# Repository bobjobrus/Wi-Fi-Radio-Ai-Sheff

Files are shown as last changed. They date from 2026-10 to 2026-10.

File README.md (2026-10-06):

**Русский** · [English](README.en.md)

# Wi-Fi Radio Ai-Sheff

**English summary.** Wi-Fi Radio Ai-Sheff is an open-source, battery-powered push-to-talk walkie-talkie built on
an ESP32-S3 DevKitC-1 with an INMP441 I2S microphone, a MAX98357A I2S amplifier, a 12-LED WS2812 ring, a KY-040
volume knob and an 18650 cell in a 3D-printed case. Radios join any 2.4 GHz Wi-Fi network and talk to each other
through a small *bridge* — a Python 3 server (two files, standard library only) that runs on a cheap VPS
or an always-on PC (Linux, Windows, macOS) — so the range is limited only by where there is Wi-Fi with internet.
Speech is 16 kHz IMA ADPCM; every packet is signed and the audio is AES-128-CTR encrypted with a shared network key,
and the bridge forwards speech without decrypting it. Radios update their firmware over the air from the bridge,
cancel acoustic howling between radios in the same room, and are configured from a phone through their own
`RADIO-XXXX` access point. Two bridges can be linked so that each site keeps working on its own LAN.
Full English documentation: [README.en.md](README.en.md). Code comments are in Russian. License: MIT.

---

## Что это

Переносная рация «нажал — говоришь» на плате ESP32-S3. Кнопка одна: нажали, услышали короткое «пи-пи»,
говорите, отпустили — все остальные рации вашей сети вас услышали.

Рации не связываются друг с другом напрямую. Каждая подключается к обычному Wi-Fi — дома, в офисе, на раздаче
с телефона, — а речь передаёт через **мост**: маленькую программу на компьютере, который всегда включён и доступен
из интернета. Поэтому рации в разных городах слышат друг друга так же, как в соседних комнатах: **дальность
ограничена только тем, где есть Wi-Fi с интернетом**.

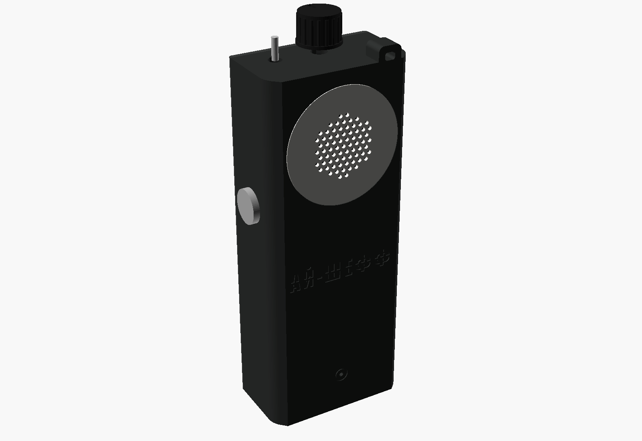
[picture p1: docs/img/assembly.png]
Рация в корпусе: динамик за белым диском, вокруг светится кольцо; кнопка «говорить» на боку, регулятор громкости и выключатель сверху


Корпус 68 × 38 × 170 мм печатается на 3D-принтере без поддержек. Спереди — динамик за белым диском, сквозь
который светится кольцо из 12 светодиодов; на боку — кнопка «говорить»; сверху — регулятор громкости и выключатель;
снизу — гнездо зарядки USB-C.

## Возможности

- **Одна кнопка «говорить».** Говорит один человек за раз: мост отдаёт эфир тому, кто нажал первым, остальные
  при нажатии слышат «бу-бу-бу» («занято»). Залипшую кнопку мост отключает через 90 секунд.
- **Рации в разных Wi-Fi-сетях** — дом, офис, склад, дача, раздача с телефона. Рация запоминает до трёх сетей
  и подключается к той, что ловит лучше. Нужен Wi-Fi 2,4 ГГц: сети 5 ГГц ESP32-S3 не видит.
- **Шифрование ключом сети.** Ключ сети — общий пароль всех ваших раций и мостов, строка вида
  `XXXX-XXXX-XXXX-XXXX`. Каждый пакет подписан этим ключом, речь зашифрована (AES-128). Чужая рация или случайный
  сканер из интернета в эфир не попадут. Мост речь не расшифровывает — только пересылает.
- **Обновление прошивки по воздуху через мост.** Положили новый файл прошивки в папку моста — каждая рация,
  простояв 20 секунд без разговоров, скачает его, сверит контрольную сумму (sha256 — «отпечаток» файла) и только
  тогда перезапустится на новую версию. Трогать рации руками не нужно.
- **Защита от свиста.** Если две рации лежат рядом, звук может пойти по кругу и засвистеть — как микрофон, поднесённый
  к колонке. Прошивка сама находит частоту свиста и вырезает её узким фильтром.
- **Индикация кольцом.** Кольцо вокруг динамика показывает связь, кто говорит, громкость, заряд и ход обновления.
  Что значит каждый цвет — в таблице [«Цвета кольца»](docs/TROUBLESHOOTING.md#цвета-кольца).
- **Оценка заряда** аккумулятора 18650: шкала на кольце, сигнал «пора на зарядку», процент на странице рации и на
  странице моста. Просадки напряжения во время разговора не дают ложных тревог.
- **Настройка с телефона.** Новая рация открывает свою точку доступа Wi-Fi `RADIO-XXXX`. Подключились к ней
  телефоном — страница настройки открывается сама, как в гостинице: Wi-Fi, адрес моста, ключ сети, имя рации,
  громкость, яркость.
- **Страница моста:** какие рации в сети, у кого сколько заряда, кто сейчас говорит, журнал событий. Мост сам
  подсказывает неисправности: «в передаче одна тишина — проверьте микрофон», «не тот ключ сети?».
- **Мост — программа на Python** без сторонних библиотек (два файла: `walkie_hub.py` и `wt_proto.py`): работает
  на Linux, Windows и macOS. Есть готовые
  установщики службы для Linux (systemd, с самопроверкой раз в 2 минуты) и для Windows (Планировщик заданий).
- **Звук:** 16 кГц, сжатие IMA ADPCM 4 бита — около 86 кбит/с на одного говорящего, хватает и мобильного интернета.
  Приёмник копит 60–160 мс речи, чтобы сгладить рывки сети.

## Как это работает

Рация шлёт речь кусочками по 20 мс в мост. Мост решает, кто сейчас в эфире, и пересылает речь всем остальным
рациям. Связь всегда начинает рация, поэтому настраивать роутеры у раций не нужно — входящие порты должны быть
открыты только у моста: **UDP 47000** (связь с рациями) и **TCP 47080** (страница состояния и раздача прошивки).

```
   Дом                                                               Офис
 ┌─────────┐  Wi-Fi  ┌────────┐                     ┌────────┐  Wi-Fi  ┌─────────┐
 │ рация 1 │ ~~~~~~~ │ роутер │───┐             ┌───│ роутер │ ~~~~~~~ │ рация 2 │
 └─────────┘         └────────┘   │  интернет   │   └────────┘         └─────────┘
                                  ▼             ▼
                            ┌───────────────────────┐
                            │         МОСТ          │  облачный сервер
                            │  UDP 47000 — рации    │  или компьютер
                            │  TCP 47080 — страница │  с постоянным адресом
                            └───────────────────────┘
                                          ▲
 ┌─────────┐  раздача Wi-Fi  ┌─────────┐  │
 │ рация 3 │ ~~~~~~~~~~~~~~~ │ телефон │──┘
 └─────────┘                 └─────────┘
```

Что происходит при нажатии кнопки:

1. Рация спрашивает мост: «можно говорить?». Эфир свободен — звучит «пи-пи», кольцо горит красным.
   Кто-то уже говорит — «бу-бу-бу», ждите.
2. Пока кнопка нажата, речь уходит в мост сжатой и зашифрованной.
3. Остальные рации играют её с небольшим запасом против рывков сети; их кольцо «пляшет» зелёным в такт голосу.
4. Отпустили кнопку — у остальных короткое «ти-ду»: передача закончена.

### Без облака

Мост можно поставить на компьютер в своей сети. Если поле «Адрес моста» в рации оставить пустым, рация сама найдёт
мост в своей сети широковещательным запросом (пакетом «всем в этой сети»).

```
 ┌───────┐  Wi-Fi  ┌────────┐     ┌──────────────┐
 │ рации │ ~~~~~~~ │ роутер │─────│ ПК с мостом  │    поле «Адрес моста» в рациях — пустое
 └───────┘         └────────┘     └──────────────┘
```

Если мест несколько, у каждого может быть свой мост, а мосты связываются между собой (поле `peers` в настройках
моста). Мостам нужно видеть друг друга по UDP 47000 — через интернет или через VPN (например, Tailscale или
WireGuard). Плюс такой схемы: внутри одного места рации говорят друг с другом даже при упавшем интернете.

```
 рации ~~~ [ мост «Дом» ] ◄═════ peers: интернет или VPN ═════► [ мост «Офис» ] ~~~ рации
```

Как выбрать и поднять мост — [docs/BRIDGE.md](docs/BRIDGE.md). Формат пакетов — [docs/protocol.md](docs/protocol.md).

## Что понадобится

| Деталь | Зачем |
|---|---|
| Плата ESP32-S3-DevKitC-1 N16R8 (или клон YD-ESP32-S3) | «мозг» рации и Wi-Fi |
| Микрофон INMP441 (цифровой, I2S) | голос |
| Усилитель MAX98357A (цифровой, I2S, 3 Вт) | усиливает звук для динамика |
| Динамик 8 Ом, 3 Вт, 32 × 32 мм | звук |
| Кольцо WS2812B на 12 светодиодов, Ø 50 мм | индикация |
| Регулятор KY-040 (вращающийся энкодер с кнопкой) | громкость; нажатие — выключить звук |
| Кнопка 16 мм (антивандальная) | «говорить» |
| Микротумблер | включение |
| Аккумулятор 18650 и держатель к нему | питание |
| Модуль заряда USB-C 5 В 2 А (типа «Power Bank Mini») | заряжает аккумулятор и даёт 5 В |
| Два резистора 100 кОм, диод 1N4007, две клеммы на 5 проводов, провода «мама-мама», термоусадка, саморезы 3 мм | делитель для измерения заряда, питание кольца, сборка |
| Корпус: ≈ 140 г PLA и белый диск динамика | печать на 3D-принтере, ≈ 6 ч |

**Цена одной рации — около 4 200 ₽** за детали и пластик, если собирать сразу три (одна рация отдельно — около
4 500 ₽: часть деталей продаётся наборами). Цены российских магазинов на сентябрь 2026. Точный список с количеством,
примерами «где можно купить» и размерами саморезов — в [docs/BUILD.md](docs/BUILD.md).

Ещё понадобятся паяльник, мультиметр (сильно упрощает поиск неисправностей), кабель USB-C **с передачей данных**
и компьютер, который будет мостом: недорогой облачный сервер или домашний ПК, который всегда включён.

Время работы от одного 18650 — по расчёту около 15 часов.

## Как собрать — по шагам

| Шаг | Где описано |
|---|---|
| 1. Купить детали, напечатать корпус, спаять и собрать | [docs/BUILD.md](docs/BUILD.md) — детали, печать, схема подключения ([wiring.svg](docs/img/wiring.svg)), раскладка в корпусе ([layout.svg](docs/img/layout.svg)) |
| 2. Поднять свой мост и придумать ключ сети | [docs/BRIDGE.md](docs/BRIDGE.md) |
| 3. Прошить рацию, ввести Wi-Fi, адрес моста и ключ, научиться пользоваться | [docs/SETUP.md](docs/SETUP.md) — готовая прошивка лежит в [firmware/dist/](firmware/dist/) |
| 4. Если что-то не работает | [docs/TROUBLESHOOTING.md](docs/TROUBLESHOOTING.md) — признак → причина → что делать |
| Для разработчиков: как устроены пакеты | [docs/protocol.md](docs/protocol.md) |

Совет: прошейте плату и проверьте её на столе **до** сборки в корпус — потом искать ошибку дольше.

## Что где лежит

| Папка / файл | Что внутри |
|---|---|
| [firmware/walkie/](firmware/walkie/) | прошивка рации (Arduino, ядро esp32 3.3.12). Выводы платы и основные числа — в [config.h](firmware/walkie/config.h) |
| [firmware/dist/](firmware/dist/) | готовая прошивка: `walkie-full-v9.bin` — первая прошивка целиком с адреса 0x0; `walkie.bin` + `walkie.json` — для раздачи через мост |
| [hub/walkie_hub.py](hub/walkie_hub.py) | мост; [wt_proto.py](hub/wt_proto.py) — протокол, [hub.example.json](hub/hub.example.json) — пример настроек |
| [hub/install_linux.sh](hub/install_linux.sh), [hub/install_windows.ps1](hub/install_windows.ps1) | установка моста службой на Linux и Windows |
| [hub/healthcheck.py](hub/healthcheck.py) | самопроверка моста (служебная «рация» стучится в мост) |
| [hub/sim_radio.py](hub/sim_radio.py) | программная рация на компьютере: проверить мост, передать тон или WAV, записать эфир, режим «попугай» |
| [tools/build_firmware.sh](tools/build_firmware.sh) | сборка прошивки через arduino-cli → `firmware/dist/` |
| [tools/flash.sh](tools/flash.sh) | первая прошивка по USB (macOS) |
| [tools/provision.py](tools/provision.py) | настройка рации по USB-кабелю: имя, мост, ключ, Wi-Fi (macOS; на Linux — с `--port`) |
| [tools/make_print.sh](tools/make_print.sh), [tools/bambu_profile.py](tools/bambu_profile.py) | нарезка корпуса в Bambu Studio под Bambu Lab P2S (macOS) |
| [tools/howl_eval.cpp](tools/howl_eval.cpp), [tools/howl_chain.cpp](tools/howl_chain.cpp) | стенды защиты от свиста: прогон по записям WAV и модель «петли» между рациями |
| [cad/radio_handheld.scad](cad/radio_handheld.scad) | модель корпуса в OpenSCAD (параметры — в шапке файла); [measurements.md](cad/measurements.md) — замеры деталей |
| [stl/](stl/) | готовые к печати детали корпуса |
| [tests/](tests/) | автоматические проверки моста, протокола и переносимой части прошивки |
| [docs/](docs/) | инструкции и картинки |

## Разработка

Проверки — без железа, около 30 секунд:

```bash
python3 -m unittest discover -s tests
```

Что проверяется (21 проверка): мост с «программными рациями» на настоящих UDP-сокетах — эфир, «занято», тишина,
отключение залипшей кнопки, чужой ключ, раздача прошивки, речь через два связанных моста, одновременное нажатие
в двух местах; шифр AES по эталонным векторам, подпись пакетов; совпадение констант протокола в прошивке и мосте.
Переносимые части прошивки (сжатие речи, буфер приёма, оценка заряда, защита от свиста) собираются компилятором
компьютера и проверяются своими тестами, а сжатие речи ещё и сверяется с эталоном на Python. Для этого нужен
`clang++` или `g++`, без них эти проверки пропускаются.

Сборка прошивки (нужен [arduino-cli](https://arduino.github.io/arduino-cli/); ядро esp32 3.3.12 скрипт поставит
сам):

```bash
tools/build_firmware.sh
```

Плата в сборке — «ESP32S3 Dev Module», флеш 4 МБ, разметка Minimal SPIFFS (два места под прошивку — нужно для
обновления по воздуху), PSRAM выключена, USB в режиме Hardware CDC. Подходит и платам с флешем 16 МБ.
Итог — в `firmware/dist/`.

Выпустить новую версию для всех раций:

1. Увеличьте `FW_VERSION` в [firmware/walkie/config.h](firmware/walkie/config.h) — мост раздаёт прошивку только
   с бо́льшим номером.
2. Соберите: `tools/build_firmware.sh`.
3. Скопируйте `firmware/dist/walkie.bin` и `firmware/dist/walkie.json` в папку `firmware/` рядом с `hub.json`
   на мосту. Мост подхватит их сам за 10 секунд — подробнее в [docs/BRIDGE.md](docs/BRIDGE.md).

Правила для тех, кто правит код:

- Протокол описан в двух местах — [firmware/walkie/protocol.h](firmware/walkie/protocol.h) и
  [hub/wt_proto.py](hub/wt_proto.py); менять их вместе (и описание в [docs/protocol.md](docs/protocol.md)),
  `tests/test_parity.py` сверяет константы.
- Сборка идёт без ctags, поэтому в `walkie.ino` функции объявляются **до** использования.
- Комментарии в коде — на русском.

## Лицензия

[MIT](LICENSE): можно использовать, менять и продавать, сохранив уведомление об авторских правах. Без гарантий.

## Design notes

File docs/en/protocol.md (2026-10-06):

[Русский](../protocol.md) · **English**

# The "WT1" radio protocol

A single UDP port on the bridge (default **47000**). The radio sends from its own port 47001.
Everything is little-endian. Code: `hub/wt_proto.py` (the reference) and `firmware/walkie/protocol.h` — **change them together**.

## Packet

```
'W' 'T' | version=1 (1) | type (1) | src (4) | data … | signature (8)
```

* `src` — the radio id (FNV-1a of the MAC) or the bridge id (sha256 of the bridge name).
* Signature — the first 8 bytes of HMAC-SHA256(k_auth, everything before the signature).
* Network key — a string like `K7Q2-MX9P-4RTA-W8HD`; case, spaces and hyphens don't matter.
  `k_auth = HMAC-SHA256(key, "wt1-auth")`, `k_enc = HMAC-SHA256(key, "wt1-enc")[:16]`.
* Exception: `BAD_KEY` (0x7F) — header only, no signature: this is how the bridge tells a radio
  that its signature didn't match ("wrong network key").

## Types

| Type | From → to | Data |
|---|---|---|
| `HELLO` 0x01 | radio → bridge, every 2 s (with no bridge — every 1 s, broadcast) | fw u16, flags u8 (1 = sound muted), rssi i8, t_ms u32, rtt u16, name (length u8 + UTF-8 ≤ 31), charge u8 (0–100 %, 255 — not on battery; optional) |
| `HELLO_ACK` 0x02 | bridge → radio | t_echo u32, radios on the network u8, bridges in the list u8, bridges online u8, channel busy u8, firmware version u16, size u32, sha256 32 bytes, http port u16, bridge name |
| `TALK_REQ` 0x10 | radio → bridge (repeated every 150 ms, for up to 700 ms) | burst u32 (random) |
| `TALK_GRANT` 0x11 | bridge → radio | burst u32 |
| `TALK_DENY` 0x12 | bridge → radio | burst u32, reason u8: 1 busy, 2 yield (simultaneous press), 3 held longer than 90 s, 4 the bridge doesn't know this radio |
| `TALK_END` 0x13 | radio → bridge (3 times); bridge → radios and bridges | burst u32; `src` = who was talking |
| `TALK_START` 0x14 | bridge → bridges | burst u32; `src` = who is talking |
| `AUDIO` 0x20 | radio → bridge → everyone | burst u32, seq u16, codec u8 (1), level u8, 163 bytes AES-128-CTR(k_enc) |
| `PEER_HELLO` 0x30 | bridge ↔ bridge, every 2 s | t_ms u32, t_echo u32, n u8, n × (id u32, flags u8, name), bridge name |

**Speech:** 16 kHz, 20 ms frame = 320 samples → 4-bit IMA ADPCM: `pred i16 | index u8 | 160 bytes`.
The encoder state is carried in every frame, so a lost packet doesn't corrupt the ones that follow.
AES-CTR counter: `src u32 | burst u32 | seq u16 | 6 zero bytes` (+1 for every 16 bytes, as in mbedtls).
The bridge doesn't decrypt speech: it forwards the packet as is.

## The channel (who is talking)

* The bridge gives the channel to whoever asked first; everyone else gets `DENY 1` and the busy tone.
* The channel is released on `TALK_END`, after 0.8 s without speech, or after 90 s (protection against a stuck button).
* Bridges pass `TALK_START`/`AUDIO` on to each other. If people in two places press at the same time,
  the **lower id** wins — identically on every bridge; the loser gets `DENY 2`.
* A bridge doesn't forward packets from one bridge to another (link the bridges as a "star" or as a full mesh, "each with each").

## Radio firmware updates

Put `firmware/walkie.bin` and `firmware/walkie.json` (`{"version": N}`) into the bridge's folder.
The bridge announces the version, size and sha256 in `HELLO_ACK`; the radio, after 20 s without any talking,
downloads `http://bridge:47080/fw/<first 16 characters of sha>.bin`, checks the sha256 and only then
switches to the new firmware. If it doesn't match — it retries in an hour.

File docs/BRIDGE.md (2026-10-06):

**Русский** · [English](en/BRIDGE.md)

# Свой мост

В публичной прошивке **адрес моста не задан**. Рации не услышат друг друга, пока вы не запустите
свой мост и не подключите их к нему. Здесь описано, как поднять мост на облачном сервере или на
домашнем компьютере, подключить к нему рации и обновлять их прошивку по воздуху.

Мост — это небольшая программа на Python (`hub/walkie_hub.py` и модуль `hub/wt_proto.py` рядом)
без дополнительных библиотек. Она одинаково работает на Linux, Windows и macOS.

**Содержание**

1. [Что такое мост и какой вариант выбрать](#1-что-такое-мост-и-какой-вариант-выбрать)
2. [Что понадобится](#2-что-понадобится)
3. [Ключ сети и токен страницы](#3-ключ-сети-и-токен-страницы)
4. [Установка на Linux-сервер](#4-установка-на-linux-сервер)
5. [Установка на Windows](#5-установка-на-windows)
6. [Подключение раций к мосту](#6-подключение-раций-к-мосту)
7. [Несколько мостов (поле peers)](#7-несколько-мостов-поле-peers)
8. [Страница состояния](#8-страница-состояния)
9. [Обновление прошивки по воздуху](#9-обновление-прошивки-по-воздуху)
10. [Проверка без раций](#10-проверка-без-раций)
11. [Безопасность](#11-безопасность)
12. [Если адрес сервера сменится](#12-если-адрес-сервера-сменится)
13. [Неполадки](#13-неполадки)

---

## 1. Что такое мост и какой вариант выбрать

Рации обычно стоят в разных Wi-Fi-сетях: дома, в офисе, на складе, в другом городе. Напрямую друг
друга они не видят. Каждая рация шлёт свои пакеты в мост, а мост:

- **решает, кто сейчас в эфире.** Первый нажавший получает эфир, остальные слышат сигнал «занято».
  Если кнопку держат дольше 90 секунд (по умолчанию), мост сам обрывает передачу (защита от залипшей
  кнопки);
- **пересылает речь** всем остальным рациям. Речь зашифрована ключом сети. Мост её не расшифровывает,
  а пересылает пакеты как есть;
- **раздаёт обновления прошивки.** Положили новый файл в папку моста, и рации обновятся сами;
- **показывает страницу состояния**: какие рации в сети, у кого сколько заряда, кто говорит, журнал
  событий.

Общаются рации с мостом по UDP. UDP — простой способ слать по интернету короткие пакеты без
установки соединения, для живого звука он подходит лучше всего.

### Три варианта

**А. Облачный сервер (VPS) — рекомендуемый.** VPS — это арендованный компьютер в дата-центре:
он всегда включён и доступен из интернета по постоянному адресу. В каждой рации вписан адрес
сервера, и рации работают из любой сети: дома, в офисе, через раздачу с телефона.

```
  Рация «Дом»      Рация «Офис»     Рация «Склад»
       \                |                /
        \___________ интернет __________/
                        |
          Мост на VPS: radio.example.com
```

**Б. Компьютер в той же сети, что рации.** Мост работает на обычном ПК дома или в офисе. Поле
«Адрес моста» в рациях остаётся **пустым**. Рация, у которой адрес не задан, сама ищет мост
в своей сети: рассылает приветствие всем устройствам сети (широковещательно) на порт 47000 и
запоминает тот мост, который ответил первым. Интернет не нужен. Но рации работают только в этой
сети, а компьютер должен быть всегда включён и не уходить в сон.

**В. Несколько мостов, связанных между собой.** У каждого места свой мост (вариант Б), и мосты
знают друг о друге через поле `peers` в настройках. Рация из одного места слышит рации из другого.
Мосты должны видеть друг друга по сети: через VPN (например, Tailscale), через проброс порта
в роутере или потому, что один из них стоит на VPS. Подробно — в разделе [7](#7-несколько-мостов-поле-peers).

| | А. VPS | Б. ПК в сети раций | В. Несколько мостов |
|---|---|---|---|
| Адрес моста в рации | адрес сервера | пусто | пусто (или адрес своего моста) |
| Рации в разных сетях | да | нет | да, между местами с мостами |
| Работает без интернета | нет | да | внутри одного места — да |
| Что должно быть включено | только сервер | ПК | все ПК с мостами |
| Расходы | аренда VPS | нет | нет (или VPS) |

Можно совмещать: мост на VPS для всех раций плюс мост в офисе, связанный с ним через `peers`
(см. [раздел 7](#7-несколько-мостов-поле-peers)).

---

## 2. Что понадобится

**Python 3.8 или новее.** Других пакетов не нужно, `pip install` делать не придётся. В Ubuntu и
Debian Python уже установлен (`/usr/bin/python3`). Для Windows скачайте его с python.org.

**Порты.** Порт — это номер «двери» на компьютере, через которую программа принимает пакеты.

| Порт | Протокол | Зачем | Где задан |
|---|---|---|---|
| **47000** | UDP | речь и служебные пакеты раций, связь мостов между собой | `port` в `hub.json` |
| **47080** | TCP | страница состояния и раздача прошивки рациям | `http_port` в `hub.json` |

Оба порта должны быть открыты на вход: и в брандмауэре самого компьютера, и (для VPS) в панели
провайдера. Рации сами шлют пакеты с порта 47001, открывать его на мосту не нужно.

**Постоянный адрес.** Рации знают мост по адресу. Если адрес сервера сменится, рации его потеряют
(см. [раздел 12](#12-если-адрес-сервера-сменится)). Поэтому нужен либо **статический IP-адрес**,
либо **доменное имя** (например, `radio.example.com`): рация понимает и цифровой адрес, и имя.

**IPv4.** Мост и рации работают только по IPv4. У некоторых дешёвых VPS есть только IPv6: такой не
подойдёт.

**Мощность.** Подойдёт самый маленький тариф VPS. Трафик тоже небольшой:

- в простое рация и мост обмениваются короткими пакетами раз в 2 секунды, это около 7 МБ в сутки
  на одну рацию;
- во время речи на каждую слушающую рацию уходит около 0,65 МБ в минуту (50 пакетов в секунду
  по 187 байт плюс заголовки сети).

---

## 3. Ключ сети и токен страницы

Придумайте их заранее: оба понадобятся при настройке моста.

### Ключ сети

Ключ сети — общий секрет всех раций и мостов одной сети. Им подписывается каждый пакет и шифруется
речь. Пакет с чужим ключом мост и рации просто выбрасывают.

Мост сам сгенерирует хороший ключ:

```bash
python3 hub/walkie_hub.py --genkey
```

Он напечатает строку вида `XXXX-XXXX-XXXX-XXXX`: 16 случайных знаков без похожих символов
(нет `0`/`O` и `1`/`I`).

Если придумываете ключ сами, соблюдайте правила:

- **не меньше 12 латинских букв и цифр.** Дефисы, пробелы и регистр не важны:
  `k7q2-mx9p…` и `K7Q2MX9P…` — один и тот же ключ;
- **только латиница и цифры.** Русские буквы прошивка рации пропускает, а мост учитывает, поэтому
  ключи разойдутся;
- **не длиннее 39 знаков** вместе с дефисами. Рация хранит не больше 39 знаков, и более длинный
  ключ она молча обрежет.

### Токен страницы состояния

Токен закрывает страницу состояния от посторонних: без него страница не откроется. Сгенерировать
его можно так:

```bash
python3 -c "import secrets; print(secrets.token_urlsafe(16))"
```

Используйте только латиницу, цифры, `-` и `_`, потому что токен будет частью адреса страницы.

---

## 4. Установка на Linux-сервер

Инструкция для Ubuntu и Debian. Ниже `203.0.113.10` — пример адреса сервера, а `ubuntu` — пример
имени пользователя. Подставьте свои.

### 4.1. Арендуйте сервер

Подойдёт любой провайдер VPS и самый маленький тариф с Ubuntu 22.04/24.04 или Debian 12.
При создании:

- **закажите статический (зарезервированный) публичный IPv4-адрес.** У многих провайдеров обычный
  адрес «плавающий» и меняется после остановки сервера;
- добавьте свой SSH-ключ, чтобы входить без пароля.

### 4.2. Откройте порты у провайдера

У большинства провайдеров есть свой сетевой фильтр («группа безопасности», «firewall», «правила
доступа»). Он работает отдельно от брандмауэра внутри сервера. Добавьте два входящих правила:

- UDP, порт **47000**, источник — любой (`0.0.0.0/0`);
- TCP, порт **47080**, источник — любой (`0.0.0.0/0`).

Правило для SSH (TCP 22) не удаляйте.

### 4.3. Скопируйте папку `hub` на сервер

Вариант 1: со своего компьютера, из корня этого проекта. Папки `walkie-hub` на сервере ещё не
должно быть:

```bash
scp -r hub ubuntu@203.0.113.10:~/walkie-hub
```

Вариант 2: на самом сервере, через `git clone` этого репозитория. Тогда папка моста — `hub`
внутри клона.

```bash
git clone <ссылка на этот репозиторий> ~/wifi-radio
# дальше вместо ~/walkie-hub используйте ~/wifi-radio/hub
```

В пути к папке не должно быть пробелов: установщик вписывает его в службу без кавычек.

### 4.4. Заполните `hub.json`

```bash
ssh ubuntu@203.0.113.10
cd ~/walkie-hub
cp hub.example.json hub.json
python3 walkie_hub.py --genkey                                  # ключ сети, если ещё нет
python3 -c "import secrets; print(secrets.token_urlsafe(16))"   # токен страницы
nano hub.json
```

Пример заполненного файла:

```json
{
  "name": "Облако",
  "port": 47000,
  "http_port": 47080,
  "key": "XXXX-XXXX-XXXX-XXXX",
  "peers": [],
  "status_token": "TOKEN",
  "tot_seconds": 90,
  "firmware_dir": "firmware",
  "log_file": "hub.log"
}
```

| Поле | Если не указано | Что значит |
|---|---|---|
| `name` | `Мост` | Имя моста. Его видно на странице рации и на странице состояния. Не длиннее 31 байта: это около 15 русских или 31 латинской буквы. **У каждого моста имя должно быть своё**: из имени вычисляется номер моста, и мосты с одинаковыми именами друг друга не видят. |
| `port` | `47000` | UDP-порт для раций. Для варианта Б оставьте 47000: рации ищут мост в сети только на этом порту. Если сменили, в рации пишите адрес с портом: `radio.example.com:47100`. |
| `http_port` | `47080` | TCP-порт страницы состояния и раздачи прошивки. Рации узнают его от моста сами. |
| `key` | — | **Обязательно.** Ключ сети из [раздела 3](#ключ-сети). Заглушку `ВСТАВЬТЕ-КЛЮЧ-СЕТИ` из примера замените: с ней мост запустится, но рации к нему не подключатся. Если ключ короче 12 знаков, мост не запустится. |
| `status_token` | пусто | Токен страницы состояния. Если пусто, страница открыта всем, кто знает адрес. |
| `tot_seconds` | `90` | Сколько секунд одна рация может держать эфир. Потом мост обрывает передачу. Рация и сама обрывает передачу через 100 секунд, поэтому ставить больше 100 нет смысла. |
| `peers` | `[]` | Другие мосты, с которыми связаться: `["адрес", "адрес:порт"]`. См. [раздел 7](#7-несколько-мостов-поле-peers). |
| `firmware_dir` | `firmware` | Папка для обновлений прошивки (`walkie.bin` + `walkie.json`). Путь считается от папки, где лежит `hub.json`. |
| `log_file` | `hub.log` | Журнал рядом с `hub.json`. Когда файл дорастает до 1 МБ, начинается новый, и хранятся 3 старых (`hub.log.1`…`hub.log.3`). Пустая строка `""` — не писать журнал в файл. |
| `listen` | `0.0.0.0` | На каком адресе компьютера слушать. В примере этого поля нет, и трогать его не нужно. `0.0.0.0` означает «на всех адресах». Самопроверка стучится на `127.0.0.1` и с другим значением не сработает. |

Файл должен быть правильным JSON: строки в двойных кавычках, между полями запятые, без запятой
после последнего поля, без комментариев.

### 4.5. Запустите установщик

```bash
cd ~/walkie-hub
sudo bash install_linux.sh
```

Что делает `install_linux.sh`:

1. Проверяет, что рядом есть `hub.json`. Если нет, останавливается с подсказкой.
2. Создаёт службу systemd **`walkie-hub`**. systemd — менеджер программ в Linux, который запускает
   их при включении сервера. Служба работает от вашего пользователя (не от root), запускает
   `python3 walkie_hub.py --config hub.json`, поднимается после перезагрузки сервера и
   перезапускается через 3 секунды, если программа упала.
3. Создаёт **самопроверку** `walkie-hub-check.timer`: через 3 минуты после включения, а потом раз
   в 2 минуты `healthcheck.py` шлёт мосту служебный пакет. Если мост не ответил (например, завис),
   служба перезапускается, а в системный журнал пишется «мост не ответил на самопроверку —
   перезапуск».
4. Если на сервере **включён** брандмауэр `ufw`, открывает в нём `47000/udp` и `47080/tcp`. Если
   `ufw` выключен, ничего не меняет и сам его не включает.
5. Запускает (или перезапускает) мост и показывает первые строки его состояния.

Скрипт можно запускать повторно, например после обновления файлов моста: он перезапишет службы и
перезапустит мост.

> Если `ufw` вы будете включать сами, сначала разрешите SSH (`sudo ufw allow OpenSSH`), иначе
> потеряете доступ к серверу. Если сменили порты в `hub.json`, откройте новые порты и в `ufw`, и
> у провайдера: установщик открывает только 47000 и 47080.

### 4.6. Проверьте

На сервере:

```bash
systemctl status walkie-hub             # должно быть active (running)
python3 healthcheck.py --config hub.json  # «мост отвечает»
tail -n 20 hub.log                      # «мост «Облако» запущен: UDP 47000, страница :47080, …»
```

Со своего компьютера откройте в браузере `http://203.0.113.10:47080/?t=TOKEN`. Должна открыться
страница «Мост раций «Облако»» с надписью «Ни одна рация сюда ещё не подключалась». Без `?t=…`
мост ответит «нужен ?t=<токен>».

Проверить, что UDP-порт открыт снаружи, можно программной рацией прямо со своего компьютера
(см. [раздел 10](#10-проверка-без-раций)):

```bash
python3 hub/sim_radio.py --hub 203.0.113.10 --key XXXX-XXXX-XXXX-XXXX status
```

### 4.7. Управление

```bash
sudo systemctl restart walkie-hub        # перезапуск, например после правки hub.json
sudo systemctl stop walkie-hub           # остановить
systemctl status walkie-hub              # состояние
journalctl -u walkie-hub -f              # журнал службы в реальном времени (выход — Ctrl+C)
tail -f ~/walkie-hub/hub.log             # тот же журнал из файла
journalctl -t walkie-hub                 # перезапуски по самопроверке
systemctl list-timers walkie-hub-check.timer
sudo systemctl disable --now walkie-hub walkie-hub-check.timer   # убрать из автозапуска
```

Мост читает `hub.json` только при запуске, поэтому после каждой правки нужен `restart`.

---

## 5. Установка на Windows

Подходит для варианта Б (ПК в сети раций) и В (мосты в разных местах).

1. Установите Python 3 с python.org. В установщике отметьте «Add python.exe to PATH» и оставьте
   включённым «py launcher».
2. Скопируйте папку `hub` в место без пробелов в пути, например `C:\walkie-hub`.
3. Скопируйте `hub.example.json` в `hub.json` и заполните его, как в [разделе 4.4](#44-заполните-hubjson).
   Подойдёт Блокнот, кодировка UTF-8. Ключ сгенерируйте так:
   ```powershell
   py -3 C:\walkie-hub\walkie_hub.py --genkey
   ```
4. Откройте **PowerShell от имени администратора** и запустите установщик:
   ```powershell
   powershell -ExecutionPolicy Bypass -File C:\walkie-hub\install_windows.ps1
   ```

Что делает `install_windows.ps1`:

- находит `pythonw.exe` (Python без чёрного окна) через PATH или через `py -3`;
- создаёт правила брандмауэра Windows «Мост раций UDP 47000» и «Мост раций TCP 47080» для всех
  типов сетей (доменной, частной, общественной). Старые правила с теми же именами сначала удаляет;
- регистрирует задачу Планировщика **`WalkieHub`**: запуск при включении компьютера (ещё до входа
  в систему, от имени SYSTEM), без окна, без ограничения по времени работы, в том числе от батареи
  ноутбука. Если программа завершится с ошибкой, Планировщик перезапускает её раз в минуту
  (до 999 раз);
- запускает задачу и через 3 секунды проверяет, что процесс работает. Если всё в порядке, пишет
  «Мост запущен (процесс …). Страница: http://localhost:47080/». Если нет — подсказывает заглянуть
  в `hub.log`.

На Windows нет самопроверки раз в 2 минуты, как на Linux. Чтобы проверить мост вручную:
`py -3 C:\walkie-hub\healthcheck.py --config C:\walkie-hub\hub.json`.

Управление (PowerShell от администратора):

```powershell
Stop-ScheduledTask  -TaskName WalkieHub        # остановить
Start-ScheduledTask -TaskName WalkieHub        # запустить (после правки hub.json: сначала Stop)
Get-ScheduledTask   -TaskName WalkieHub | Get-ScheduledTaskInfo
Get-Content C:\walkie-hub\hub.log -Tail 20 -Wait   # журнал в реальном времени
```

Страница состояния на этом же компьютере: `http://localhost:47080/?t=TOKEN`. С других устройств
сети — по адресу компьютера.

Чтобы мост был доступен всегда, отключите сон компьютера: «Параметры → Система → Питание».

Удалить мост:

```powershell
Unregister-ScheduledTask -TaskName WalkieHub -Confirm:$false
Remove-NetFirewallRule -DisplayName "Мост раций UDP 47000", "Мост раций TCP 47080"
```

### Запуск вручную (macOS, Linux, Windows)

Чтобы попробовать мост без установки, запустите его в окне терминала. Журнал будет прямо на
экране, остановка — Ctrl+C:

```bash
cd hub
cp hub.example.json hub.json     # и впишите ключ
python3 walkie_hub.py --config hub.json -v     # -v — подробный журнал
```

На Windows вместо `python3` пишите `py -3`, а вместо `cp` — `copy`.

На macOS при первом запуске система может спросить, разрешить ли Python входящие подключения:
разрешите.

---

## 6. Подключение раций к мосту

В каждой рации нужно задать два значения:

- **адрес моста** — IP или имя: `203.0.113.10` или `radio.example.com`. Порт можно не писать, если
  он стандартный (47000). Если нестандартный, пишите `radio.example.com:47100`. Для варианта Б
  оставьте поле пустым;
- **ключ сети** — тот же, что в `hub.json`.

### Через страницу рации (с телефона)

1. Откройте страницу настроек рации. Рация без ключа сети при включении сама открывает точку доступа
   `RADIO-XXXX`, даже если Wi-Fi у неё уже настроен. Подключитесь к ней телефоном, и страница
   откроется сама. Если рация уже в вашей сети Wi-Fi, страница доступна по адресу
   `http://radio-xxxx.local` (`xxxx` — те же 4 знака, что в имени точки доступа, только маленькими
   буквами). Точку доступа можно открыть и вручную: держите кнопку «говорить» и включите рацию.
   Подробнее — в [прошивке и настройке](SETUP.md#2-первая-настройка).
2. В разделе «Настройки» заполните поля **«Адрес моста»** и **«Ключ сети»** и нажмите
   **«Сохранить»**. Перезапускать рацию не нужно: она сразу начнёт искать новый мост.
3. Если ключ короче 12 букв и цифр, рация ответит «Сохранено, но ключ не принят: нужно не меньше 12
   букв и цифр».

Ключ на странице не показывается. Рядом с полем написано только «задан» или «не задан».
Оставьте поле пустым, если ключ менять не нужно.

### По USB-кабелю (macOS / Linux)

```bash
python3 tools/provision.py --name Склад --server radio.example.com --key XXXX-XXXX-XXXX-XXXX
python3 tools/provision.py --show          # проверить, что записалось
python3 tools/provision.py --server auto   # вернуть поиск моста в своей сети (вариант Б)
```

На macOS порт платы скрипт находит сам; если плат несколько, укажите `--port /dev/cu.usbmodem…`.
На Linux порт указывайте всегда: `--port /dev/ttyACM0` (или `/dev/ttyUSB0`).
На Windows скрипт не работает. Подключитесь к плате любым монитором порта на скорости 115200
(например, «Монитор порта» в Arduino IDE, конец строки — «Новая строка») и введите команды
(все команды — в [прошивке и настройке](SETUP.md#5-команды-по-usb)):

```
server radio.example.com
key XXXX-XXXX-XXXX-XXXX
show
```

### Как понять, что рация подключилась

- Рация издаёт сигнал «на связи», а кольцо коротко вспыхивает **зелёным** раз в 3 секунды
  (при питании от USB кольцо вместо вспышек тускло светится зелёным постоянно).
- На странице состояния моста рация появляется в таблице «Рации на этом мосту» как «в сети».
  Рядом видны её имя, заряд, сила Wi-Fi, задержка до моста и версия прошивки.

Что значит кольцо, если связи нет:

| Кольцо | Что происходит |
|---|---|
| два оранжевых огонька мигают | Wi-Fi есть, моста нет: неверный адрес, закрыт порт UDP, мост не запущен |
| красный и фиолетовый вперемешку | ключ не задан или не совпадает с ключом моста |
| янтарная вспышка вместо зелёной | связь с мостом есть, но один из мостов в `peers` недоступен |
| бегущий синий огонёк | рация ищет Wi-Fi |

### Свой адрес моста прямо в прошивке

Если раций много, адрес можно вписать в свою сборку прошивки, в `firmware/walkie/config.h`:

```c
#define DEFAULT_SERVER "radio.example.com"
```

Свежепрошитые рации сразу будут знать мост, останется ввести только ключ. Адрес, сохранённый
в памяти рации, важнее этого значения. Ключ в прошивку не вписывается: он хранится только
в памяти рации.

---

## 7. Несколько мостов (поле peers)

Мосты, связанные через `peers`, обмениваются служебными пакетами раз в 2 секунды. Мост пересылает
речь своих раций всем связанным мостам, а речь от связанного моста — только своим рациям.

Правила:

- **ключ сети у всех мостов один и тот же**, а **имена (`name`) разные**;
- в `peers` пишется адрес другого моста: IP или имя, с портом через двоеточие, если порт не 47000.
  Имена мост заново переводит в IP-адрес раз в 5 минут;
- **достаточно связи с одной стороны.** Если мост A знает адрес моста B, а B об A не знает, B всё
  равно примет A, ведь ключ у них общий. A тогда появится у B как незнакомый мост и будет забыт
  через минуту тишины. Поэтому мост за роутером (дома, в офисе) можно связать с мостом на VPS, не
  открывая портов в роутере: впишите адрес VPS в `peers` домашнего моста, а VPS-мосту ничего
  указывать не нужно;
- **мост не передаёт чужую речь дальше.** Если мостов три и больше, каждый должен быть связан
  с каждым. Например, два моста за роутерами, которые связаны только с VPS, друг друга не услышат:
  им нужна и прямая связь между собой (VPN или проброс порта);
- если нажали кнопку одновременно в двух местах, эфир получит одна и та же рация на всех мостах
  (у кого меньше номер). Вторая услышит «занято»;
- пока хотя бы один мост из списка недоступен, у раций вместо зелёной вспышки янтарная, а на
  странице состояния у этого моста написано «нет связи».

Пример: дома и в офисе по Windows-ПК с мостом, рации с пустым адресом моста, ПК связаны через
Tailscale. Tailscale — VPN с бесплатным тарифом для личного использования: он даёт каждому
компьютеру постоянный адрес в вашей личной сети. Адрес второго компьютера видно в приложении
Tailscale.

`hub.json` дома:

```json
{
  "name": "Дом",
  "key": "XXXX-XXXX-XXXX-XXXX",
  "peers": ["203.0.113.22"],
  "status_token": "TOKEN"
}
```

`hub.json` в офисе:

```json
{
  "name": "Офис",
  "key": "XXXX-XXXX-XXXX-XXXX",
  "peers": ["203.0.113.21"],
  "status_token": "TOKEN"
}
```

Здесь `203.0.113.21` (дом) и `203.0.113.22` (офис) — примеры адресов ПК в Tailscale. Хватило бы
и одной стороны, но с обеих надёжнее. Остальные поля можно не писать: подставятся значения по
умолчанию из таблицы в [разделе 4.4](#44-заполните-hubjson).
Если VPN гонит трафик через промежуточный сервер в другой стране, задержка вырастет, и речь будет
приходить с запаздыванием.

Для варианта Б и В важно:

- рация ищет мост только в **своей** подсети и только на порту 47000. Компьютер с мостом должен
  быть подключён к тому же роутеру. Гостевые сети с «изоляцией клиентов» такие поиски часто
  блокируют;
- в одной сети держите **один** мост: рация подключится к тому, кто ответил первым.

---

## 8. Страница состояния

Адрес: `http://АДРЕС:47080/?t=TOKEN`, например `http://radio.example.com:47080/?t=TOKEN`.
Страница обновляется сама каждые 5 секунд. На ней видно:

- имя моста, сколько он работает и какая прошивка лежит для раздачи;
- эфир: «эфир свободен» или «сейчас говорит …» (где и сколько секунд);
- **рации на этом мосту**: имя, номер, адрес, «в сети» / «говорит» / «нет связи», заряд (или
  «от сети» при питании от USB), сила Wi-Fi в дБм, задержка до моста, версия прошивки, «звук
  выключен»;
- **другие мосты** (если есть): на связи или нет, задержка, какие рации на них;
- **журнал**: последние 60 событий. Например: «в сети: Склад (…)», «эфир: говорит Офис», «🔋 Склад:
  аккумулятор 12% — пора на зарядку» (при 15 % и меньше), «⚠ Склад: в передаче одна тишина —
  проверьте микрофон», «⚠ пакет раций с неверной подписью от … — не тот ключ сети?».

Те же данные в машинном виде, например для своего мониторинга: `http://АДРЕС:47080/status.json?t=TOKEN`.

Рация считается пропавшей, если от неё 7 секунд не было пакетов. Сама рация шлёт приветствие раз
в 2 секунды и решает, что мост пропал, если 6,5 секунды не получала ответа.

---

## 9. Обновление прошивки по воздуху

Рации, которые уже работают с мостом, обновляются сами: не нужно ни разбирать их, ни подключать
кабель. Самую первую прошивку новой рации заливают по USB (см. [прошивку и настройку](SETUP.md#1-прошивка)).

### Как это устроено

- Мост при запуске и затем раз в 10 секунд заглядывает в папку `firmware_dir`. Там должны лежать
  `walkie.bin` (сама прошивка) и `walkie.json` с номером версии: `{"version": 10}`.
- В каждом ответе рации мост сообщает номер версии, размер файла и его контрольную сумму SHA-256.
  Это «отпечаток» файла: если изменится хоть один байт, отпечаток станет другим.
- Рация скачивает обновление, только если все условия выполнены:
  - номер версии на мосту **больше**, чем у неё (`FW_VERSION` в `firmware/walkie/config.h`);
  - эту же сборку она ещё не ставила;
  - **20 секунд** никто не нажимал её кнопку и в эфире никто не говорил.
- Рация скачивает `http://<IP моста>:47080/fw/<первые 16 знаков SHA-256>.bin`, сверяет размер
  и отпечаток, записывает прошивку и перезапускается. Пока идёт загрузка, кольцо показывает
  растущую синюю полосу. В журнале моста появляется запись «рация … скачивает прошивку 10».
- Если что-то не сошлось, рация остаётся на старой прошивке и пробует снова через час. Можно не
  ждать час: выключите и включите рацию.
- **Откатиться на более старую версию по воздуху нельзя**: рация не ставит номер меньше или равный
  своему. Чтобы вернуть старый код, соберите его с бо́льшим номером.

### Порядок действий

1. Увеличьте номер в `firmware/walkie/config.h`, например `#define FW_VERSION 10`.
2. Соберите прошивку (нужен `arduino-cli`):
   ```bash
   tools/build_firmware.sh
   ```
   В `firmware/dist/` появятся `walkie.bin` и `walkie.json` для моста, а также
   `walkie-full-v10.bin` для первой прошивки по USB. **Мосту нужен именно `walkie.bin`**, полный
   образ `walkie-full-…` по воздуху не встанет.
3. Скопируйте файлы на мост **в таком порядке: сначала `walkie.json`, потом `walkie.bin` под
   временным именем, и в конце переименуйте его**:
   ```bash
   ssh ubuntu@203.0.113.10 'mkdir -p ~/walkie-hub/firmware'
   scp firmware/dist/walkie.json ubuntu@203.0.113.10:~/walkie-hub/firmware/walkie.json
   scp firmware/dist/walkie.bin  ubuntu@203.0.113.10:~/walkie-hub/firmware/walkie.bin.new
   ssh ubuntu@203.0.113.10 'mv ~/walkie-hub/firmware/walkie.bin.new ~/walkie-hub/firmware/walkie.bin'
   ```
   На Windows-мосту то же самое в PowerShell:
   ```powershell
   New-Item -ItemType Directory -Force C:\walkie-hub\firmware | Out-Null
   Copy-Item firmware\dist\walkie.json C:\walkie-hub\firmware\walkie.json
   Copy-Item firmware\dist\walkie.bin  C:\walkie-hub\firmware\walkie.bin.new
   Move-Item -Force C:\walkie-hub\firmware\walkie.bin.new C:\walkie-hub\firmware\walkie.bin
   ```
4. В течение 10 секунд в журнале моста появится «прошивка для раций: версия 10, … КБ», а на
   странице состояния — «прошивка для раций: версия 10». Каждая рация начнёт обновляться, как только
   20 секунд не будет ни нажатий, ни разговоров в эфире. После перезапуска в колонке «Прошивка»
   появится новый номер.

**Почему важен порядок.** Мост перечитывает обе части, только когда меняется файл `walkie.bin`.
Если положить новый `walkie.bin` раньше `walkie.json`, мост может успеть прочитать новый файл со
старым номером версии, и рации обновляться не станут. Если такое случилось, перезапустите мост.
Временное имя нужно, чтобы мост не прочитал недокопированный файл: переименование происходит
мгновенно. Перед каждой отдачей мост сверяет файл с объявленным отпечатком. Если файл подменили
после того, как мост его прочитал, рация получит ошибку и попробует снова через час (или сразу после
выключения и включения), а мост перечитает файл.

Если в связанных мостах есть рации, обновление кладут в папку **каждого** моста: рация
скачивает прошивку только у своего.

Готовая прошивка из этого репозитория (`firmware/dist/walkie.bin` + `walkie.json`) тоже подходит
для раздачи: рации с таким же или бо́льшим номером её проигнорируют.

---

## 10. Проверка без раций

### Программная рация `sim_radio.py`

Притворяется рацией: подключается к мосту с компьютера, передаёт и слушает эфир. Нужен только
Python, запускается с любого компьютера:

```bash
cd hub
python3 sim_radio.py --hub radio.example.com --key XXXX-XXXX-XXXX-XXXX status
```

Ответ выглядит так (цифры для примера):

```
мост «Облако» ответил за 31 мс: раций в сети 3, мостов 0/0, прошивка для раций v10
```

| Команда | Что делает |
|---|---|
| `status` | подключиться и показать ответ моста: задержку, сколько раций в сети, сколько мостов на связи из указанных, версию прошивки для раздачи |
| `tone --seconds 3 [--hz 800]` | «нажать кнопку» и 3 секунды передавать тон 800 Гц: все рации его услышат |
| `say файл.wav` | передать запись: WAV 16 кГц, моно, 16 бит (`ffmpeg -i in.mp3 -ar 16000 -ac 1 out.wav`) |
| `listen --seconds 60 --out efir.wav` | слушать эфир 60 секунд, записать всё в WAV и показать для каждой передачи потери и разброс задержки |
| `echo --minutes 30 [--save папка]` | «попугай»: скажите что-нибудь в рацию и отпустите кнопку, и сказанное вернётся в эфир. Так проверяются микрофон, динамик и весь путь через мост. С `--save` каждая передача сохраняется в WAV |

Общие параметры: `--hub адрес[:порт]`, `--key`, `--name` (имя на странице моста, по умолчанию
«Компьютер»), `--id` (номер в шестнадцатеричном виде). Если запускаете две программные рации
одновременно, например `listen` в одном окне и `tone` в другом, дайте им разные номера:
`--id A1` и `--id A2`. Иначе мост примет их за одну рацию.

Программная рация появляется на странице состояния как обычная рация. Через 7 секунд после выхода
она получает отметку «нет связи», но строка остаётся в таблице до перезапуска моста (так же, как
у настоящих раций).

Что значат ошибки:

- «мост … не ответил за 5 с (адрес, порт UDP, брандмауэр, ключ?)» — пакеты не доходят. Проверьте
  адрес, службу на сервере, правило UDP 47000 у провайдера и в брандмауэре;
- «⚠ мост ответил: подпись не сошлась — не тот ключ сети» — мост доступен, но ключ другой. Следом
  программа напишет и «не ответил за 5 с»: причина та же, ищите её в ключе.

### Самопроверка `healthcheck.py`

Отправляет мосту служебный пакет и ждёт ответ до 3 секунд. Печатает «мост отвечает» (код
выхода 0) или «мост НЕ отвечает» (код 1). В список раций не попадает. Ключ и порт берёт
из `hub.json`:

```bash
python3 hub/healthcheck.py --config hub/hub.json                        # мост на этом компьютере
python3 hub/healthcheck.py --config hub/hub.json --host 203.0.113.10    # удалённый мост
```

---

## 11. Безопасность

**Что защищено.**

- Каждый пакет подписан ключом сети (HMAC-SHA256). Пакет без верной подписи мост и рации
  выбрасывают. Без ключа чужая рация или сканер из интернета в эфир не попадут.
- Речь зашифрована (AES-128) отдельным ключом, который вычисляется из ключа сети. Мост речь не
  расшифровывает. Перехватив пакеты по дороге, без ключа её не услышать.

**Что не защищено.**

- **Кто знает ключ, тот в сети**: может подключить свою рацию, говорить и слушать всё. Ключ хранится
  в `hub.json` каждого моста и в памяти каждой рации, незашифрованным. Если потеряли рацию или ключ
  попал к чужим, смените ключ.
- Имена раций, заряд, версия прошивки и служебные пакеты подписаны, но **не зашифрованы**.
- Страница состояния работает по обычному HTTP, без шифрования, и токен передаётся в адресе
  открытым текстом. Это защита от случайных посетителей, а не от того, кто перехватывает ваш
  трафик. Не используйте как токен пароль от чего-то другого.
- Страница настроек рации без пароля: любой в той же Wi-Fi-сети может её открыть, поменять
  настройки и загрузить в рацию другую прошивку. Ключ сети она при этом не показывает.
- Файл прошивки для раций (`/fw/…` на порту 47080) мост отдаёт без токена. Не вписывайте в свою
  сборку прошивки ничего секретного. Ключ сети в прошивку не попадает.

**Правила.**

- Не публикуйте `hub.json`, ссылку со своим токеном и скриншоты с ключом. Файлы `hub/hub.json`,
  `hub/hub.log*` и `hub/firmware/` уже внесены в `.gitignore`, поэтому git их не отправит
  на GitHub.
- Задайте `status_token`: без него любой, кто знает адрес, видит имена раций и их IP-адреса.
- Входите на сервер по SSH-ключу и обновляйте систему (`sudo apt update && sudo apt upgrade`).
- **Смена ключа:** сгенерируйте новый, впишите его в `hub.json` каждого моста и перезапустите их.
  Затем введите новый ключ в каждую рацию: через страницу или `provision.py --key`. Пока ключ не
  обновлён, рация показывает красный с фиолетовым, а в журнале моста появляется «пакет раций с
  неверной подписью». Сброс настроек кнопкой регулятора (держать 10 секунд) ключ, имя и адрес
  моста не стирает. Их стирает только полный сброс командой `factory` по USB.

---

## 12. Если адрес сервера сменится

Рация знает мост по адресу. Если IP сервера сменился, а в рациях вписан старый IP:

- рации теряют мост: два оранжевых огонька, говорить нельзя;
- **сообщить им новый адрес через мост невозможно**: и обновления, и связь идут через него же.
  Придётся вписать новый адрес в каждую рацию вручную (страница рации или `provision.py --server`).

Как этого избежать:

1. **Закрепите адрес** у провайдера: «статический» или «зарезервированный» IP. Сделайте это до
   того, как раздадите рации. Иногда за это берут небольшую доплату.
2. **Ещё надёжнее — доменное имя.** Заведите у регистратора домена запись типа A (например,
   `radio.example.com` → `203.0.113.10`) и впишите в рации имя, а не цифры. Рация заново
   узнаёт IP по имени при сохранении настроек, раз в 15 секунд, пока моста нет, и раз в 10 минут,
   пока связь есть. Если адрес сменится, достаточно поправить запись у регистратора: рации сами
   найдут мост, как только обновится DNS. Так же раз в 5 минут обновляют адреса мосты, у которых
   в `peers` указаны имена. Если переезд планируется, заранее уменьшите время жизни записи (TTL)
   до 5 минут.

**Переезд на другой сервер.** Перенесите `hub.json` без изменений (тот же ключ и то же имя) и
папку `firmware`. Установите мост на новом сервере и поменяйте адрес в A-записи домена. Рации
настраивать заново не придётся.

---

## 13. Неполадки

Ошибки при запуске моста видно в `journalctl -u walkie-hub`. На Windows мост работает без окна,
поэтому для поиска ошибки остановите задачу (`Stop-ScheduledTask -TaskName WalkieHub`) и запустите
мост вручную: `py -3 C:\walkie-hub\walkie_hub.py --config C:\walkie-hub\hub.json`.

| Что видно | Что проверить |
|---|---|
| `sim_radio.py … status`: «не ответил за 5 с» | Работает ли служба (`systemctl status walkie-hub`); открыт ли UDP 47000 у провайдера и в `ufw` (Windows: правила брандмауэра); тот ли адрес; есть ли у сервера IPv4 |
| «подпись не сошлась — не тот ключ сети» | Ключ в рации или в `--key` не совпадает с `hub.json`. Проверьте на лишние и русские буквы, длину не больше 39 знаков |
| Мост не запускается: `ключ сети слишком короткий` | В `key` меньше 12 букв и цифр |
| Мост не запускается: `JSONDecodeError` | Ошибка в `hub.json`: лишняя или недостающая запятая, кавычки |
| Мост не запускается: `Address already in use` | Порт занят: мост уже запущен (служба и ручной запуск одновременно) или порт занят другой программой |
| Страница не открывается | Открыт ли TCP 47080 у провайдера и в брандмауэре; не забыт ли `?t=TOKEN` (без него — «нужен ?t=<токен>») |
| Рация: два оранжевых огонька | Адрес моста в рации, порт, брандмауэр. В варианте Б — компьютер с мостом в той же подсети, `port` 47000, одна сеть без изоляции клиентов |
| Рация: красный с фиолетовым | Ключ не задан или не совпадает |
| Рация: янтарная вспышка | Недоступен один из мостов в `peers`. Смотрите раздел «Другие мосты» на странице состояния |
| Мосты не видят друг друга | Одинаковый `name` у двух мостов; разные ключи; адрес в `peers`; UDP 47000 между ними |
| Рации не обновляются | Номер в `walkie.json` должен быть больше, чем у раций; открыт ли TCP 47080 (рация качает по нему); лежит ли `walkie.bin` (не `walkie-full-…`); файлы копировали в правильном порядке (иначе перезапустите мост); рацию 20 секунд не трогали; после неудачи рация ждёт час (или выключите и включите её) |
| В журнале «в передаче одна тишина» | У рации, скорее всего, отключился или неправильно подключён микрофон |

Как устроены пакеты, подписи и шифрование, описано в [описании протокола](protocol.md).

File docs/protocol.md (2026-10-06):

**Русский** · [English](en/protocol.md)

# Протокол раций «WT1»

Один UDP-порт моста (по умолчанию **47000**). Рация шлёт со своего порта 47001.
Всё little-endian. Код: `hub/wt_proto.py` (эталон) и `firmware/walkie/protocol.h` — **менять вместе**.

## Пакет

```
'W' 'T' | версия=1 (1) | тип (1) | src (4) | данные … | подпись (8)
```

* `src` — id рации (FNV-1a от MAC) или id моста (sha256 от имени моста).
* Подпись — первые 8 байт HMAC-SHA256(k_auth, всё до подписи).
* Ключ сети — строка вроде `K7Q2-MX9P-4RTA-W8HD`; регистр, пробелы и дефисы не важны.
  `k_auth = HMAC-SHA256(ключ, "wt1-auth")`, `k_enc = HMAC-SHA256(ключ, "wt1-enc")[:16]`.
* Исключение: `BAD_KEY` (0x7F) — только заголовок, без подписи: мост так подсказывает рации,
  что её подпись не сошлась («не тот ключ сети»).

## Типы

| Тип | Кто → кому | Данные |
|---|---|---|
| `HELLO` 0x01 | рация → мост, раз в 2 с (без моста — раз в 1 с, широковещательно) | fw u16, flags u8 (1 = звук выключен), rssi i8, t_ms u32, rtt u16, имя (длина u8 + UTF-8 ≤ 31), заряд u8 (0–100 %, 255 — не от аккумулятора; необязательный) |
| `HELLO_ACK` 0x02 | мост → рация | t_echo u32, раций в сети u8, мостов в списке u8, мостов на связи u8, эфир занят u8, версия прошивки u16, размер u32, sha256 32 байта, http-порт u16, имя моста |
| `TALK_REQ` 0x10 | рация → мост (повтор каждые 150 мс, до 700 мс) | burst u32 (случайный) |
| `TALK_GRANT` 0x11 | мост → рация | burst u32 |
| `TALK_DENY` 0x12 | мост → рация | burst u32, причина u8: 1 занято, 2 уступи (одновременное нажатие), 3 держит дольше 90 с, 4 мост не знает рацию |
| `TALK_END` 0x13 | рация → мост (3 раза); мост → рации и мосты | burst u32; `src` = кто говорил |
| `TALK_START` 0x14 | мост → мосты | burst u32; `src` = кто говорит |
| `AUDIO` 0x20 | рация → мост → все | burst u32, seq u16, кодек u8 (1), уровень u8, 163 байта AES-128-CTR(k_enc) |
| `PEER_HELLO` 0x30 | мост ↔ мост, раз в 2 с | t_ms u32, t_echo u32, n u8, n × (id u32, flags u8, имя), имя моста |

**Речь:** 16 кГц, кадр 20 мс = 320 отсчётов → IMA ADPCM 4 бит: `pred i16 | index u8 | 160 байт`.
Состояние кодера в каждом кадре — потеря пакета не портит следующие.
Счётчик AES-CTR: `src u32 | burst u32 | seq u16 | 6 нулей` (+1 на каждые 16 байт, как в mbedtls).
Мост речь не расшифровывает: пересылает пакет как есть.

## Эфир (кто говорит)

* Мост даёт эфир первому, кто попросил; остальным — `DENY 1` и сигнал «занято».
* Эфир освобождается по `TALK_END`, через 0,8 с без речи или через 90 с (защита от залипшей кнопки).
* Мосты сообщают друг другу `TALK_START`/`AUDIO`. Если нажали одновременно в двух местах,
  побеждает **меньший id** — одинаково на всех мостах; проигравшему — `DENY 2`.
* Мост не пересылает пакеты от одного моста другому (сеть «звездой» или «каждый с каждым»).

## Обновление прошивки раций

Положить в папку моста `firmware/walkie.bin` и `firmware/walkie.json` (`{"version": N}`).
Мост объявляет версию, размер и sha256 в `HELLO_ACK`; рация, простояв 20 с без разговоров,
скачивает `http://мост:47080/fw/<первые 16 знаков sha>.bin`, сверяет sha256 и только тогда
переключается на новую прошивку. Не сошлось — повтор через час.

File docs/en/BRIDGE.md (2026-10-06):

[Русский](../BRIDGE.md) · **English**

# Your own bridge

The public firmware has **no bridge address set**. The radios won't hear each other until you run
your own bridge and connect them to it. This page explains how to set up a bridge on a cloud server
or on a home computer, connect radios to it and update their firmware over the air.

The bridge is a small Python program (`hub/walkie_hub.py` plus the `hub/wt_proto.py` module next to
it) with no extra libraries. It works the same way on Linux, Windows and macOS.

**Contents**

1. [What the bridge is and which option to choose](#1-what-the-bridge-is-and-which-option-to-choose)
2. [What you need](#2-what-you-need)
3. [Network key and page token](#3-network-key-and-page-token)
4. [Installing on a Linux server](#4-installing-on-a-linux-server)
5. [Installing on Windows](#5-installing-on-windows)
6. [Connecting radios to the bridge](#6-connecting-radios-to-the-bridge)
7. [Multiple bridges (the peers field)](#7-multiple-bridges-the-peers-field)
8. [Status page](#8-status-page)
9. [Over-the-air firmware updates](#9-over-the-air-firmware-updates)
10. [Testing without radios](#10-testing-without-radios)
11. [Security](#11-security)
12. [If the server address changes](#12-if-the-server-address-changes)
13. [Troubleshooting](#13-troubleshooting)

---

## 1. What the bridge is and which option to choose

The radios usually sit on different Wi-Fi networks: at home, in the office, in a warehouse, in
another city. They can't see each other directly. Each radio sends its packets to the bridge, and
the bridge:

- **decides who is on the channel right now.** The first one to press gets the channel; the others
  hear the busy tone. If the button is held longer than 90 seconds (by default), the bridge cuts the
  transmission itself (protection against a stuck button);
- **forwards speech** to all the other radios. Speech is encrypted with the network key. The bridge
  doesn't decrypt it; it forwards the packets as they are;
- **distributes firmware updates.** Put a new file into the bridge's folder, and the radios update
  themselves;
- **shows a status page**: which radios are online, how much battery each has, who is talking, an
  event log.

The radios talk to the bridge over UDP. UDP is a simple way to send short packets over the internet
without setting up a connection; it's the best fit for live audio.

### Three options

**A. Cloud server (VPS) — recommended.** A VPS is a rented computer in a data centre: it's always on
and reachable from the internet at a fixed address. Each radio has the server address entered, and
the radios work from any network: at home, in the office, over a phone hotspot.

```
  Radio "Home"     Radio "Office"   Radio "Warehouse"
       \                |                /
        \___________ internet __________/
                        |
          Bridge on a VPS: radio.example.com
```

**B. A computer on the same network as the radios.** The bridge runs on an ordinary PC at home or in
the office. The «Адрес моста» (Bridge address) field on the radios stays **empty**. A radio with no
address set looks for a bridge on its own network: it broadcasts a hello to every device on the
network on port 47000 and remembers the bridge that answers first. No internet is needed. But the
radios only work on that network, and the computer must always be on and never go to sleep.

**C. Several bridges linked together.** Each location has its own bridge (option B), and the bridges
know about each other through the `peers` field in their settings. A radio in one location hears the
radios in another. The bridges must be able to reach each other over the network: through a VPN (for
example, Tailscale), through port forwarding on the router, or because one of them is on a VPS.
Details are in [section 7](#7-multiple-bridges-the-peers-field).

| | A. VPS | B. PC on the radios' network | C. Multiple bridges |
|---|---|---|---|
| Bridge address in the radio | server address | empty | empty (or the address of its own bridge) |
| Radios on different networks | yes | no | yes, between locations with bridges |
| Works without internet | no | yes | within one location — yes |
| What must be switched on | only the server | the PC | every PC with a bridge |
| Cost | VPS rental | none | none (or a VPS) |

You can combine them: a bridge on a VPS for all radios plus a bridge in the office linked to it via
`peers` (see [section 7](#7-multiple-bridges-the-peers-field)).

---

## 2. What you need

**Python 3.8 or newer.** No other packages are needed; you won't have to run `pip install`. Ubuntu and
Debian already have Python installed (`/usr/bin/python3`). For Windows, download it from python.org.

**Ports.** A port is the number of a "door" on the computer through which a program receives packets.

| Port | Protocol | Purpose | Where it's set |
|---|---|---|---|
| **47000** | UDP | speech and service packets from radios, bridge-to-bridge links | `port` in `hub.json` |
| **47080** | TCP | status page and firmware downloads for radios | `http_port` in `hub.json` |

Both ports must be open for incoming traffic: in the computer's own firewall and (for a VPS) in the
provider's control panel. The radios send their packets from port 47001; you don't need to open it
on the bridge.

**A fixed address.** The radios know the bridge by its address. If the server address changes, the
radios lose it (see [section 12](#12-if-the-server-address-changes)). So you need either a **static
IP address** or a **domain name** (for example, `radio.example.com`): the radio understands both a
numeric address and a name.

**IPv4.** The bridge and the radios work over IPv4 only. Some cheap VPS plans come with IPv6 only:
those won't do.

**Resources.** The smallest VPS plan is enough. Traffic is small too:

- when idle, a radio and the bridge exchange short packets every 2 seconds, which is about 7 MB per
  day per radio;
- while someone is talking, each listening radio receives about 0.65 MB per minute (50 packets per
  second of 187 bytes each, plus network headers).

---

## 3. Network key and page token

Come up with both in advance: you'll need them when setting up the bridge.

### Network key

The network key is a secret shared by all radios and bridges of one network. Every packet is signed
with it and speech is encrypted with it. The bridge and the radios simply drop packets with a
different key.

The bridge can generate a good key for you:

```bash
python3 hub/walkie_hub.py --genkey
```

It prints a string like `XXXX-XXXX-XXXX-XXXX`: 16 random characters without look-alike symbols
(no `0`/`O` and no `1`/`I`).

If you make up a key yourself, follow these rules:

- **at least 12 Latin letters and digits.** Hyphens, spaces and letter case don't matter:
  `k7q2-mx9p…` and `K7Q2MX9P…` are the same key;
- **Latin letters and digits only.** The radio firmware skips Cyrillic letters but the bridge counts
  them, so the keys would no longer match;
- **no longer than 39 characters** including hyphens. The radio stores at most 39 characters and
  silently truncates a longer key.

### Status page token

The token keeps strangers out of the status page: without it the page won't open. You can generate
one like this:

```bash
python3 -c "import secrets; print(secrets.token_urlsafe(16))"
```

Use only Latin letters, digits, `-` and `_`, because the token becomes part of the page address.

---

## 4. Installing on a Linux server

These instructions are for Ubuntu and Debian. Below, `203.0.113.10` is an example server address and
`ubuntu` is an example user name. Substitute your own.

### 4.1. Rent a server

Any VPS provider will do, with the smallest plan running Ubuntu 22.04/24.04 or Debian 12. When
creating it:

- **order a static (reserved) public IPv4 address.** With many providers the regular address is
  "floating" and changes after the server is stopped;
- add your SSH key so you can log in without a password.

### 4.2. Open the ports at the provider

Most providers have their own network filter ("security group", "firewall", "access rules"). It
works separately from the firewall inside the server. Add two inbound rules:

- UDP, port **47000**, source — any (`0.0.0.0/0`);
- TCP, port **47080**, source — any (`0.0.0.0/0`).

Don't delete the SSH rule (TCP 22).

### 4.3. Copy the `hub` folder to the server

Option 1: from your own computer, from the root of this project. The `walkie-hub` folder must not
exist on the server yet:

```bash
scp -r hub ubuntu@203.0.113.10:~/walkie-hub
```

Option 2: on the server itself, with `git clone` of this repository. Then the bridge folder is `hub`
inside the clone.

```bash
git clone <link to this repository> ~/wifi-radio
# from here on, use ~/wifi-radio/hub instead of ~/walkie-hub
```

The folder path must not contain spaces: the installer writes it into the service without quotes.

### 4.4. Fill in `hub.json`

```bash
ssh ubuntu@203.0.113.10
cd ~/walkie-hub
cp hub.example.json hub.json
python3 walkie_hub.py --genkey                                  # network key, if you don't have one yet
python3 -c "import secrets; print(secrets.token_urlsafe(16))"   # page token
nano hub.json
```

Example of a filled-in file:

```json
{
  "name": "Cloud",
  "port": 47000,
  "http_port": 47080,
  "key": "XXXX-XXXX-XXXX-XXXX",
  "peers": [],
  "status_token": "TOKEN",
  "tot_seconds": 90,
  "firmware_dir": "firmware",
  "log_file": "hub.log"
}
```

(The bundled `hub.example.json` uses the Russian name `"Облако"`, which means "Cloud". Any name
within the limits in the table below will do.)

| Field | Default | Meaning |
|---|---|---|
| `name` | `Мост` ("Bridge") | Bridge name. It's shown on the radio's page and on the status page. At most 31 bytes: that's about 15 Cyrillic or 31 Latin letters. **Every bridge must have its own name**: the bridge number is derived from the name, and bridges with the same name can't see each other. |
| `port` | `47000` | UDP port for the radios. For option B leave it at 47000: radios search for a bridge on the network only on this port. If you change it, enter the address with the port in the radio: `radio.example.com:47100`. |
| `http_port` | `47080` | TCP port of the status page and firmware downloads. The radios learn it from the bridge automatically. |
| `key` | — | **Required.** The network key from [section 3](#network-key). Replace the placeholder `ВСТАВЬТЕ-КЛЮЧ-СЕТИ` ("INSERT-NETWORK-KEY") from the example: with it the bridge starts, but the radios won't connect to it. If the key is shorter than 12 characters, the bridge won't start. |
| `status_token` | empty | Status page token. If empty, the page is open to anyone who knows the address. |
| `tot_seconds` | `90` | How many seconds one radio may hold the channel. After that the bridge cuts the transmission. The radio itself cuts the transmission after 100 seconds, so there's no point setting more than 100. |
| `peers` | `[]` | Other bridges to link with: `["address", "address:port"]`. See [section 7](#7-multiple-bridges-the-peers-field). |
| `firmware_dir` | `firmware` | Folder for firmware updates (`walkie.bin` + `walkie.json`). The path is relative to the folder containing `hub.json`. |
| `log_file` | `hub.log` | Log file next to `hub.json`. When the file reaches 1 MB a new one is started, and 3 old ones are kept (`hub.log.1`…`hub.log.3`). An empty string `""` means don't write the log to a file. |
| `listen` | `0.0.0.0` | Which of the computer's addresses to listen on. The example doesn't include this field, and you don't need to touch it. `0.0.0.0` means "on all addresses". The self-check connects to `127.0.0.1` and won't work with any other value. |

The file must be valid JSON: strings in double quotes, commas between fields, no comma after the last
field, no comments.

### 4.5. Run the installer

```bash
cd ~/walkie-hub
sudo bash install_linux.sh
```

What `install_linux.sh` does:

1. Checks that `hub.json` is present next to it. If not, it stops with a hint.
2. Creates the systemd service **`walkie-hub`**. systemd is the Linux program manager that starts
   programs when the server boots. The service runs as your user (not as root), starts
   `python3 walkie_hub.py --config hub.json`, comes back up after a server reboot and restarts after
   3 seconds if the program crashes.
3. Creates the **self-check** `walkie-hub-check.timer`: 3 minutes after boot, and then every
   2 minutes, `healthcheck.py` sends the bridge a service packet. If the bridge doesn't answer (for
   example, it has hung), the service is restarted and the system log gets the message «мост не
   ответил на самопроверку — перезапуск» ("bridge did not answer the self-check — restarting").
4. If the `ufw` firewall is **enabled** on the server, opens `47000/udp` and `47080/tcp` in it. If
   `ufw` is disabled, it changes nothing and does not enable it.
5. Starts (or restarts) the bridge and shows the first lines of its status.

You can run the script again, for example after updating the bridge files: it rewrites the services
and restarts the bridge.

> If you enable `ufw` yourself, allow SSH first (`sudo ufw allow OpenSSH`), or you'll lose access to
> the server. If you changed the ports in `hub.json`, open the new ports both in `ufw` and at the
> provider: the installer only opens 47000 and 47080.

### 4.6. Check

On the server:

```bash
systemctl status walkie-hub             # should be active (running)
python3 healthcheck.py --config hub.json  # «мост отвечает» ("bridge is responding")
tail -n 20 hub.log                      # «мост «Cloud» запущен: UDP 47000, страница :47080, …» ("bridge 'Cloud' started: UDP 47000, page :47080, …")
```

From your own computer, open `http://203.0.113.10:47080/?t=TOKEN` in a browser. You should see the
page «Мост раций «Cloud»» ("Radio bridge 'Cloud'") with the text «Ни одна рация сюда ещё не
подключалась» ("No radio has connected here yet"). Without `?t=…` the bridge replies «нужен
?t=<токен>» ("?t=<token> required").

You can check that the UDP port is open from the outside with the software radio, right from your own
computer (see [section 10](#10-testing-without-radios)):

```bash
python3 hub/sim_radio.py --hub 203.0.113.10 --key XXXX-XXXX-XXXX-XXXX status
```

### 4.7. Managing the bridge

```bash
sudo systemctl restart walkie-hub        # restart, e.g. after editing hub.json
sudo systemctl stop walkie-hub           # stop
systemctl status walkie-hub              # status
journalctl -u walkie-hub -f              # live service log (exit with Ctrl+C)
tail -f ~/walkie-hub/hub.log             # the same log from the file
journalctl -t walkie-hub                 # restarts triggered by the self-check
systemctl list-timers walkie-hub-check.timer
sudo systemctl disable --now walkie-hub walkie-hub-check.timer   # remove from autostart
```

The bridge reads `hub.json` only at startup, so every edit needs a `restart`.

---

## 5. Installing on Windows

Suitable for option B (a PC on the radios' network) and option C (bridges in different locations).

1. Install Python 3 from python.org. In the installer, tick "Add python.exe to PATH" and leave
   "py launcher" enabled.
2. Copy the `hub` folder to a location with no spaces in the path, for example `C:\walkie-hub`.
3. Copy `hub.example.json` to `hub.json` and fill it in as in [section 4.4](#44-fill-in-hubjson).
   Notepad is fine; save it as UTF-8. Generate the key like this:
   ```powershell
   py -3 C:\walkie-hub\walkie_hub.py --genkey
   ```
4. Open **PowerShell as administrator** and run the installer:
   ```powershell
   powershell -ExecutionPolicy Bypass -File C:\walkie-hub\install_windows.ps1
   ```

What `install_windows.ps1` does:

- finds `pythonw.exe` (Python without the black console window) via PATH or via `py -3`;
- creates the Windows Firewall rules «Мост раций UDP 47000» and «Мост раций TCP 47080» ("Radio
  bridge UDP 47000" / "Radio bridge TCP 47080") for all network types (domain, private, public).
  Old rules with the same names are removed first;
- registers the Task Scheduler task **`WalkieHub`**: it starts when the computer boots (even before
  anyone logs in, as SYSTEM), without a window, with no run-time limit, including on laptop battery
  power. If the program exits with an error, Task Scheduler restarts it once a minute (up to 999
  times);
- starts the task and, 3 seconds later, checks that the process is running. If all is well, it prints
  «Мост запущен (процесс …). Страница: http://localhost:47080/» ("Bridge started (process …). Page:
  http://localhost:47080/"). If not, it suggests looking in `hub.log`.

Windows has no self-check every 2 minutes like Linux does. To check the bridge manually:
`py -3 C:\walkie-hub\healthcheck.py --config C:\walkie-hub\hub.json`.

Management (PowerShell as administrator):

```powershell
Stop-ScheduledTask  -TaskName WalkieHub        # stop
Start-ScheduledTask -TaskName WalkieHub        # start (after editing hub.json: Stop first)
Get-ScheduledTask   -TaskName WalkieHub | Get-ScheduledTaskInfo
Get-Content C:\walkie-hub\hub.log -Tail 20 -Wait   # live log
```

Status page on the same computer: `http://localhost:47080/?t=TOKEN`. From other devices on the
network, use the computer's address.

To keep the bridge always available, turn off sleep on the computer: "Settings → System → Power".

To remove the bridge (the firewall rule names are in Russian because that's what the installer
creates):

```powershell
Unregister-ScheduledTask -TaskName WalkieHub -Confirm:$false
Remove-NetFirewallRule -DisplayName "Мост раций UDP 47000", "Мост раций TCP 47080"
```

### Running manually (macOS, Linux, Windows)

To try the bridge without installing it, run it in a terminal window. The log appears right on the
screen; stop it with Ctrl+C:

```bash
cd hub
cp hub.example.json hub.json     # and enter the key
python3 walkie_hub.py --config hub.json -v     # -v — verbose log
```

On Windows, type `py -3` instead of `python3`, and `copy` instead of `cp`.

On macOS, the first time you run it the system may ask whether to allow Python to accept incoming
connections: allow it.

---

## 6. Connecting radios to the bridge

Each radio needs two values:

- **bridge address** — an IP or a name: `203.0.113.10` or `radio.example.com`. You can omit the port
  if it's the standard one (47000). If it's non-standard, write `radio.example.com:47100`. For
  option B leave the field empty;
- **network key** — the same one as in `hub.json`.

### Via the radio's page (from a phone)

1. Open the radio settings page. A radio with no network key opens the `RADIO-XXXX` access point by
   itself when switched on, even if its Wi-Fi is already set up. Connect to it with your phone, and
   the page opens by itself. If the radio is already on your Wi-Fi network, the page is at
   `http://radio-xxxx.local` (`xxxx` is the same 4 characters as in the access point name, only in
   lower case). You can also open the access point manually: hold the PTT (push-to-talk) button
   and switch the radio on. More in [Flashing and setup](SETUP.md#2-first-time-setup).
2. In the «Настройки» (Settings) section, fill in the **«Адрес моста»** (Bridge address) and
   **«Ключ сети»** (Network key) fields and press **«Сохранить»** (Save). You don't need to restart
   the radio: it immediately starts looking for the new bridge.
3. If the key is shorter than 12 letters and digits, the radio replies «Сохранено, но ключ не принят:
   нужно не меньше 12 букв и цифр» ("Saved, but the key was not accepted: at least 12 letters and
   digits are required").

The key is not shown on the page. Next to the field it only says «задан» (set) or «не задан» (not
set). Leave the field empty if you don't need to change the key.

### Over a USB cable (macOS / Linux)

```bash
python3 tools/provision.py --name Warehouse --server radio.example.com --key XXXX-XXXX-XXXX-XXXX
python3 tools/provision.py --show          # check what was written
python3 tools/provision.py --server auto   # go back to searching for a bridge on the local network (option B)
```

On macOS the script finds the board's port by itself; if several boards are connected, specify
`--port /dev/cu.usbmodem…`. On Linux always specify the port: `--port /dev/ttyACM0` (or
`/dev/ttyUSB0`). The script doesn't work on Windows. Connect to the board with any serial monitor at
115200 baud (for example, the Serial Monitor in the Arduino IDE with the line ending set to "New
Line") and type the commands (the full list is in [Flashing and setup](SETUP.md#5-usb-commands)):

```
server radio.example.com
key XXXX-XXXX-XXXX-XXXX
show
```

### How to tell the radio is connected

- The radio plays its "connected" sound, and the ring briefly flashes **green** every 3 seconds (on
  USB power, instead of flashing, the ring glows dim green steadily).
- On the bridge status page, the radio appears in the «Рации на этом мосту» (Radios on this bridge)
  table as «в сети» (online). Next to it you can see its name, battery, Wi-Fi strength, latency to the
  bridge and firmware version.

What the ring means when there's no connection:

| Ring | What's happening |
|---|---|
| two orange LEDs blinking | Wi-Fi is up, no bridge: wrong address, UDP port closed, bridge not running |
| red and purple alternating | key not set or doesn't match the bridge's key |
| amber flash instead of green | connected to the bridge, but one of the bridges in `peers` is unreachable |
| a running blue LED | the radio is searching for Wi-Fi |

### Your bridge address built into the firmware

If you have many radios, you can put the address into your own firmware build, in
`firmware/walkie/config.h`:

```c
#define DEFAULT_SERVER "radio.example.com"
```

Freshly flashed radios will know the bridge straight away; you'll only need to enter the key. An
address saved in the radio's memory takes priority over this value. The key is never built into the
firmware: it is stored only in the radio's memory.

---

## 7. Multiple bridges (the peers field)

Bridges linked through `peers` exchange service packets every 2 seconds. A bridge forwards speech
from its own radios to all linked bridges, and speech from a linked bridge only to its own radios.

Rules:

- **all bridges use the same network key**, but **different names (`name`)**;
- in `peers` you write the address of the other bridge: an IP or a name, with the port after a colon
  if it isn't 47000. The bridge re-resolves names to IP addresses every 5 minutes;
- **a link from one side is enough.** If bridge A knows bridge B's address but B doesn't know about
  A, B will still accept A, since they share the key. A then shows up at B as an unknown bridge and is
  forgotten after a minute of silence. So a bridge behind a router (at home, in the office) can be
  linked to a bridge on a VPS without opening any ports on the router: put the VPS address into the
  home bridge's `peers`, and the VPS bridge needs nothing;
- **a bridge doesn't relay other bridges' speech any further.** With three or more bridges, each one
  must be linked to every other. For example, two bridges behind routers that are linked only to the
  VPS won't hear each other: they also need a direct link between themselves (a VPN or port
  forwarding);
- if the button is pressed at the same moment in two locations, the same radio gets the channel on
  all bridges (the one with the lower number). The other hears the busy tone;
- while at least one bridge from the list is unreachable, the radios show an amber flash instead of a
  green one, and on the status page that bridge is marked «нет связи» (no connection).

Example: a Windows PC with a bridge at home and another in the office, radios with an empty bridge
address, the PCs linked through Tailscale. Tailscale is a VPN with a free plan for personal use: it
gives every computer a permanent address in your private network. The other computer's address is
shown in the Tailscale app.

`hub.json` at home:

```json
{
  "name": "Home",
  "key": "XXXX-XXXX-XXXX-XXXX",
  "peers": ["203.0.113.22"],
  "status_token": "TOKEN"
}
```

`hub.json` in the office:

```json
{
  "name": "Office",
  "key": "XXXX-XXXX-XXXX-XXXX",
  "peers": ["203.0.113.21"],
  "status_token": "TOKEN"
}
```

Here `203.0.113.21` (home) and `203.0.113.22` (office) are example Tailscale addresses of the PCs.
One side would be enough, but both sides is more reliable. The remaining fields can be left out: the
defaults from the table in [section 4.4](#44-fill-in-hubjson) are used.
If the VPN routes traffic through a relay server in another country, latency goes up and speech will
arrive with a delay.

Important for options B and C:

- a radio looks for a bridge only on **its own** subnet and only on port 47000. The computer with the
  bridge must be connected to the same router. Guest networks with "client isolation" often block
  this search;
- keep **one** bridge per network: a radio connects to whichever answers first.

---

## 8. Status page

Address: `http://ADDRESS:47080/?t=TOKEN`, for example `http://radio.example.com:47080/?t=TOKEN`.
The page refreshes itself every 5 seconds. It shows:

- the bridge name, its uptime and which firmware it has available for distribution;
- the channel: «эфир свободен» ("channel is free") or «сейчас говорит …» ("now talking: …"), with
  where and for how many seconds;
- **radios on this bridge**: name, number, address, «в сети» (online) / «говорит» (talking) / «нет
  связи» (no connection), battery (or «от сети» (on external power) when powered from USB), Wi-Fi
  strength in dBm, latency to the bridge, firmware version, «звук выключен» (sound off);
- **other bridges** (if any): connected or not, latency, which radios are on them;
- **log**: the last 60 events. For example: «в сети: Warehouse (…)» ("online: Warehouse (…)"),
  «эфир: говорит Office» ("channel: Office is talking"), «🔋 Warehouse: аккумулятор 12% — пора на
  зарядку» ("🔋 Warehouse: battery 12% — time to charge", at 15 % and below), «⚠ Warehouse: в
  передаче одна тишина — проверьте микрофон» ("⚠ Warehouse: only silence in the transmission — check
  the microphone"), «⚠ пакет раций с неверной подписью от … — не тот ключ сети?» ("⚠ radio packet
  with an invalid signature from … — wrong network key?").

The same data in machine-readable form, for example for your own monitoring:
`http://ADDRESS:47080/status.json?t=TOKEN`.

A radio is considered gone if no packets have arrived from it for 7 seconds. The radio itself sends a
hello every 2 seconds and decides the bridge is gone if it gets no reply for 6.5 seconds.

---

## 9. Over-the-air firmware updates

Radios that already work with the bridge update themselves: no need to open them up or plug in a
cable. The very first firmware on a new radio is flashed over USB (see
[Flashing and setup](SETUP.md#1-flashing)).

### How it works

- At startup, and then every 10 seconds, the bridge looks into the `firmware_dir` folder. It should
  contain `walkie.bin` (the firmware itself) and `walkie.json` with the version number:
  `{"version": 10}`.
- In every reply to a radio, the bridge reports the version number, the file size and its SHA-256
  checksum. This is the file's "fingerprint": if even one byte changes, the fingerprint is different.
- A radio downloads the update only if all of these conditions are met:
  - the version number on the bridge is **higher** than its own (`FW_VERSION` in
    `firmware/walkie/config.h`);
  - it hasn't already installed this same build;
  - for **20 seconds** nobody has pressed its button and nobody has been talking on the channel.
- The radio downloads `http://<bridge IP>:47080/fw/<first 16 characters of SHA-256>.bin`, checks the
  size and the fingerprint, writes the firmware and restarts. While downloading, the ring shows a
  growing blue bar. The bridge log gets the entry «рация … скачивает прошивку 10» ("radio … is
  downloading firmware 10").
- If anything doesn't match, the radio stays on the old firmware and tries again in an hour. You don't
  have to wait the hour: switch the radio off and on.
- **You can't roll back to an older version over the air**: the radio won't install a number lower
  than or equal to its own. To bring back old code, build it with a higher number.

### Step by step

1. Increase the number in `firmware/walkie/config.h`, for example `#define FW_VERSION 10`.
2. Build the firmware (requires `arduino-cli`):
   ```bash
   tools/build_firmware.sh
   ```
   `firmware/dist/` will then contain `walkie.bin` and `walkie.json` for the bridge, plus
   `walkie-full-v10.bin` for the first flashing over USB. **The bridge needs `walkie.bin`
   specifically**; the full `walkie-full-…` image won't install over the air.
3. Copy the files to the bridge **in this order: first `walkie.json`, then `walkie.bin` under a
   temporary name, and finally rename it**:
   ```bash
   ssh ubuntu@203.0.113.10 'mkdir -p ~/walkie-hub/firmware'
   scp firmware/dist/walkie.json ubuntu@203.0.113.10:~/walkie-hub/firmware/walkie.json
   scp firmware/dist/walkie.bin  ubuntu@203.0.113.10:~/walkie-hub/firmware/walkie.bin.new
   ssh ubuntu@203.0.113.10 'mv ~/walkie-hub/firmware/walkie.bin.new ~/walkie-hub/firmware/walkie.bin'
   ```
   On a Windows bridge, the same in PowerShell:
   ```powershell
   New-Item -ItemType Directory -Force C:\walkie-hub\firmware | Out-Null
   Copy-Item firmware\dist\walkie.json C:\walkie-hub\firmware\walkie.json
   Copy-Item firmware\dist\walkie.bin  C:\walkie-hub\firmware\walkie.bin.new
   Move-Item -Force C:\walkie-hub\firmware\walkie.bin.new C:\walkie-hub\firmware\walkie.bin
   ```
4. Within 10 seconds the bridge log shows «прошивка для раций: версия 10, … КБ» ("firmware for
   radios: version 10, … KB"), and the status page shows «прошивка для раций: версия 10» ("firmware
   for radios: version 10"). Each radio starts updating as soon as there have been 20 seconds with no
   button presses and no talking on the channel. After the restart, the new number appears in the
   «Прошивка» (Firmware) column.

**Why the order matters.** The bridge re-reads both parts only when the `walkie.bin` file changes.
If you put the new `walkie.bin` in place before `walkie.json`, the bridge may manage to read the new
file with the old version number, and the radios won't update. If that happens, restart the bridge.
The temporary name is there so the bridge doesn't read a half-copied file: renaming is instant.
Before every download, the bridge checks the file against the announced fingerprint. If the file was
replaced after the bridge read it, the radio gets an error and tries again in an hour (or right after
being switched off and on), and the bridge re-reads the file.

If linked bridges have radios of their own, put the update into the folder of **every** bridge: a
radio downloads firmware only from its own bridge.

The ready-made firmware from this repository (`firmware/dist/walkie.bin` + `walkie.json`) can also be
distributed this way: radios with the same or a higher number will ignore it.

---

## 10. Testing without radios

### Software radio `sim_radio.py`

Pretends to be a radio: it connects to the bridge from a computer, transmits and listens to the
channel. It needs nothing but Python and runs from any computer:

```bash
cd hub
python3 sim_radio.py --hub radio.example.com --key XXXX-XXXX-XXXX-XXXX status
```

The reply looks like this (the numbers are just an example):

```
мост «Cloud» ответил за 31 мс: раций в сети 3, мостов 0/0, прошивка для раций v10
```

(That is: "bridge 'Cloud' replied in 31 ms: radios online 3, bridges 0/0, firmware for radios v10".)

| Command | What it does |
|---|---|
| `status` | connect and show the bridge's reply: latency, how many radios are online, how many of the listed bridges are connected, the firmware version available for distribution |
| `tone --seconds 3 [--hz 800]` | "press the button" and transmit an 800 Hz tone for 3 seconds: all radios will hear it |
| `say file.wav` | transmit a recording: WAV 16 kHz, mono, 16-bit (`ffmpeg -i in.mp3 -ar 16000 -ac 1 out.wav`) |
| `listen --seconds 60 --out efir.wav` | listen to the channel for 60 seconds, record everything to WAV and show packet loss and latency jitter for each transmission |
| `echo --minutes 30 [--save folder]` | "parrot": say something into a radio and release the button, and what you said comes back on the channel. This tests the microphone, the speaker and the whole path through the bridge. With `--save`, every transmission is saved to WAV |

Common options: `--hub address[:port]`, `--key`, `--name` (the name on the bridge page, default
`Компьютер` ("Computer")), `--id` (number in hexadecimal). If you run two software radios at the
same time, for example `listen` in one window and `tone` in another, give them different numbers:
`--id A1` and `--id A2`. Otherwise the bridge will take them for one radio.

The software radio shows up on the status page like a normal radio. 7 seconds after it exits it is
marked «нет связи» (no connection), but the row stays in the table until the bridge restarts (just
like with real radios).

What the errors mean:

- «мост … не ответил за 5 с (адрес, порт UDP, брандмауэр, ключ?)» ("bridge … did not answer within
  5 s (address, UDP port, firewall, key?)") — packets aren't getting through. Check the address, the
  service on the server, and the UDP 47000 rule at the provider and in the firewall;
- «⚠ мост ответил: подпись не сошлась — не тот ключ сети» ("⚠ bridge replied: signature mismatch —
  wrong network key") — the bridge is reachable but the key is different. Right after that the
  program also prints «не ответил за 5 с» ("did not answer within 5 s"): the cause is the same, look
  for it in the key.

### Self-check `healthcheck.py`

Sends the bridge a service packet and waits up to 3 seconds for a reply. Prints «мост отвечает»
("bridge is responding", exit code 0) or «мост НЕ отвечает» ("bridge is NOT responding", exit
code 1). It doesn't appear in the radio list. It takes the key and the port from `hub.json`:

```bash
python3 hub/healthcheck.py --config hub/hub.json                        # bridge on this computer
python3 hub/healthcheck.py --config hub/hub.json --host 203.0.113.10    # remote bridge
```

---

## 11. Security

**What is protected.**

- Every packet is signed with the network key (HMAC-SHA256). The bridge and the radios drop any
  packet without a valid signature. Without the key, a stranger's radio or a scanner from the
  internet can't get onto the channel.
- Speech is encrypted (AES-128) with a separate key derived from the network key. The bridge doesn't
  decrypt speech. Someone who intercepts the packets on the way can't hear it without the key.

**What is not protected.**

- **Whoever knows the key is in the network**: they can connect their own radio, talk and hear
  everything. The key is stored unencrypted in the `hub.json` of every bridge and in the memory of
  every radio. If you lose a radio or the key gets into the wrong hands, change the key.
- Radio names, battery level, firmware version and service packets are signed but **not
  encrypted**.
- The status page uses plain HTTP without encryption, and the token is sent in the address as plain
  text. This protects against casual visitors, not against someone intercepting your traffic. Don't
  reuse a password from anything else as the token.
- The radio settings page has no password: anyone on the same Wi-Fi network can open it, change the
  settings and upload different firmware to the radio. It does not reveal the network key, though.
- The bridge serves the firmware file for radios (`/fw/…` on port 47080) without a token. Don't put
  anything secret into your firmware build. The network key never ends up in the firmware.

**Rules.**

- Don't publish `hub.json`, a link with your token, or screenshots showing the key. The files
  `hub/hub.json`, `hub/hub.log*` and `hub/firmware/` are already listed in `.gitignore`, so git won't
  push them to GitHub.
- Set `status_token`: without it, anyone who knows the address sees the radio names and their IP
  addresses.
- Log in to the server with an SSH key and keep the system updated (`sudo apt update && sudo apt
  upgrade`).
- **Changing the key:** generate a new one, put it into the `hub.json` of every bridge and restart
  them. Then enter the new key into every radio: through the page or with `provision.py --key`. Until
  the key is updated, the radio shows red and purple, and the bridge log shows «пакет раций с неверной
  подписью» ("radio packet with an invalid signature"). A settings reset with the volume knob button
  (hold for 10 seconds) does not erase the key, the name or the bridge address. Only a full reset with
  the `factory` USB command erases them.

---

## 12. If the server address changes

A radio knows the bridge by its address. If the server's IP has changed and the radios still have the
old IP:

- the radios lose the bridge: two orange LEDs, you can't talk;
- **there's no way to tell them the new address through the bridge**: both updates and the connection
  itself go through it. You'll have to enter the new address into every radio by hand (the radio's
  page or `provision.py --server`).

How to avoid this:

1. **Pin the address** at the provider: a "static" or "reserved" IP. Do this before you hand out the
   radios. Sometimes there's a small extra charge for it.
2. **Even more reliable — a domain name.** Create an A record at your domain registrar (for example,
   `radio.example.com` → `203.0.113.10`) and enter the name into the radios, not the digits. The radio
   looks up the IP for the name again when the settings are saved, every 15 seconds while there's no
   bridge, and every 10 minutes while connected. If the address changes, you only need to update the
   record at the registrar: the radios will find the bridge on their own as soon as DNS updates.
   Bridges that have names in `peers` refresh the addresses the same way, every 5 minutes. If you're
   planning a move, lower the record's time to live (TTL) to 5 minutes in advance.

**Moving to another server.** Move `hub.json` unchanged (same key and same name) along with the
`firmware` folder. Install the bridge on the new server and change the address in the domain's A
record. You won't have to set up the radios again.

---

## 13. Troubleshooting

Bridge startup errors are visible in `journalctl -u walkie-hub`. On Windows the bridge runs without a
window, so to find the error, stop the task (`Stop-ScheduledTask -TaskName WalkieHub`) and run the
bridge manually: `py -3 C:\walkie-hub\walkie_hub.py --config C:\walkie-hub\hub.json`.

| Symptom | What to check |
|---|---|
| `sim_radio.py … status`: «не ответил за 5 с» ("did not answer within 5 s") | Is the service running (`systemctl status walkie-hub`); is UDP 47000 open at the provider and in `ufw` (Windows: firewall rules); is the address right; does the server have IPv4 |
| «подпись не сошлась — не тот ключ сети» ("signature mismatch — wrong network key") | The key in the radio or in `--key` doesn't match `hub.json`. Check for extra characters and Cyrillic letters, and that it's no longer than 39 characters |
| Bridge won't start: `ключ сети слишком короткий` ("network key too short") | `key` has fewer than 12 letters and digits |
| Bridge won't start: `JSONDecodeError` | Error in `hub.json`: an extra or missing comma, quotes |
| Bridge won't start: `Address already in use` | The port is taken: the bridge is already running (the service and a manual run at the same time) or another program is using the port |
| The page won't open | Is TCP 47080 open at the provider and in the firewall; did you forget `?t=TOKEN` (without it you get «нужен ?t=<токен>», "?t=<token> required") |
| Radio: two orange LEDs | Bridge address in the radio, port, firewall. For option B — the bridge computer on the same subnet, `port` 47000, one network without client isolation |
| Radio: red and purple | Key not set or doesn't match |
| Radio: amber flash | One of the bridges in `peers` is unreachable. Look at the «Другие мосты» (Other bridges) section on the status page |
| Bridges can't see each other | Same `name` on two bridges; different keys; the address in `peers`; UDP 47000 between them |
| Radios don't update | The number in `walkie.json` must be higher than the radios'; is TCP 47080 open (the radio downloads over it); is it `walkie.bin` (not `walkie-full-…`); were the files copied in the right order (otherwise restart the bridge); the radio was left untouched for 20 seconds; after a failure the radio waits an hour (or switch it off and on) |
| Log says «в передаче одна тишина» ("only silence in the transmission") | The radio's microphone has most likely come loose or is wired incorrectly |

How packets, signatures and encryption work is covered in the [protocol description](protocol.md).

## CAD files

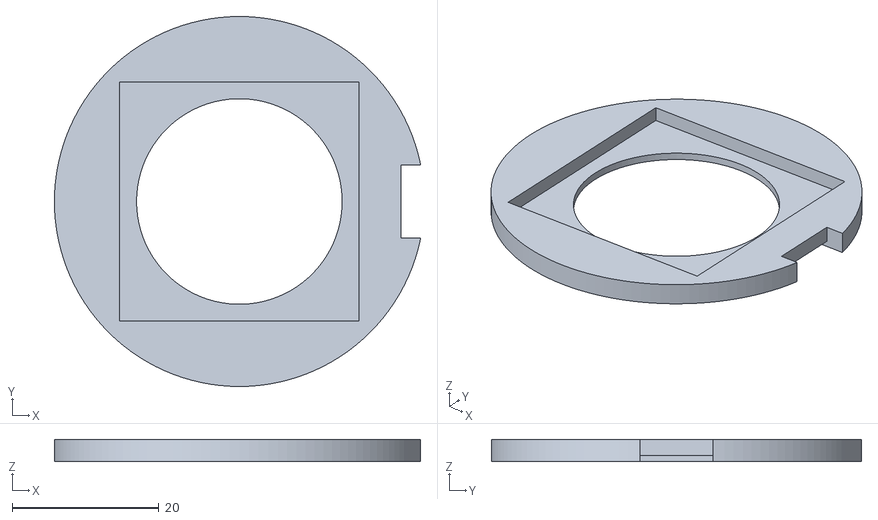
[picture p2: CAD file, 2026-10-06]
stl/spacer.stl
49.9 x 50.4 x 3.00

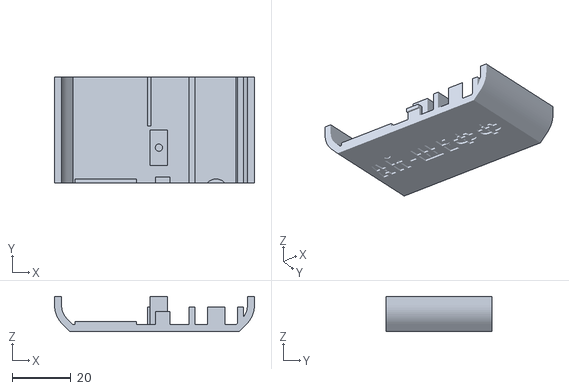
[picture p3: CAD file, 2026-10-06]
stl/edge_test.stl
68.0 x 36.0 x 12.0

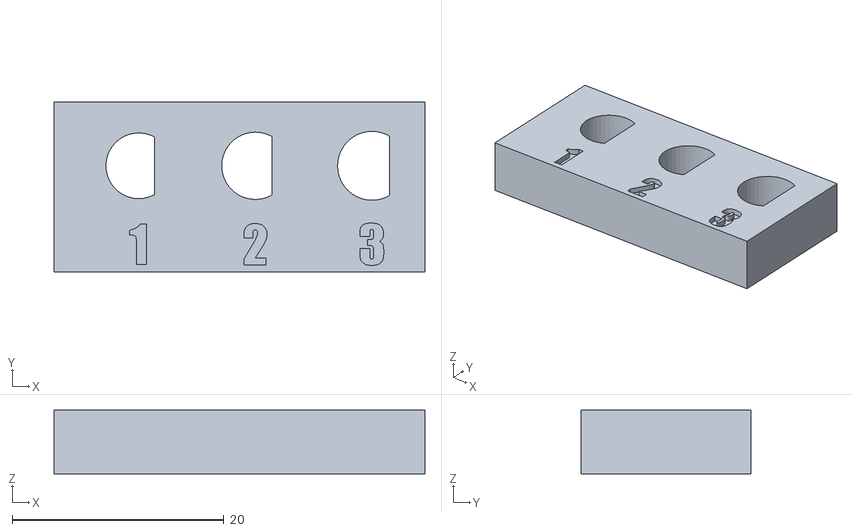
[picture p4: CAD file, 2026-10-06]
stl/shaft_gauge.stl
35.0 x 16.0 x 6.00

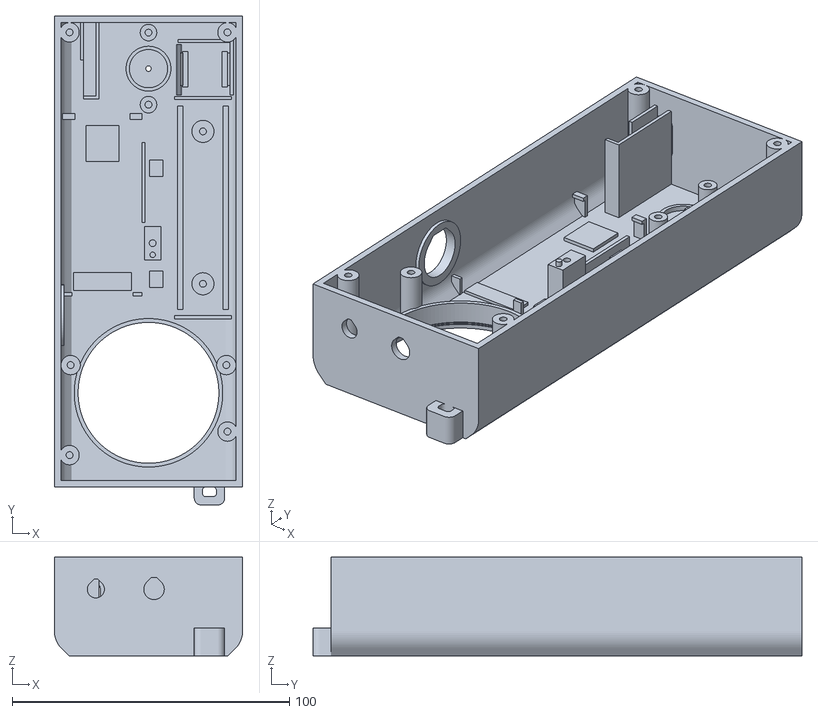
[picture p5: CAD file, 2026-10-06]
stl/front.stl
68.0 x 176.5 x 35.6

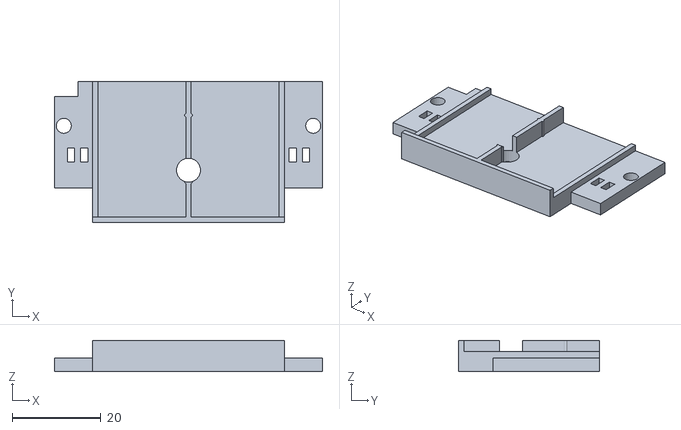
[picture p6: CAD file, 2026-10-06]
stl/shelf.stl
60.4 x 31.8 x 7.00

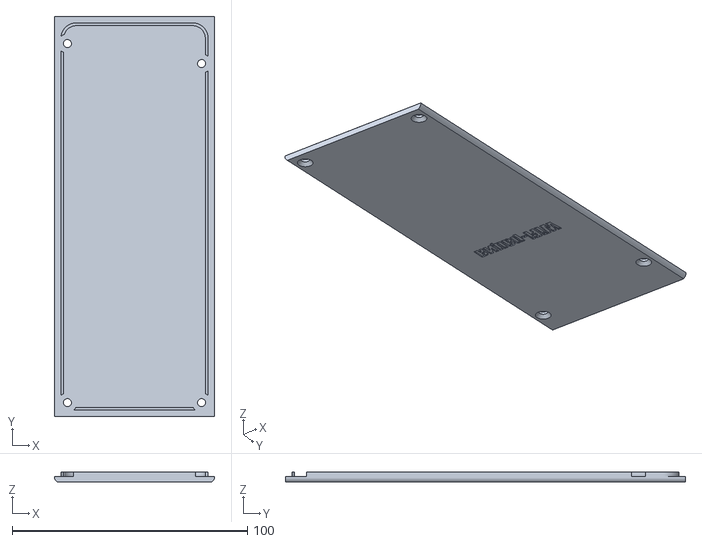
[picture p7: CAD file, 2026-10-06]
stl/back.stl
68.0 x 170.0 x 4.39

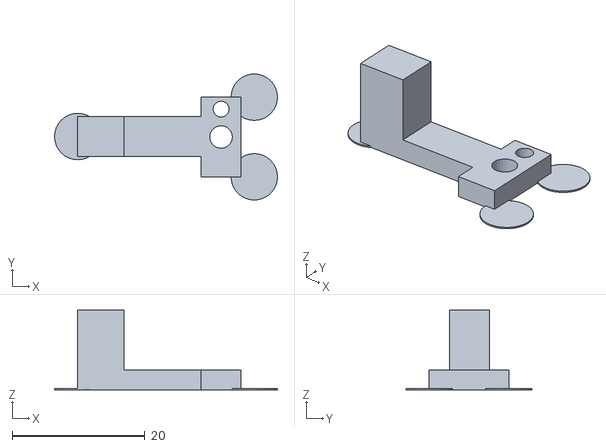
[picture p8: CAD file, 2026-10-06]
stl/dk_arm.stl
33.6 x 19.0 x 12.1

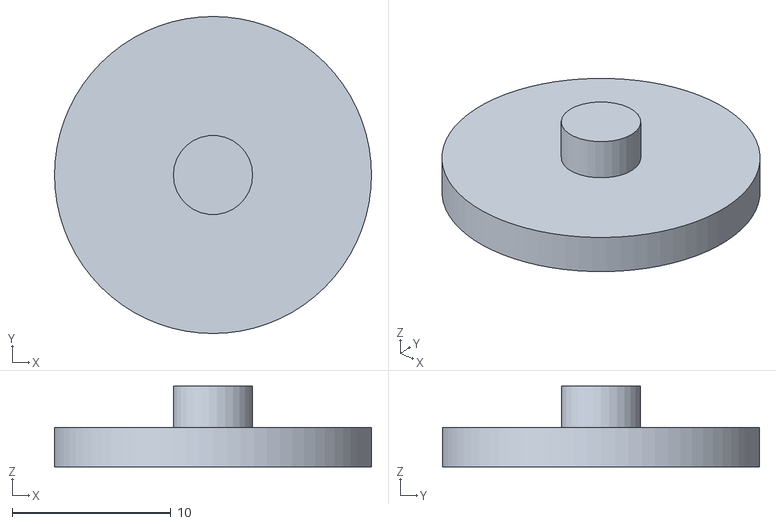
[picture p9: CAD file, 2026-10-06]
stl/spk_puck.stl
20.0 x 20.0 x 5.10

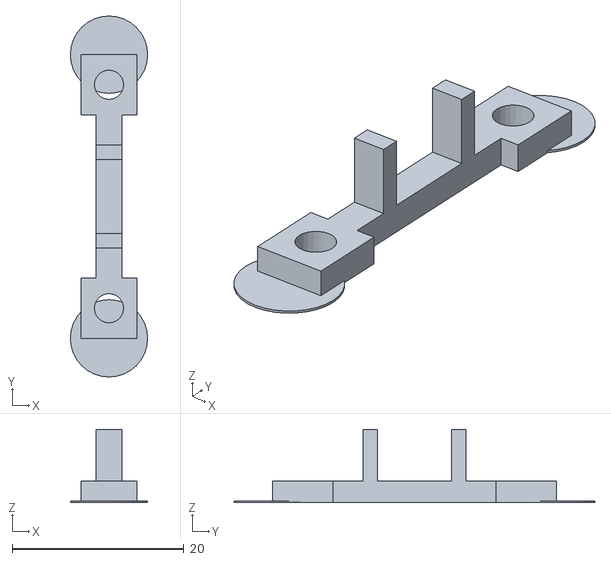
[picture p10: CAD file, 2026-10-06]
stl/mic_cap.stl
9.00 x 42.0 x 8.50

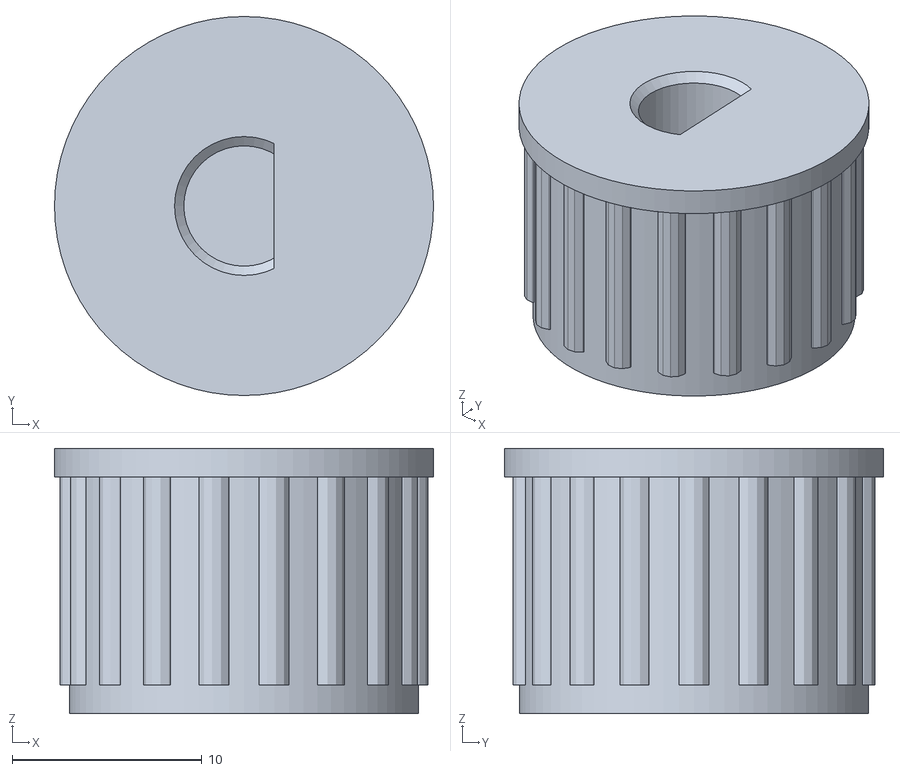
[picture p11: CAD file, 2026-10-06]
stl/knob.stl
20.0 x 20.0 x 14.0

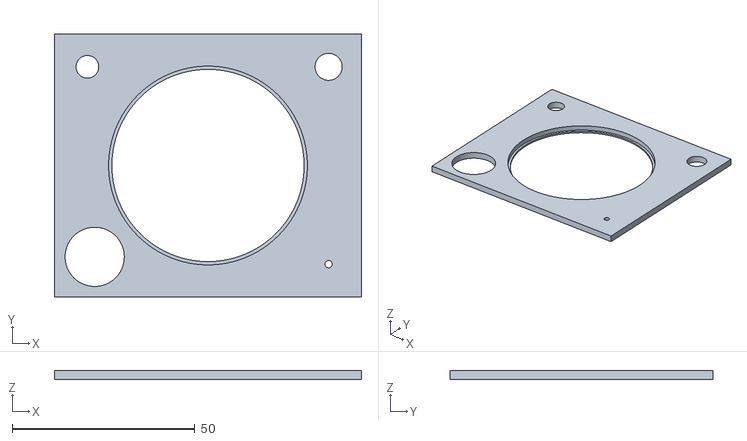
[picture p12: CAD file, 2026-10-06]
stl/coupon.stl
84.0 x 72.0 x 2.40

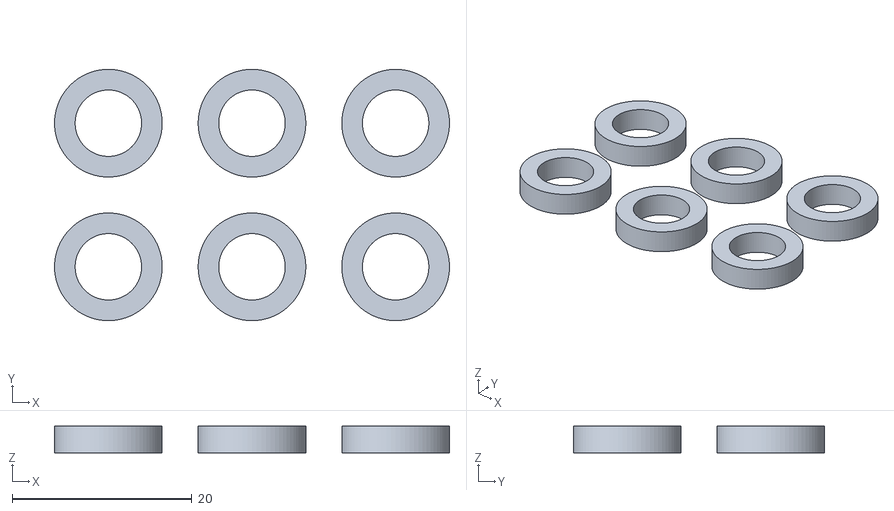
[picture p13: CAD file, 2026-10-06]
stl/enc_spacer.stl
44.0 x 28.0 x 3.00

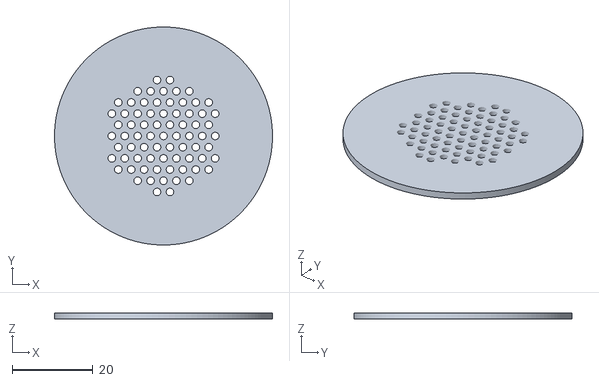
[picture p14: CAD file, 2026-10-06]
stl/lens.stl
54.0 x 54.0 x 1.60

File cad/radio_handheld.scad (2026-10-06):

// ============================================================
//  WiFi-рация Ай-Шефф — переносной корпус (аккумулятор 18650)       v3 (28.09.2026)
//  Параметрическая модель OpenSCAD (snapshot 2026, backend Manifold). Числа — в шапке.
//
//  Брусок 68 × 38 × 170 мм (Ш × Т × В):
//    спереди — динамик за белым диском, вокруг решётки светится кольцо WS2812;
//              внизу — отверстие микрофона, посередине — надпись «АЙ-ШЕФФ»;
//    левый бок — кнопка «говорить» (антивандальная 16 мм);
//    верх — регулятор громкости (KY-040) и выключатель (тумблер M6, стоит поперёк: рычажок ходит к лицу и к спине);
//    низ — гнездо зарядки USB-C модуля заряда.
//
//  v3 (по сборке прототипа 28.09): ВСЁ железо крепится к лицевой части, задняя крышка — просто крышка,
//  к ней не идёт ни одного провода (в v2 через стык шло ~20). Сняли крышку — всё на виду:
//    внизу:     микрофон под планкой (2 самореза), модуль заряда стоит на ребре в пазу, усилитель в гнезде на защёлках;
//    середина:  плата ESP32-S3 (модулем к лицу, штырьками к вам) — лежит на площадках, углы у антенны под
//               козырьками, посередине прижата лапкой (1 саморез); держатель 18650 на 2 саморезах через свои
//               отверстия в дне (изнутри); между платой и аккумулятором — канал для проводов с 2 мостиками под стяжки;
//    верх:      полка за динамиком (2 самореза) прижимает динамик вместе с кольцом и белым диском
//               и держит обе клеммы; регулятор штырьками ВПРАВО — от тумблера (в v2 они упирались в тумблер).
//  Корпус: ребро у лица скосом 45° (в v2 висело в воздухе — полосы и жгут на боку), надпись трафаретом.
//
//  Размеры — замеры автора 27 и 28.09 (все числа: cad/measurements.md). Гнёзда клемм, держателя и
//  динамика в v2 были по размеру. Не мерили: толщину платы усилителя (взята 1,6).
//
//  Детали (саморезы по пластику: 5 шт. 3×10 внутри + 2 шт. 3×12 на держатель 18650 + 4 шт. 3×12 потай на крышку):
//           front      — лицевая часть со стенками: печать ЛИЦОМ НА СТОЛ, без поддержек
//           back       — задняя крышка: 4 самореза 3×12 (потай)
//           shelf      — полка за динамиком: прижимает динамик, держит 2 клеммы (2 самореза)
//           dk_arm     — лапка платы ESP (1 саморез + штырёк-фиксатор)
//           mic_cap    — планка микрофона: прижимает плату между столбиками штырьков (2 самореза)
//           shaft_gauge — пробник вала регулятора: 3 отверстия, какое сядет лучше (≈5 минут)
//           lens       — диск динамика со светящимся кольцом: печатать БЕЛЫМ PLA/PETG
//           spacer     — прокладка между кольцом светодиодов и динамиком
//           knob       — ручка регулятора
//           enc_spacer — кольцо-проставка регулятора: запасная, нужна только при длинной резьбе втулки
//           coupon, edge_test — пробники
//
//  Отверстия в стенках (кнопка, регулятор, тумблер) — «капелькой» остриём к спине: при печати лицом
//  на стол их верх не провисает.
//
//  Экспорт (из папки проекта):
//    openscad --backend manifold --export-format binstl -D 'part="front_print"' -o stl/front.stl cad/radio_handheld.scad
//  Проверки (экспорт должен быть ПУСТЫМ): check_inside, check_walls, check_lid, check_parts
// ============================================================

part = "assembly";

$fn = 72;
eps = 0.01;

// ---------- Корпус ----------
W = 68;            // ширина
T = 38;            // толщина (от лица до спины)
H = 170;           // высота
wall = 2.4;        // стенки и лицо (≈ 5–6 линий сопла 0,4)
back_t = 2.4;      // задняя крышка
r_v = 9;           // скругление длинных рёбер у лица; от лица оно начинается скосом 45° (см. plan0)
r_b = 2;           // и у спины: маленькое, чтобы стык с крышкой и головки саморезов легли на плоскость

// ---------- Покупные детали ----------
spk_sq = 32;       // динамик Chip-Dip FBS3232 (8 Ом 3 Вт): квадратный фланец 32×32×2,2
spk_flange = 2.2;
spk_body_d = 28.7; // магнит Ø27,3, с лепестками выводов по кругу Ø28,7 (замер 28.09)
spk_depth = 14.7;  // полная глубина (замер 27.09: 32×32×14,7)
ring_od = 50;      // кольцо WS2812B 12 шт.: 50/36 мм (замер 27.09 — Ø50)
ring_id = 36;
ring_h = 2.5;      // плата + светодиод (замер 28.09; было 3,4 — динамик в v1 болтался на 0,9)
ptt_hole = 16.2;   // антивандальная кнопка PBS-28B-2 D-16 (Chip-Dip): резьба M16
ptt_body = 20.3;   // в корпусе: глубина 20,3 и Ø14,6 (замер 28.09)
ptt_d = 14.6;
sw_hole = 6.2;     // микротумблер MTS-101 (Chip-Dip): отверстие Ø6
sw_depth = 15;     // корпус под панелью 14 × 12,7 × 7,8 (замер 28.09) + 1 на пайку
sw_body = [7.8, 12.7];
enc_bush_d = 7.0;  // энкодер KY-040: втулка M7, резьба 12 мм (замер 27.09)
enc_pcb = [26, 19.0];        // плата без штырьков; вдоль x: 32 мм вместе со штырьками (замер)
enc_pin_side = 14;           // от оси до края платы со штырьками (замер: до концов штырьков 20, штырьки ≈6)
enc_pins = 6;                // штырьки целиком: укорачивать больше не нужно — смотрят от тумблера в свободный угол
enc_plug = 14;               // колодка Dupont мама на штырьках: от края платы 14 мм, дальше провод загибается вниз
enc_pocket = 1.2;            // карман в правой стенке у колодок: стенка там 1,2 вместо 2,4
enc_spacer_t = 3;            // кольцо-проставка (запасная деталь): только если резьба втулки длиннее обычной
enc_drop = 0;
knob_d = 20;
knob_h = 14;
shaft_d = 6.35;    // вал Ø5,8 с лыской 4,2 (замер 28.09); ручка v1 (6,1/4,6) шла очень туго: печать сужает отверстие ≈0,3
shaft_flat = 4.75; // от лыски до противоположного края отверстия; вход — с фаской 0,5. Проверка — пробник shaft_gauge
shaft_chamfer = 0.5;
shaft_depth = 10;
mic_pcb_d = 13.4;  // INMP441 (замер 28.09): плата Ø13,4 толщиной 0,7, с деталями 1,7; выемки по бокам — между ними 11,9
mic_smd = 1.7;     // плата + детали: деталями (и капсюлем) к лицу, штырьки к спине
mic_cols = 3.81;   // 2 столбика по 3 штырька: SD·VDD·GND и SCK·WS·L/R — на ±3,81 от центра: 29.09 планка шириной 6
                   // не прошла между колодками (думали ±5,08) — автор подпилил, просит у́же на 3 мм
mic_hole_d = 2.0;
bat_holder = [20.5, 77.5, 21];     // держатель BeilaMoo (замер 28.09): ширина, длина, высота
bat_holes = 55;                    // 2 отверстия Ø3 в дне на 55 мм — саморезы 3×12 изнутри в бобышки
bat_lift = 10;                     // бобышки 10 мм (было 6 под 3×8 — у автора 3×12, 29.09 кончики вылезли на лице):
                                   // саморез 12 − дно держателя ≥1 = до 11 мм в бобышку + лицо, под кончиком ≥1,2 мм лица
bat_screw_in = 11.2;               // глубина отверстия под саморез от верха бобышки
dk = [28, 63];               // плата ESP32-S3 (клон YD, замер 28.09); штырьки 2 × 22 по длинным краям, шаг 2,54
dk_mod = 3.1;                // крышка модуля над платой (плата + крышка = 4,7, замер)
dk_usb = 3.3;                // гнёзда USB-C над платой (каталог)
dk_pin = 8;                  // штырьки от платы (замер): пластик 2,5 + 5,5
dk_ant = 6.3;                // антенна модуля выступает за край платы (по фото, ESP32-S3-WROOM-1: 25,5 − 19,2)
dk_end = (dk[1] - 22 * 2.54) / 2;   // край платы без штырьков (≈3,6 с каждого конца)
chg = [20, 26, 4];           // модуль заряда (замер 27.09): ширина, длина (USB-C на коротком краю), толщина
amp = [17.3, 18.8];          // усилитель MAX98357A (замер 28.09): гребёнка на краю 17,3; штырьки — со стороны деталей
amp_t = 1.6;                 // толщина платы усилителя — не мерили, типовая
clamp = [19.4, 29.8, 9.6];   // клемма СМК 221-415 (замер 27.09): поперёк, вдоль, толщина (гнездо v2 — по размеру)
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

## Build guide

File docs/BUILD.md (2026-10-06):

**Русский** · [English](en/BUILD.md)

# Сборка рации

От покупки деталей до закрытой крышки. Прошивка, Wi-Fi и мост описаны отдельно: [Прошивка и настройка](SETUP.md) и [Свой мост](BRIDGE.md).

Рация в сборе: брусок с белым диском динамика, кнопкой на боку, регулятором и тумблером сверху

Рация — брусок 68 × 38 × 170 мм:

- **спереди** — динамик за белым диском; сквозь диск, вокруг решётки динамика, светится кольцо из 12 светодиодов; внизу — отверстие микрофона;
- **на левом боку** (если смотреть спереди) — кнопка «говорить»;
- **сверху** — регулятор громкости, тумблер «вкл/выкл» и ушко для шнурка;
- **снизу** — гнездо USB-C для зарядки.

Всё железо крепится к лицевой части корпуса, задняя крышка — просто крышка: к ней не идёт ни одного провода. Корпус печатается без поддержек. Клея и скотча внутри нет: всё держится на саморезах, защёлках и в пазах. Клей нужен только для белого диска.

**Порядок работ:** купить детали → напечатать корпус → прошить плату → спаять узлы на столе → собрать в корпусе → проверить → закрыть.

Содержание:

1. [Детали на одну рацию](#1-детали-на-одну-рацию)
2. [Печать корпуса](#2-печать-корпуса)
3. [Схема подключения](#3-схема-подключения)
4. [Сборка корпуса](#4-сборка-корпуса)

---

## 1. Детали на одну рацию

Цены — примерные, на сентябрь 2026 года, без доставки. Магазины даны как пример: подойдут такие же детали откуда угодно, лишь бы совпали размеры (список ниже).

| Деталь | Сколько | ≈ Цена | Где купить (пример) |
|---|---|---|---|
| Плата ESP32-S3-DevKitC-1 N16R8, штырьки уже припаяны | 1 | 816 ₽ | [Ozon](https://www.ozon.ru/product/otladochnaya-plata-esp32-s3-devkitc-1-n16r8-wi-fi-bluetooth-usb-c-dlya-arduino-esp-idf-micropython-5648908176/) |
| Микрофон INMP441 (цифровой, круглая плата) | 1 | 600 ₽ | [Ozon](https://www.ozon.ru/product/modul-vsenapravlennogo-mikrofona-na-inmp441-mems-i2s-4314549062/) |
| Усилитель MAX98357A, 3 Вт | 1 | 180 ₽ | [duino.ru](https://duino.ru/usilitel-moshchnosti-3-vt-s-tsap-dac-i-shinoy-i2s/) |
| Динамик FBS3232, 8 Ом, 3 Вт, 32 × 32 мм | 1 | 470 ₽ | [Chip-Dip](https://www.chipdip.ru/product/fbs3232-8-om-3vt-32-32-14.7mm-bez-markirovki-dinamik-fbele-9001621604), код 9001621604 |
| Кольцо WS2812B на 12 светодиодов, Ø50 мм | 1 | 466 ₽ | [Ozon](https://www.ozon.ru/product/koltso-iz-12-adresnyh-svetodiodov-ws2812b-714069208/) |
| Регулятор KY-040 (поворотный энкодер с кнопкой) | 1 | ≈ 113 ₽ (набор из 3 — 338 ₽) | [Ozon](https://www.ozon.ru/product/modul-povorotnogo-enkodera-hw-040-ky-040-5v-20-shagov-na-oborot-dlya-arduino-3-sht-1509157901/) |
| Кнопка антивандальная PBS-28B-2, 16 мм | 1 | 260 ₽ | [Chip-Dip](https://www.chipdip.ru/product/pbs-28b-2-d-16-mm-steel-knopka-antivandalnaya-9000219084), код 9000219084 |
| Микротумблер MTS-101 | 1 | 55 ₽ | [Chip-Dip](https://www.chipdip.ru/product/mts-101-on-off-mikrotumbler-spst-3a-250v-20-mom-ruichi-9000344178), код 9000344178 |
| Модуль заряда «Power Bank Mini», вход USB-C, выход 5 В 2 А | 1 | 159 ₽ | [Ozon](https://www.ozon.ru/product/modul-power-bank-mini-s-gnezdom-type-c-5v-2a-arduino-561634064/) |
| Аккумулятор 18650, например EVE INR18650-35V, 3500 мА·ч | 1 | 380 ₽ | [Chip-Dip](https://www.chipdip.ru/product/eve-inr18650-35v-akkumulyator-li-ion-18650-3500mah-10a-9001581130), код 9001581130 |
| Держатель 1 × 18650 с проводами | 1 | 79 ₽ | [Chip-Dip](https://www.chipdip.ru/product/kls5-18650-l-fc1-5216-batareynyy-otsek-1x18650-9000296086), код 9000296086 |
| Клемма СМК 221-415 на 5 проводов | 2 | 33 ₽ × 2 | [Chip-Dip](https://www.chipdip.ru/product/smk-221-415-klemma-stroitelno-montazhnaya-5pin-kvt-9001187576), код 9001187576 |
| Провода мама-мама 20 см, набор 40 шт. | 1 набор (уходит ≈ 30) | 211 ₽ (цена при покупке от 3 наборов) | [Chip-Dip](https://www.chipdip.ru/product/soedinitelnye-provoda-mama-mama-40-sht-20-sm-shleyf-iz-9001322249), код 9001322249 |
| Резистор 100 кОм, 0,25 Вт | 2 | 6 ₽ × 2 | [Chip-Dip](https://www.chipdip.ru/product/cf-25-s1-4-0.25vt-100-kom-5-rezistor-uglerodistyy-9549), код 9549 |
| Диод 1N4007 | 1 | 6 ₽ | [Chip-Dip](https://www.chipdip.ru/product/1n4007-diod-vypryamitelnyy-1a-1000v-do-41-do-204ac-diotec-9000461664), код 9000461664 |
| Шуруп потайной 3 × 12: 4 на крышку + 2 на держатель аккумулятора | 6 (пачка 40 шт.) | 45 ₽ за пачку | [Chip-Dip](https://www.chipdip.ru/product/0125030012p300004010-shurup-po-derevu-potay-shlits-steelrex-9000688284), код 9000688284 |
| Саморез 3 × 10 по дереву или пластику: полка, лапка платы, планка микрофона | 5 | — | любой крепёжный магазин |
| Термоусадка, набор трубок разного диаметра | ≈ 10 кусочков по 15 мм | 150 ₽ за набор | [Chip-Dip](https://www.chipdip.ru/product/xbt-universal-nabor-termousadochnoy-trubki-100m-21-sht-xibo-9002098269), код 9002098269 |
| Пластик PLA на корпус + белый PLA или PETG на диск динамика | ≈ 145 г | ≈ 220 ₽ (при 1 500 ₽ за кг) | любой |
| Стяжки 2,5 мм — по желанию, для пучка проводов | 2 | — | любой |

**Итого ≈ 4 200 ₽ на рацию**, если собирать сразу три (наборы и пачки делятся на три). Одна рация отдельно — ≈ 4 500 ₽: регулятор, термоусадка и шурупы продаются наборами. Саморезы 3 × 10 и стяжки в сумму не входят.

### Что важно при покупке

Корпус рассчитан под конкретные размеры. Если ваша деталь другая — сравните с этим списком. Не совпадает: поправьте число в шапке [`cad/radio_handheld.scad`](../cad/radio_handheld.scad) и выгрузите STL заново (см. [раздел 2](#если-нужно-поменять-корпус)).

- **Плата ESP32-S3.** Гнездо — под плату 63 × 28 мм с двумя рядами по 22 штырька (клон YD-ESP32-S3; у него вывод 5V подписан «5Vin»). Прошивке хватает флеш-памяти от 4 МБ, так что подойдёт и N8, и N16R8. Номера выводов у оригинальной DevKitC-1 и у клонов одинаковые.
- **Микрофон INMP441** — круглая плата Ø13,4 мм, два столбика по 3 штырька: SD·VDD·GND и SCK·WS·L/R.
- **Усилитель MAX98357A** — плата 17,3 × 18,8 мм, без винтового клеммника.
- **Динамик** — фланец 32 × 32 мм, глубина 14,7 мм, магнит Ø27,3 мм.
- **Кольцо WS2812B** — Ø50 мм снаружи, Ø36 мм внутри, толщина с ламельками 2,5 мм.
- **Регулятор KY-040** — втулка M7 с резьбой 12 мм, вал Ø5,8 мм с лыской (плоским срезом) 4,2 мм. У вала с мелкой насечкой вместо лыски ручку придётся подгонять.
- **Тумблер MTS-101** — резьба M6, корпус под панелью 14 × 12,7 × 7,8 мм.
- **Кнопка PBS-28B-2** — резьба M16, внутри корпуса занимает Ø14,6 × 20,3 мм, контакты под винт.
- **Модуль заряда** — 20 × 26 × 4 мм, гнездо USB-C на коротком краю. Внутри он устроен как пауэрбанк: если рация берёт совсем мало тока, модуль может решить, что нагрузку отключили, и выключить питание. Поэтому «Экономия аккумулятора» в настройках рации по умолчанию выключена — без нужды её не включайте.
- **Держатель 18650** — 77,5 × 20,5 × 21 мм, в дне два отверстия Ø3 на расстоянии 55 мм.
- **Клеммы СМК 221-415** — 19,4 × 29,8 × 9,6 мм.

### Инструменты

- паяльник 40–60 Вт, припой с флюсом;
- мультиметр;
- бокорезы, канцелярский нож, круглый надфиль — подчистить отверстия после печати;
- крестовая отвёртка Pz1;
- прозрачный клей: «Момент Кристалл» или секундный (не термоклей) — для белого диска;
- фен, а на крайний случай зажигалка — для термоусадки;
- кабель USB-C с передачей данных (не только зарядный) — для прошивки;
- любая зарядка USB-C — заряжать рацию.

---

## 2. Печать корпуса

Все STL лежат в папке [`stl/`](../stl). STL — это файл с 3D-формой детали, его открывает слайсер (программа, которая «нарезает» модель на слои для принтера). Детали уже повёрнуты так, как их надо класть на стол: **не поворачивайте их**. Поддержки не нужны.

### Обязательные детали — на одну рацию

| Файл | Что это | Как лежит на столе | Размер, мм | ≈ г |
|---|---|---|---|---|
| [`front.stl`](../stl/front.stl) | **Лицевая часть**: лицо, бока, верх и низ одной деталью; внутри гнёзда и стойки для всего железа | лицом на стол | 68 × 177 × 36 | 89 |
| [`back.stl`](../stl/back.stl) | **Задняя крышка**, 4 потайных шурупа 3 × 12 | наружной стороной на стол | 68 × 170 × 4 | 32 |
| [`shelf.stl`](../stl/shelf.stl) | **Полка за динамиком**: прижимает динамик вместе с кольцом и диском, держит обе клеммы; 2 самореза 3 × 10 | плитой на стол | 60 × 32 × 7 | 9 за все четыре |
| [`spk_puck.stl`](../stl/spk_puck.stl) | **Шайба динамика**: давит на магнит, штырьком входит в отверстие полки | плашмя | Ø20 × 5 | ↑ |
| [`dk_arm.stl`](../stl/dk_arm.stl) | **Лапка платы ESP**: прижимает плату посередине; 1 саморез 3 × 10 | планкой на стол | 24 × 12 × 12 | ↑ |
| [`mic_cap.stl`](../stl/mic_cap.stl) | **Планка микрофона**: ложится между столбиками его штырьков; 2 самореза 3 × 10 | планкой на стол | 6,5 × 40 × 9 | ↑ |
| [`spacer.stl`](../stl/spacer.stl) | **Прокладка** между кольцом светодиодов и динамиком | плашмя | Ø50 × 3 | 7 за обе |
| [`knob.stl`](../stl/knob.stl) | **Ручка регулятора** | верхом на стол | Ø20 × 14 | ↑ |
| [`lens.stl`](../stl/lens.stl) | **Диск динамика.** Печатайте **белым**: через него светит кольцо | плашмя | Ø54 × 1,6 | 4,5 |

Комплект корпуса без диска — **≈ 140 г пластика и ≈ 5 ч 45 мин** на Bambu Lab P2S (профиль «0.16mm High Quality», время вместе с разогревом и калибровкой стола). На столе 256 × 256 мм весь комплект печатается за один раз; самой длинной детали — лицевой части — нужен стол от 180 мм.

### Пробники — по желанию

Печатать их не обязательно, но они быстро покажут, подходит ли ваш принтер и ваши детали, до того как уйдут 5–6 часов на корпус.

| Файл | Что проверяет |
|---|---|
| [`edge_test.stl`](../stl/edge_test.stl) | Кусок лицевой части 68 × 36 × 12 мм со скруглённым ребром и надписью: как ваш принтер печатает ребро у лица и трафаретные буквы. |
| [`shaft_gauge.stl`](../stl/shaft_gauge.stl) | Пробник вала регулятора: три D-образных отверстия, номера 1, 2, 3 вырезаны сверху. № 1 — Ø6,2 с лыской 4,6; № 2 — Ø6,35 / 4,75; № 3 — Ø6,5 / 4,9. Ручка `knob.stl` сделана под № 2. Если плотно, но без усилия садится другое отверстие — впишите его числа в `shaft_d` и `shaft_flat` в `cad/radio_handheld.scad` и выгрузите ручку заново. |
| [`coupon.stl`](../stl/coupon.stl) | Пластина 84 × 72 × 2,4 мм с отверстиями под диск динамика, кнопку, тумблер, регулятор и микрофон: примерить покупные детали. |
| [`enc_spacer.stl`](../stl/enc_spacer.stl) | 6 колец-проставок толщиной 3 мм (на три рации). Запасные: нужны, только если у вашего регулятора резьба втулки длиннее обычной. Кольцо надевается на втулку изнутри корпуса, между регулятором и стенкой. |

Пробник ребра, пробник вала и ручка вместе — ≈ 16 г и ≈ 47 мин.

### Настройки печати

- пластик — PLA, цвет корпуса любой; диск динамика — **белый** PLA или PETG;
- сопло 0,4 мм, слой **0,16 мм**;
- **3 стенки**, заполнение **15 %**;
- поддержки **выключены**;
- лист — текстурный PEI: его узор ляжет на лицо рации. Подойдёт и гладкий лист.

У лапки платы и планки микрофона снизу есть «ушки» толщиной в один слой: они держат мелкую деталь на столе, после печати их отломите. Если планка микрофона всё равно отрывается от стола, напечатайте её отдельно с каймой (brim) 5 мм.

Отверстия в стенках под кнопку, регулятор и тумблер сделаны «капелькой» с острым концом к спине: при печати лицом вниз их верх не провисает. Если резьбовая втулка входит туго, пройдите отверстие круглым надфилем.

### Нарезка из командной строки (Bambu Studio)

Если у вас macOS, Bambu Studio в папке «Программы» и принтер Bambu Lab P2S, скрипт [`tools/make_print.sh`](../tools/make_print.sh) сам нарежет готовые столы:

```bash
tools/make_print.sh                    # все столы → папка print/
ONLY=1_ tools/make_print.sh            # только столы, в имени которых есть «1_»
PROFILE="0.16mm Standard @BBL P2S" tools/make_print.sh   # другой профиль печати
```

Получатся файлы `print/*.3mf` с оценкой времени и граммов: `0_пробник_кромки_вала`, `1_рация_v3_комплект`, `2_планка_микрофона_x2` (с каймой), `3_белый_диск_x3`, `4_рация_белая_комплект_с_диском`. Откройте нужный файл в Bambu Studio и отправьте на печать. С другим принтером или слайсером просто откройте STL из `stl/` и выставьте настройки из списка выше.

### Если нужно поменять корпус

Корпус — параметрическая модель [OpenSCAD](https://openscad.org) в одном файле: [`cad/radio_handheld.scad`](../cad/radio_handheld.scad). Все размеры покупных деталей и их места — числами в шапке файла. Нужна свежая сборка OpenSCAD (snapshot) с движком Manifold. Надпись на лице набрана шрифтом Impact: если его нет в системе, OpenSCAD подставит другой, и трафаретные перемычки букв могут съехать.

Выгрузить STL заново (из корня проекта):

```bash
for p in front back shelf spk_puck dk_arm mic_cap knob; do
  openscad --backend manifold --export-format binstl -D "part=\"${p}_print\"" -o "stl/$p.stl" cad/radio_handheld.scad
done
for p in lens spacer shaft_gauge coupon edge_test; do
  openscad --backend manifold --export-format binstl -D "part=\"$p\"" -o "stl/$p.stl" cad/radio_handheld.scad
done
openscad --backend manifold --export-format binstl -D 'part="enc_spacer_print"' -o stl/enc_spacer.stl cad/radio_handheld.scad
```

После любой правки прогоните четыре проверки модели: `check_inside` (детали не задевают друг друга), `check_walls` (детали не лезут в стенки), `check_lid` (крышка входит на место), `check_parts` (прижимные детали никуда не врезаются). Каждая должна дать **пустой** результат — OpenSCAD сообщит, что объект пустой:

```bash
for c in check_inside check_walls check_lid check_parts; do
  openscad --backend manifold -D "part=\"$c\"" -o check.stl cad/radio_handheld.scad
done
```

Замеры деталей, по которым построена модель, — в [`cad/measurements.md`](../cad/measurements.md).

---

## 3. Схема подключения

Схема соединений: модули подключены к выводам платы ESP32-S3, питание от аккумулятора через модуль заряда, тумблер и две клеммы

**Как читать схему.** Номера у платы — как подписаны на самой плате, если держать её **надписями к себе, разъёмами USB вниз**: левый ряд начинается с 3V3, правый — с G. «Вывод 4» — это штырёк с подписью «4», а не четвёртый по счёту. Метки у выводов питания: «5 В» и «GND» — провод идёт в клемму, «3,3 В» — на штырёк 3V3 платы (их два), «G на плате» — на штырёк G самой платы, **не в клемму**.

Почти все сигнальные провода — **провода мама-мама**: у них на концах пластиковые колодки, которые надеваются на штырёк, без пайки. Паяются только детали без штырьков: провода держателя аккумулятора, модуль заряда, кольцо, тумблер, динамик, диод и два резистора делителя. А ещё гребёнки штырьков (полоски штырьков) на микрофон и усилитель, если продавец их не припаял.

### Выводы платы

Источник правды — [`firmware/walkie/config.h`](../firmware/walkie/config.h). Поменяли провод — поменяйте номер и там, и пересоберите прошивку.

| Вывод платы | Куда | Зачем |
|---|---|---|
| 4 | микрофон WS | I2S — цифровая шина звука из трёх проводов; WS — такт «левый/правый канал» |
| 5 | микрофон SCK | I2S, такт битов |
| 6 | микрофон SD | I2S, данные с микрофона |
| 7 | усилитель DIN | I2S, данные на динамик |
| 15 | усилитель BCLK | I2S, такт битов |
| 16 | усилитель LRC | I2S, такт каналов |
| 17 | усилитель SD | включение усилителя: прошивка гасит его в тишине, чтобы динамик не шипел |
| 18 | кольцо DI (DIN) | управление светодиодами |
| 1 | кнопка «говорить», контакт 1 | второй контакт кнопки — на GND |
| 2 | регулятор CLK | поворот |
| 42 | регулятор DT | поворот |
| 41 | регулятор SW | нажатие на ручку |
| 8 | середина делителя заряда | прошивка меряет напряжение аккумулятора |
| 3V3 (первый) | микрофон VDD | питание 3,3 В |
| 3V3 (второй) | регулятор «+» | питание **только 3,3 В** |
| G, правый ряд, верхний | микрофон GND | |
| G, правый ряд, предпоследний | микрофон L/R | L/R на землю — микрофон работает в левом канале |
| G, правый ряд, нижний | регулятор GND | |
| 5V (на клоне — 5Vin), левый ряд, предпоследний | клемма 5 В | плата питается от модуля заряда |
| G, левый ряд, нижний | клемма GND | |

### Питание

- Провода держателя аккумулятора: красный → **B+** модуля заряда, чёрный → **B−**.
- Делитель заряда: резистор 100 кОм от **B+** к «середине», второй 100 кОм от «середины» к **B−**, «середина» → вывод **8**.
- **OUT+** модуля заряда → тумблер → **клемма 5 В**.
- **OUT−** модуля заряда → **клемма GND**.

Модуль заряда соединён с аккумулятором всегда, тумблер разрывает только выход 5 В. Поэтому рация заряжается и с выключенным тумблером.

### Клеммы: две общие шины

Клемма СМК 221-415 — соединитель на 5 гнёзд под рычажками. Внутри все гнёзда замкнуты одной медной пластиной: всё, что вставлено в одну клемму, соединено между собой. В рации два таких общих узла, поэтому **клемм на каждую рацию две**:

- **клемма 5 В** — 4 провода, одно гнездо свободно: от тумблера (на нём OUT+ модуля заряда) · 5V платы · Vin усилителя · 5V кольца через диод;
- **клемма GND** — 5 проводов, заполнена: OUT− модуля заряда · G платы (левый ряд, нижний) · GND усилителя · GND кольца · контакт 2 кнопки.

Микрофон и регулятор в клеммы не идут: их земля и питание берутся со штырьков самой платы.

> **Провод 5 В и провод GND никогда не вставляйте в одну клемму.** Это короткое замыкание: модуль заряда отключится или сгорит. Если клемма пока одна — используйте её под GND, а четыре провода 5 В скрутите, пропаяйте и закройте термоусадкой.

**Как вставить тонкий провод в клемму.** Жила провода мама-мама тоньше, чем клемма держит надёжно. Зачистите конец на **20–22 мм**, сложите жилу **вдвое** и плотно скрутите — получится двойной кончик 10–11 мм. Откройте рычажок, вставьте до упора, закройте и подёргайте: провод не должен выходить. Паять кончик не нужно. Без этого рация может сама перезагружаться от тряски, а такую неисправность потом очень трудно найти.

### Делитель заряда

Рация следит за зарядом по выводу 8, а он выдерживает не больше 3,3 В. Аккумулятор даёт до 4,2 В. Два одинаковых резистора по 100 кОм подряд делят напряжение ровно пополам, и в точке между ними не больше 2,1 В. Ток через них ≈ 0,02 мА — аккумулятор они не сажают.

1. Скрутите по одной ножке двух резисторов — это «середина».
2. У провода мама-мама отрежьте один разъём, зачистите 5 мм, подкрутите к середине и пропаяйте все три; сверху термоусадка.
3. Свободную ножку первого резистора припаяйте к площадке **B+** модуля заряда (там же красный провод аккумулятора), второго — к **B−** (там же чёрный).
4. Разъём провода наденьте на штырёк **8** платы, пока плата вне корпуса. Если держать плату надписями к себе, USB вниз, это 12-й штырёк сверху в левом ряду.

У резисторов нет «плюса», их можно ставить любой стороной. Подключайте к **B+ / B−**, не к OUT+. Ножки укоротите бокорезами до 5–8 мм и каждую пайку закройте термоусадкой: голая ножка от B+ не должна касаться других деталей. Без делителя рация работает, но не узнает, что аккумулятор садится.

### Все провода одной рации

Длина — сколько провода нужно по трассе в корпусе, с запасом ≈ 3 см. Провод, который идёт в клемму или на пайку, отрежьте по месту. Провода с разъёмами на обоих концах укоротить нельзя: лишнее сложите у мостика в канале и стяните (можно взять набор мама-мама по 10 см — их уйдёт 9 на рацию).

«Сложить вдвое» — конец, который идёт в клемму: зачистить 20–22 мм и сложить, как описано выше.

| № | Откуда | Куда | Чем | Длина |
|---|---|---|---|---|
| | **Микрофон INMP441** | | | |
| 1 | вывод 4 | WS | провод мама-мама | ≈ 10 см |
| 2 | вывод 5 | SCK | провод мама-мама | ≈ 10 см |
| 3 | вывод 6 | SD | провод мама-мама | ≈ 10 см |
| 4 | 3V3 (первый) | VDD | провод мама-мама | ≈ 10 см |
| 5 | G, правый ряд, верхний | GND | провод мама-мама | ≈ 10 см |
| 6 | G, правый ряд, предпоследний | L/R | провод мама-мама | ≈ 15 см |
| | **Усилитель MAX98357A** (выводы по порядку: LRC, BCLK, DIN, GAIN, SD, GND, Vin) | | | |
| 7 | вывод 7 | DIN | провод мама-мама | ≈ 10 см |
| 8 | вывод 15 | BCLK | провод мама-мама | ≈ 10 см |
| 9 | вывод 16 | LRC | провод мама-мама | ≈ 10 см |
| 10 | вывод 17 | SD | провод мама-мама | ≈ 10 см |
| 11 | клемма 5 В | Vin | провод мама-мама, разъём у клеммы отрезать, сложить вдвое | ≈ 20 см |
| 12 | клемма GND | GND | провод мама-мама, разъём у клеммы отрезать, сложить вдвое | ≈ 20 см |
| 13 | динамик «+» | площадка «+» усилителя | целый провод из набора, разъёмы срезать; пайка с обеих сторон | ≈ 17 см |
| 14 | динамик «−» | площадка «−» усилителя | так же. GAIN никуда не подключается | ≈ 17 см |
| | **Кольцо WS2812B** | | | |
| 15 | вывод 18 | DI (вход) | провод мама-мама, один разъём отрезать, к кольцу — пайка | ≈ 15 см |
| 16 | клемма 5 В | 5V кольца | провод, разъёмы срезать; в разрыв — диод 1N4007 **полоской к кольцу**, пайка + термоусадка; конец в клемму сложить вдвое | ≈ 14 см |
| 17 | клемма GND | GND кольца | провод мама-мама, разъём у клеммы отрезать, сложить вдвое; к кольцу — пайка | ≈ 14 см |
| | **Кнопка «говорить» PBS-28B-2** | | | |
| 18 | вывод 1 | контакт 1 | провод мама-мама, один разъём отрезать; к кнопке — под винт | ≈ 15 см |
| 19 | клемма GND | контакт 2 | провод, разъёмы срезать; к кнопке — под винт, конец в клемму сложить вдвое | ≈ 15 см |
| | **Регулятор KY-040** | | | |
| 20 | вывод 2 | CLK | провод мама-мама, второй разъём — на штырёк регулятора | ≈ 20 см |
| 21 | вывод 42 | DT | так же | ≈ 20 см |
| 22 | вывод 41 | SW | так же | ≈ 20 см |
| 23 | 3V3 (второй) | + | так же — **только 3,3 В** | ≈ 20 см |
| 24 | G, правый ряд, нижний | GND | так же | ≈ 20 см |
| | **Питание платы** | | | |
| 25 | 5V / 5Vin | клемма 5 В | провод мама-мама, разъём у клеммы отрезать, сложить вдвое | ≈ 15 см |
| 26 | G, левый ряд, нижний | клемма GND | провод мама-мама, разъём у клеммы отрезать, сложить вдвое | ≈ 15 см |
| 27 | вывод 8 | середина делителя | провод мама-мама, один разъём отрезать, к резисторам — пайка | ≈ 10 см |
| | **Аккумулятор и зарядка** | | | |
| 28 | держатель 18650, красный | B+ модуля заряда | свой провод держателя, пайка | — |
| 29 | держатель 18650, чёрный | B− модуля заряда | свой провод держателя, пайка | — |
| 30 | B+ модуля заряда | резистор → середина → резистор → B− | пайка выводами резисторов | — |
| 31 | OUT+ модуля заряда | тумблер, один вывод | целый провод, разъёмы срезать; пайка с обеих сторон | ≈ 20 см |
| 32 | тумблер, второй вывод | клемма 5 В | провод, разъёмы срезать; к тумблеру — пайка, конец в клемму сложить вдвое | ≈ 10 см |
| 33 | OUT− модуля заряда | клемма GND | провод, разъёмы срезать; к модулю — пайка, конец в клемму сложить вдвое | ≈ 17 см |

### Где легко ошибиться

- **Регулятор KY-040 — только к 3,3 В.** На модуле стоят резисторы, подтягивающие выводы к его «+». От 5 В на входы платы попадёт лишнее напряжение, и они сгорят.
- **Микрофон — тоже только 3,3 В** (VDD на 3V3).
- **Пропаяйте все шесть штырьков микрофона.** Типичная неисправность — непропаянный SCK: рация передаёт тишину, а мост пишет «в передаче одна тишина — проверьте микрофон».
- **Диод 1N4007 — полоской к кольцу.** Диод снижает питание кольца примерно до 4,3 В, и тогда сигнала 3,3 В с платы ему хватает уверенно. Без диода кольцо может мигать «не теми» цветами.
- **Провод с вывода 18 — на площадку DI (вход) кольца**, не на DO (выход).
- **Минус динамика не соединяйте с GND:** у этого усилителя оба выхода рабочие.
- **Вывод GAIN усилителя оставьте свободным:** громкость задаёт регулятор.
- **Делитель — к B+ / B−,** не к OUT+.
- **Клемма 5 В и клемма GND — две разные клеммы.** Провод 5 В в клемме GND — короткое замыкание.
- **Концы в клеммах — сложенные вдвое.** Одинарная тонкая жила держится плохо.

---

## 4. Сборка корпуса

Схема сборки: лицевая часть со спины, крышка снята. Вверху полка с двумя клеммами над динамиком, регулятор и тумблер; посередине плата ESP32-S3 с лапкой и держатель аккумулятора, между ними канал для проводов; внизу модуль заряда, микрофон под планкой и усилитель

**Где что.** Всё собирается в лицевой части. Она лежит лицом на столе, а вы смотрите в неё со спины, как на рисунке. Поэтому бок с кнопкой «говорить» на рисунке и на столе — **справа** (хотя спереди он левый). Дальше места названы так: «у бока с кнопкой» и «у другого бока».

На рисунке кружки с крестиком — саморезы: 2 у полки, 1 у лапки платы, 2 у держателя аккумулятора, 2 у планки микрофона. Пустые кружки по углам — стойки под 4 шурупа крышки. Пунктир — то, что спрятано под полкой: динамик и стакан кольца, а вверху — плата регулятора.

### Шаг 1. Прошивка — до сборки

Прошейте и настройте плату, пока она не в корпусе: потом её гнездо USB-C окажется внутри. Как — в [инструкции по прошивке](SETUP.md#1-прошивка). Дальше рация обновляется по воздуху, через мост, либо файлом на своей странице.

**Проверка микрофона на столе (по желанию).** Сначала припаяйте к микрофону гребёнку штырьков (шаг 2, пункт 1). Наденьте на прошитую плату провода 1–6 к микрофону и подключите её кабелем. Откройте монитор порта (например, в Arduino IDE: скорость 115200, конец строки — «Новая строка», иначе команда не выполнится; подробнее — [Команды по USB](SETUP.md#5-команды-по-usb)) и отправьте команду `micraw`. Плата ответит строкой `OK micraw кадров … L: … R: …`. Числа после `L:` должны быть заметно разными и меняться, если хлопнуть рядом. `L: 0…0` или два одинаковых числа — микрофон молчит: проверьте пайку штырьков (чаще всего SCK) и провод L/R → G.

### Шаг 2. Пайка на столе

Всё это делается до установки в корпус: потом к винтам кнопки и к тумблеру уже не подобраться. Термоусадку (кусочек ≈ 15 мм) надевайте на провод **до** пайки, потом её не надеть. После пайки надвиньте трубку на спайку и прогрейте феном или боком жала.

1. **Гребёнки штырьков** на микрофон и усилитель, если продавец их не припаял. У микрофона штырьки — на сторону **без деталей** (там дырочка для звука), у усилителя — на сторону **с деталями**. Хвосты штырьков с обратной стороны откусите. Пропаяйте каждый штырёк.
2. **Динамик:** два целых провода ≈ 17 см от лепестков динамика к площадкам «+» и «−» усилителя (провода 13, 14).
3. **Кольцо:** три провода — DI, 5V с диодом полоской к кольцу, GND (провода 15–17).
4. **Аккумулятор и делитель:** провода держателя — к B+ и B− модуля заряда, к тем же площадкам — делитель заряда (провода 27–30).
5. **Тумблер:** OUT+ модуля — проводом ≈ 20 см к одному выводу тумблера; ко второму выводу — провод, который пойдёт в клемму 5 В; к OUT− — провод ≈ 17 см к клемме GND (провода 31–33).
6. **Кнопка:** два провода под винты (провода 18, 19). Жилу заворачивайте крючком по часовой стрелке — тогда винт её затягивает, а не выталкивает.
7. **Регулятор паять не нужно:** колодки проводов мама-мама надеваются прямо на штырьки, в стенке корпуса для них есть карман. Штырьки не укорачивайте. Если колодки всё же не помещаются — отрежьте их и припаяйте провода прямо к штырькам.

### Шаг 3. Детали в лицевую часть — в таком порядке

Лицевая часть лежит лицом на столе.

1. **Белый диск.** 3–4 капли прозрачного клея (не термоклея) на скос гнезда, затем вдавите диск снаружи, заподлицо с лицом.
2. **Кольцо, прокладка, динамик.** Изнутри в стакан положите **кольцо** светодиодами к диску, площадками с проводами вниз (к плате ESP). Сверху — **прокладку**, вырезом туда же, к площадкам. В её квадратное гнездо — **динамик** фланцем, лепестками вбок. Ничего не клейте: всю стопку потом прижмёт полка.
3. **Регулятор** — в отверстие сверху ближе к середине. Втулку — изнутри, гребёнкой штырьков к другому боку, в свободный угол, подальше от тумблера. Гайку закрутите снаружи.
4. **Тумблер** — в отверстие сверху у бока с кнопкой, поперёк корпуса: рычажок ходит к лицу и к спине.
5. **Кнопка** — в отверстие на боку, гайку изнутри затяните.
6. **Модуль заряда** — в паз внизу у бока с кнопкой: на ребро, гнездом USB-C вниз в окно в дне. Резисторами делителя — к стенке с кнопкой: с этой стороны паз открыт сверху. Провода от его площадок — к вам.
7. **Микрофон** — в колечко внизу посередине, деталями (капсюлем) к лицу. Два столбика штырьков встанут слева и справа от центра. Сначала наденьте на штырьки колодки проводов 1–6, потом положите **планку** между столбиками и вверните 2 самореза 3 × 10 (не длиннее 10 мм, иначе проткнут лицо).
8. **Усилитель** — в гнездо внизу у другого бока, штырьками к вам. Гребёнкой вверх или вниз — как удобнее проводам. Сначала заведите край платы, что у стенки корпуса, под козырёк, потом прижмите другой край (к микрофону): он по скосу проскочит под зуб, стенка там пружинит. Прямо сверху на оба края не давите.
9. **Держатель аккумулятора**, пока без аккумулятора, — на две стойки у другого бока: 2 шурупа 3 × 12 изнутри, через его отверстия в дне (**не длиннее 12 мм**). Поверх держателя провода не кладите: до крышки над ним ≈ 2 мм.
10. **Плата ESP32-S3.** Пока плата в руках (надписями к себе, USB вниз), наденьте разъёмы проводов 1–10, 15, 18, 20–27 — номера выводов сейчас видны. Потом переверните плату модулем к лицу рации и уложите в гнездо у бока с кнопкой **антенной вниз**: сначала заведите два нижних угла под козырьки, потом положите плату на площадки. Ряд с выводами 3V3…8 и 5V окажется у канала для проводов, ряд с выводами 1, 2, 42, 41 — у стенки с кнопкой. На уложенной плате штырьки уже не сосчитать: надписи внизу, ряды поменялись местами. Наденьте **лапку** отверстием на штырёк стойки и вверните 1 саморез 3 × 10 — она прижмёт плату посередине. Вынуть плату можно в любой момент, отвернув этот саморез.
11. **Полка.** Вдавите клеммы в её гнёзда рычажками вверх (к вам), стороной с отверстиями для проводов — к боковым стенкам корпуса: клемму 5 В — в гнездо у стенки с кнопкой (рядом с тумблером), клемму GND — в другое. **Шайбу** положите на магнит динамика плоской стороной, штырьком к себе. Полку наденьте отверстием на штырёк шайбы, поставьте на две стойки у боков и вверните 2 самореза 3 × 10 до упора полки в стойки: шайба прижмёт динамик, а с ним кольцо и белый диск.

> **Антенна** — выступ модуля ESP32-S3 без металлической крышки, он выходит за край платы. Не прижимайте к ней провода и металл и не складывайте рядом лишнюю длину проводов.

### Шаг 4. Провода

Вторые концы — по списку, по номерам. Концы в клеммы — сложенные вдвое. Куда вести:

- микрофон и усилитель — коротко, к ряду выводов платы у канала;
- провода кнопки — вдоль стенки с кнопкой; провода регулятора — поверх платы вверх и через верх к регулятору, мимо края полки у другого бока;
- провода в клеммы подводите вдоль боковых стенок, там у клемм отверстия: к клемме 5 В — вдоль стенки с кнопкой, к клемме GND — вдоль другой стенки. Под полкой у каждого бока есть прорезь для стяжки;
- OUT+ от модуля заряда к тумблеру — вдоль стенки с кнопкой: над колодками платы, над кнопкой и мимо клеммы 5 В. OUT− к клемме GND — наискось поверх платы и канала;
- провода динамика — из-под полки (там зазор над магнитом) в канал и по каналу вниз к усилителю, в обход колодок на его гребёнке;
- пучок в канале стяните у мостиков стяжками 2,5 мм, продев их под мостик. Лишнюю длину складывайте у мостика, а не у антенны (низ платы).

### Шаг 5. Ручка

Насадите ручку на вал с зазором 1,5–2 мм над торцом втулки и нажмите: должен быть щелчок. Это нажатие на регулятор, им выключается звук.

### Шаг 6. Проверка до закрытия

**Мультиметром, пока аккумулятор не вставлен.** В режиме прозвонки коснитесь щупами второго вывода тумблера (того, что идёт в клемму 5 В) и площадки OUT− модуля заряда. Короткий писк и тишина — нормально: заряжаются конденсаторы. Непрерывный писк — где-то замыкание; первым делом ищите провод 5 В в клемме GND.

**Мультиметром, с аккумулятором.** Вставьте аккумулятор, плюс — по метке на держателе. На площадках B+ и B− модуля заряда должно быть 3,0–4,2 В, а на середине делителя — ровно половина.

**Включите тумблер** (не загорелось — щёлкните в другую сторону). Кольцо сразу вспыхнет **белым**. Дальше:

- рация, которая ещё не знает Wi-Fi, сразу начнёт медленно «дышать» **фиолетовым**: открыта точка настройки RADIO-XXXX. Так и должно быть, Wi-Fi вводится с телефона (см. [Способ 2. С телефона](SETUP.md#способ-2-с-телефона));
- рация, которая уже знает Wi-Fi, покажет бегущий **синий** огонёк (ищет сеть), а на связи с мостом прозвучит «ти-ду» и пойдут короткие **зелёные** вспышки раз в 3 секунды.

Пока крышка открыта, за минуту проверьте то, что потом спрячется. Связь с мостом для этого не нужна:

| Что сделать | Что должно быть | Что это проверяет |
|---|---|---|
| Покрутить регулятор | кольцо показывает громкость белой полосой, в динамике щелчки; по часовой — громче | регулятор, усилитель, динамик |
| Коротко нажать на ручку | полоса становится фиолетовой — звук выключен; ещё нажатие — щелчок, звук снова есть | кнопку регулятора |
| Нажать кнопку «говорить» без связи с мостом | низкий гудок и быстрое оранжевое мигание («связи нет, говорить нельзя») | кнопку «говорить» |
| Подержать ручку 1–4 с и отпустить | шкала заряда: зелёная (больше 40 %), янтарная (16–40 %) или красная (15 % и меньше). Первые 20 секунд после включения — тусклый белый: заряд ещё измеряется | делитель заряда |

Когда рация на связи с мостом, проверьте и микрофон: нажмите кнопку — «пи-пи», кольцо загорится красным и будет «плясать» в такт голосу. Другая рация вас услышит, а на странице моста эта рация будет отмечена как говорящая.

**Если что-то не так:**

| Признак | Что проверить |
|---|---|
| Кольцо не загорелось ни разу за 10 секунд | тумблер, провода в клемме 5 В, диод (полоской к кольцу), провод с вывода 18 на DI, а не на DO |
| Кольцо мигает «не теми» цветами | диод в проводе 5V кольца, GND кольца в клемме GND |
| Нет щелчков и звуков | Vin и GND усилителя в клеммах, провода 7–10 на выводах 7, 15, 16, 17, провода динамика на «+» и «−» усилителя |
| Громкость меняется наоборот | поставьте галочку «Регулятор крутится наоборот» на странице рации или поменяйте местами провода CLK и DT |
| Регулятор не откликается | «+» регулятора на 3V3, его GND на G платы, провода на выводах 2, 42, 41 |
| На шкале заряда синий цвет, хотя рация на аккумуляторе | рация не видит делитель: провод 27 на выводе 8, резисторы на B+ и B− |
| Мост пишет «в передаче одна тишина — проверьте микрофон» | пайку всех штырьков микрофона (особенно SCK), VDD на 3V3, L/R на G. Если L/R подключён к 3,3 В — поставьте галочку «Микрофон на правом канале» на странице рации |
| Рация сама перезагружается, когда её трясут | концы проводов в клеммах: сложены ли вдвое, держатся ли |
| Рация сама выключается, когда долго лежит без дела | модуль заряда отключает слишком маленькую нагрузку: проверьте, что «Экономия аккумулятора» на странице рации выключена |

Остальные признаки и что с ними делать — в [Если что-то не работает](TROUBLESHOOTING.md).

### Шаг 7. Закройте

Крышка — просто крышка, к ней не идёт ни одного провода. Положите её сверху и проверьте, что ни один провод не лёг на её бортик. Вверните четыре потайных шурупа 3 × 12 — без усилия, это пластик.

Рация собрана. Дальше — Wi-Fi, ключ сети и мост: [Прошивка и настройка](SETUP.md) и [Свой мост](BRIDGE.md).

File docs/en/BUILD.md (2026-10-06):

[Русский](../BUILD.md) · **English**

# Building the radio

From buying the parts to closing the back cover. Flashing, Wi-Fi and the bridge are covered separately: [Flashing and setup](SETUP.md) and [Your own bridge](BRIDGE.md).

The assembled radio: a bar with the white lens disc over the speaker, a button on the side, the volume knob and the power switch on top

The radio is a 68 × 38 × 170 mm bar:

- **front** — the speaker behind a white lens disc; a ring of 12 LEDs glows through the disc around the speaker grille; at the bottom — the microphone hole;
- **left side** (as seen from the front) — the PTT ("push-to-talk") button;
- **top** — the volume knob, the on/off power switch and a lanyard loop;
- **bottom** — the USB-C socket for charging.

All the hardware is mounted to the front shell of the case; the back cover is just a cover: not a single wire goes to it. The case prints without supports. There is no glue or tape inside: everything is held by self-tapping screws, snap-fits and slots. Glue is needed only for the white lens disc.

**Order of work:** buy the parts → print the case → flash the board → solder the sub-assemblies on the bench → assemble in the case → test → close.

Contents:

1. [Parts for one radio](#1-parts-for-one-radio)
2. [Printing the case](#2-printing-the-case)
3. [Wiring diagram](#3-wiring-diagram)
4. [Assembling the case](#4-assembling-the-case)

---

## 1. Parts for one radio

Prices are approximate, in rubles, from Russian stores as of September 2026, excluding shipping. The stores are given only as examples: all of these parts are common and the same ones can be bought anywhere (AliExpress etc.), as long as the dimensions match (see the list below).

| Part | Qty | ≈ Price | Where to buy (example) |
|---|---|---|---|
| ESP32-S3-DevKitC-1 N16R8 board, pins already soldered | 1 | 816 ₽ | [Ozon](https://www.ozon.ru/product/otladochnaya-plata-esp32-s3-devkitc-1-n16r8-wi-fi-bluetooth-usb-c-dlya-arduino-esp-idf-micropython-5648908176/) |
| INMP441 microphone (digital, round board) | 1 | 600 ₽ | [Ozon](https://www.ozon.ru/product/modul-vsenapravlennogo-mikrofona-na-inmp441-mems-i2s-4314549062/) |
| MAX98357A amplifier, 3 W | 1 | 180 ₽ | [duino.ru](https://duino.ru/usilitel-moshchnosti-3-vt-s-tsap-dac-i-shinoy-i2s/) |
| FBS3232 speaker, 8 Ω, 3 W, 32 × 32 mm | 1 | 470 ₽ | [Chip-Dip](https://www.chipdip.ru/product/fbs3232-8-om-3vt-32-32-14.7mm-bez-markirovki-dinamik-fbele-9001621604), item 9001621604 |
| WS2812B 12-LED ring, Ø50 mm | 1 | 466 ₽ | [Ozon](https://www.ozon.ru/product/koltso-iz-12-adresnyh-svetodiodov-ws2812b-714069208/) |
| KY-040 volume knob (rotary encoder with push button) | 1 | ≈ 113 ₽ (set of 3 — 338 ₽) | [Ozon](https://www.ozon.ru/product/modul-povorotnogo-enkodera-hw-040-ky-040-5v-20-shagov-na-oborot-dlya-arduino-3-sht-1509157901/) |
| PBS-28B-2 vandal-resistant push button, 16 mm | 1 | 260 ₽ | [Chip-Dip](https://www.chipdip.ru/product/pbs-28b-2-d-16-mm-steel-knopka-antivandalnaya-9000219084), item 9000219084 |
| MTS-101 mini toggle switch | 1 | 55 ₽ | [Chip-Dip](https://www.chipdip.ru/product/mts-101-on-off-mikrotumbler-spst-3a-250v-20-mom-ruichi-9000344178), item 9000344178 |
| "Power Bank Mini" charger module, USB-C input, 5 V 2 A output | 1 | 159 ₽ | [Ozon](https://www.ozon.ru/product/modul-power-bank-mini-s-gnezdom-type-c-5v-2a-arduino-561634064/) |
| 18650 battery, e.g. EVE INR18650-35V, 3500 mAh | 1 | 380 ₽ | [Chip-Dip](https://www.chipdip.ru/product/eve-inr18650-35v-akkumulyator-li-ion-18650-3500mah-10a-9001581130), item 9001581130 |
| 1 × 18650 battery holder with leads | 1 | 79 ₽ | [Chip-Dip](https://www.chipdip.ru/product/kls5-18650-l-fc1-5216-batareynyy-otsek-1x18650-9000296086), item 9000296086 |
| SMK 221-415 5-way lever connector (WAGO 221-415 type) | 2 | 33 ₽ × 2 | [Chip-Dip](https://www.chipdip.ru/product/smk-221-415-klemma-stroitelno-montazhnaya-5pin-kvt-9001187576), item 9001187576 |
| Female-female jumper wires, 20 cm, set of 40 | 1 set (≈ 30 used) | 211 ₽ (price when buying 3 sets or more) | [Chip-Dip](https://www.chipdip.ru/product/soedinitelnye-provoda-mama-mama-40-sht-20-sm-shleyf-iz-9001322249), item 9001322249 |
| 100 kΩ resistor, 0.25 W | 2 | 6 ₽ × 2 | [Chip-Dip](https://www.chipdip.ru/product/cf-25-s1-4-0.25vt-100-kom-5-rezistor-uglerodistyy-9549), item 9549 |
| 1N4007 diode | 1 | 6 ₽ | [Chip-Dip](https://www.chipdip.ru/product/1n4007-diod-vypryamitelnyy-1a-1000v-do-41-do-204ac-diotec-9000461664), item 9000461664 |
| Countersunk wood screw 3 × 12: 4 for the back cover + 2 for the battery holder | 6 (pack of 40) | 45 ₽ per pack | [Chip-Dip](https://www.chipdip.ru/product/0125030012p300004010-shurup-po-derevu-potay-shlits-steelrex-9000688284), item 9000688284 |
| Self-tapping screw 3 × 10 for wood or plastic: speaker shelf, board clamp, mic clamp plate | 5 | — | any hardware store |
| Heat-shrink tubing, set of assorted diameters | ≈ 10 pieces of 15 mm | 150 ₽ per set | [Chip-Dip](https://www.chipdip.ru/product/xbt-universal-nabor-termousadochnoy-trubki-100m-21-sht-xibo-9002098269), item 9002098269 |
| PLA filament for the case + white PLA or PETG for the white lens disc | ≈ 145 g | ≈ 220 ₽ (at 1,500 ₽ per kg) | any |
| 2.5 mm cable ties — optional, for the wire bundle | 2 | — | any |

**Total ≈ 4,200 ₽ per radio** if you build three at once (the sets and packs are split three ways). A single radio on its own costs ≈ 4,500 ₽: the volume knob, heat-shrink and screws are sold in sets. The 3 × 10 self-tapping screws and the cable ties are not included in the total.

### What matters when buying

The case is designed around specific dimensions. If your part is different, compare it with this list. If it doesn't match, change the number in the header of [`cad/radio_handheld.scad`](../../cad/radio_handheld.scad) and export the STL again (see [section 2](#if-you-need-to-modify-the-case)).

- **ESP32-S3 board.** The seat is for a 63 × 28 mm board with two rows of 22 pins (the YD-ESP32-S3 clone; on it the 5V pin is labelled "5Vin"). The firmware needs 4 MB of flash or more, so both N8 and N16R8 will do. Pin numbers are the same on the original DevKitC-1 and on the clones.
- **INMP441 microphone** — a round Ø13.4 mm board, two columns of 3 pins: SD·VDD·GND and SCK·WS·L/R.
- **MAX98357A amplifier** — a 17.3 × 18.8 mm board, without the screw terminal block.
- **Speaker** — 32 × 32 mm flange, 14.7 mm deep, Ø27.3 mm magnet.
- **WS2812B ring** — Ø50 mm outside, Ø36 mm inside, 2.5 mm thick including the contact pads.
- **KY-040 volume knob** — M7 bushing with 12 mm of thread, Ø5.8 mm shaft with a 4.2 mm flat (a D-shaped flat cut). If your shaft has fine knurling instead of a flat, you will have to adjust the knob cap to fit.
- **MTS-101 power switch** — M6 thread, body behind the panel 14 × 12.7 × 7.8 mm.
- **PBS-28B-2 button** — M16 thread, takes up Ø14.6 × 20.3 mm inside the case, screw terminals.
- **Charger module** — 20 × 26 × 4 mm, USB-C socket on the short edge. Inside it works like a power bank: if the radio draws very little current, the module may decide the load has been disconnected and cut the power. That's why «Экономия аккумулятора» (Battery saving) is off by default in the radio's settings — don't turn it on unless you need to.
- **18650 holder** — 77.5 × 20.5 × 21 mm, two Ø3 holes in the bottom, 55 mm apart.
- **SMK 221-415 lever connectors** — 19.4 × 29.8 × 9.6 mm.

### Tools

- 40–60 W soldering iron, flux-core solder;
- multimeter;
- side cutters, utility knife, round needle file — to clean up holes after printing;
- Pz1 cross-head screwdriver;
- clear glue: «Момент Кристалл» (Moment Crystal, a clear contact adhesive) or superglue (not hot glue) — for the white lens disc;
- a hot-air gun, or a lighter as a last resort — for heat-shrink;
- a USB-C cable that carries data (not a charge-only one) — for flashing;
- any USB-C charger — to charge the radio.

---

## 2. Printing the case

All STL files are in the [`stl/`](../../stl) folder. An STL is a file with the 3D shape of a part; it is opened in a slicer (a program that "slices" the model into layers for the printer). The parts are already rotated the way they should be placed on the build plate: **do not rotate them**. No supports are needed.

### Required parts — for one radio

| File | What it is | Orientation on the plate | Size, mm | ≈ g |
|---|---|---|---|---|
| [`front.stl`](../../stl/front.stl) | **Front shell**: face, sides, top and bottom in one piece; inside are the seats and posts for all the hardware | face down | 68 × 177 × 36 | 89 |
| [`back.stl`](../../stl/back.stl) | **Back cover**, 4 countersunk 3 × 12 screws | outer side down | 68 × 170 × 4 | 32 |
| [`shelf.stl`](../../stl/shelf.stl) | **Speaker shelf**: clamps the speaker together with the LED ring and the disc, holds both lever connectors; 2 self-tapping screws 3 × 10 | plate down | 60 × 32 × 7 | 9 for all four |
| [`spk_puck.stl`](../../stl/spk_puck.stl) | **Speaker puck**: presses on the magnet, its pin goes into the hole in the shelf | flat | Ø20 × 5 | ↑ |
| [`dk_arm.stl`](../../stl/dk_arm.stl) | **ESP board clamp**: holds the board down in the middle; 1 self-tapping screw 3 × 10 | bar down | 24 × 12 × 12 | ↑ |
| [`mic_cap.stl`](../../stl/mic_cap.stl) | **Mic clamp plate**: sits between the two columns of the microphone's pins; 2 self-tapping screws 3 × 10 | bar down | 6.5 × 40 × 9 | ↑ |
| [`spacer.stl`](../../stl/spacer.stl) | **Spacer** between the LED ring and the speaker | flat | Ø50 × 3 | 7 for both |
| [`knob.stl`](../../stl/knob.stl) | **Knob cap** for the volume knob | top down | Ø20 × 14 | ↑ |
| [`lens.stl`](../../stl/lens.stl) | **White lens disc** for the speaker. Print it in **white**: the LED ring shines through it | flat | Ø54 × 1.6 | 4.5 |

The case set without the disc takes **≈ 140 g of filament and ≈ 5 h 45 min** on a Bambu Lab P2S ("0.16mm High Quality" profile, time including heat-up and bed calibration). On a 256 × 256 mm plate the whole set prints in one go; the longest part, the front shell, needs a plate of at least 180 mm.

### Test pieces — optional

You don't have to print them, but they quickly show whether your printer and your parts fit before you spend 5–6 hours on the case.

| File | What it checks |
|---|---|
| [`edge_test.stl`](../../stl/edge_test.stl) | A 68 × 36 × 12 mm piece of the front shell with a rounded edge and lettering: how your printer handles the edge at the face and the stencil letters. |
| [`shaft_gauge.stl`](../../stl/shaft_gauge.stl) | Volume knob shaft gauge: three D-shaped holes, numbers 1, 2, 3 cut into the top. No. 1 — Ø6.2 with a 4.6 flat; No. 2 — Ø6.35 / 4.75; No. 3 — Ø6.5 / 4.9. The knob cap `knob.stl` is made for No. 2. If a different hole fits snugly but without force, enter its numbers in `shaft_d` and `shaft_flat` in `cad/radio_handheld.scad` and export the knob cap again. |
| [`coupon.stl`](../../stl/coupon.stl) | An 84 × 72 × 2.4 mm plate with holes for the white lens disc, the button, the power switch, the volume knob and the microphone: for test-fitting the parts you bought. |
| [`enc_spacer.stl`](../../stl/enc_spacer.stl) | 6 spacer rings 3 mm thick (for three radios). Spares: needed only if the bushing thread on your volume knob is longer than usual. The ring goes over the bushing from inside the case, between the volume knob and the wall. |

The edge test piece, the shaft gauge and the knob cap together — ≈ 16 g and ≈ 47 min.

### Print settings

- filament — PLA, any colour for the case; the white lens disc — **white** PLA or PETG;
- 0.4 mm nozzle, **0.16 mm** layer;
- **3 walls**, **15 %** infill;
- supports **off**;
- plate — textured PEI: its pattern will end up on the face of the radio. A smooth plate works too.

The board clamp and the mic clamp plate have one-layer-thick "ears" at the bottom: they hold the small part on the plate; snap them off after printing. If the mic clamp plate still lifts off the build plate, print it separately with a 5 mm brim.

The holes in the walls for the button, the volume knob and the power switch are teardrop-shaped with the point towards the back: when printing face down, their top doesn't sag. If a threaded bushing goes in tight, run a round needle file through the hole.

### Slicing from the command line (Bambu Studio)

If you are on macOS, Bambu Studio is in the Applications folder and your printer is a Bambu Lab P2S, the script [`tools/make_print.sh`](../../tools/make_print.sh) will slice ready-to-print plates by itself:

```bash
tools/make_print.sh                    # all plates → print/ folder
ONLY=1_ tools/make_print.sh            # only plates whose name contains "1_"
PROFILE="0.16mm Standard @BBL P2S" tools/make_print.sh   # a different print profile
```

You will get `print/*.3mf` files with time and gram estimates: `0_пробник_кромки_вала` (edge and shaft test pieces), `1_рация_v3_комплект` (radio v3, full set), `2_планка_микрофона_x2` (mic clamp plate ×2, with brim), `3_белый_диск_x3` (white lens disc ×3), `4_рация_белая_комплект_с_диском` (white radio, full set with the disc). Open the file you need in Bambu Studio and send it to print. With a different printer or slicer, just open the STLs from `stl/` and apply the settings from the list above.

### If you need to modify the case

The case is a parametric [OpenSCAD](https://openscad.org) model in a single file: [`cad/radio_handheld.scad`](../../cad/radio_handheld.scad). All the dimensions of the bought parts and their positions are numbers in the file header. You need a recent OpenSCAD build (snapshot) with the Manifold engine. The lettering on the face is set in the Impact font: if it's not installed on your system, OpenSCAD will substitute another one, and the stencil bridges in the letters may shift.

Export the STLs again (from the project root):

```bash
for p in front back shelf spk_puck dk_arm mic_cap knob; do
  openscad --backend manifold --export-format binstl -D "part=\"${p}_print\"" -o "stl/$p.stl" cad/radio_handheld.scad
done
for p in lens spacer shaft_gauge coupon edge_test; do
  openscad --backend manifold --export-format binstl -D "part=\"$p\"" -o "stl/$p.stl" cad/radio_handheld.scad
done
openscad --backend manifold --export-format binstl -D 'part="enc_spacer_print"' -o stl/enc_spacer.stl cad/radio_handheld.scad
```

After any change, run the four model checks: `check_inside` (parts don't touch each other), `check_walls` (parts don't intrude into the walls), `check_lid` (the back cover fits in place), `check_parts` (the clamping parts don't cut into anything). Each must give an **empty** result — OpenSCAD will report that the object is empty:

```bash
for c in check_inside check_walls check_lid check_parts; do
  openscad --backend manifold -D "part=\"$c\"" -o check.stl cad/radio_handheld.scad
done
```

The part measurements the model is built from are in [`cad/measurements.md`](../../cad/measurements.md).

---

## 3. Wiring diagram

Wiring diagram: the modules are connected to the pins of the ESP32-S3 board, power comes from the battery through the charger module, the power switch and two lever connectors

**How to read the diagram.** The board's pin numbers are as printed on the board itself when you hold it **labels facing you, USB connectors at the bottom**: the left row starts with 3V3, the right row with G. "Pin 4" is the pin labelled "4", not the fourth pin in the row. Labels at the power pins: "5 V" and "GND" — the wire goes into a lever connector; "3.3 V" — to a 3V3 pin on the board (there are two); "G on board" — to a G pin of the board itself, **not into a lever connector**.

Almost all signal wires are **female-female jumper wires**: they have plastic housings at the ends that slip onto a pin, no soldering. Only the parts without pins are soldered: the battery holder leads, the charger module, the LED ring, the power switch, the speaker, the diode and the two resistors of the battery voltage divider. Plus the pin headers (strips of pins) on the microphone and the amplifier, if the seller didn't solder them.

### Board pins

The source of truth is [`firmware/walkie/config.h`](../../firmware/walkie/config.h). If you move a wire, change the number there as well and rebuild the firmware.

| Board pin | Goes to | Why |
|---|---|---|
| 4 | microphone WS | I2S is a three-wire digital audio bus; WS is the left/right channel clock |
| 5 | microphone SCK | I2S, bit clock |
| 6 | microphone SD | I2S, data from the microphone |
| 7 | amplifier DIN | I2S, data to the speaker |
| 15 | amplifier BCLK | I2S, bit clock |
| 16 | amplifier LRC | I2S, channel clock |
| 17 | amplifier SD | amplifier enable: the firmware shuts it off during silence so the speaker doesn't hiss |
| 18 | LED ring DI (DIN) | LED control |
| 1 | PTT button, contact 1 | the button's second contact goes to GND |
| 2 | volume knob CLK | rotation |
| 42 | volume knob DT | rotation |
| 41 | volume knob SW | knob press |
| 8 | middle of the battery voltage divider | the firmware measures the battery voltage |
| 3V3 (first) | microphone VDD | 3.3 V supply |
| 3V3 (second) | volume knob "+" | supply **3.3 V only** |
| G, right row, top | microphone GND | |
| G, right row, second from bottom | microphone L/R | L/R to ground — the microphone works on the left channel |
| G, right row, bottom | volume knob GND | |
| 5V (5Vin on the clone), left row, second from bottom | 5 V lever connector | the board is powered from the charger module |
| G, left row, bottom | GND lever connector | |

### Power

- Battery holder leads: red → **B+** of the charger module, black → **B−**.
- Battery voltage divider: a 100 kΩ resistor from **B+** to the "middle", a second 100 kΩ from the "middle" to **B−**, the "middle" → pin **8**.
- Charger module **OUT+** → power switch → **5 V lever connector**.
- Charger module **OUT−** → **GND lever connector**.

The charger module is always connected to the battery; the power switch only breaks the 5 V output. That's why the radio charges even with the power switch off.

### Lever connectors: two common buses

The SMK 221-415 is a connector with 5 slots under levers. Inside, all the slots are joined by a single copper plate: everything inserted into one connector is connected together. The radio has two such common nodes, so there are **two lever connectors per radio**:

- **5 V connector** (the 5 V bus) — 4 wires, one slot free: from the power switch (charger module OUT+ is on it) · board 5V · amplifier Vin · LED ring 5V through the diode;
- **GND connector** (the GND bus) — 5 wires, full: charger module OUT− · board G (left row, bottom) · amplifier GND · LED ring GND · button contact 2.

The microphone and the volume knob don't go into the lever connectors: their ground and supply are taken from the pins of the board itself.

> **Never put a 5 V wire and a GND wire into the same lever connector.** That's a short circuit: the charger module will shut down or burn out. If you only have one lever connector for now, use it for GND, and twist the four 5 V wires together, solder them and cover with heat-shrink.

**How to put a thin wire into a lever connector.** The core of a female-female jumper wire is thinner than the connector can hold reliably. Strip the end by **20–22 mm**, fold the core **in half** and twist it tightly — you'll get a double tip of 10–11 mm. Open the lever, push the wire all the way in, close the lever and tug: the wire must not come out. There's no need to solder the tip. Without this, the radio may reboot by itself when shaken, and a fault like that is very hard to track down later.

### Battery voltage divider

The radio monitors the charge via pin 8, and that pin tolerates no more than 3.3 V. The battery gives up to 4.2 V. Two identical 100 kΩ resistors in series divide the voltage exactly in half, so the point between them sees no more than 2.1 V. The current through them is ≈ 0.02 mA — they don't drain the battery.

1. Twist one leg of each of the two resistors together — this is the "middle".
2. Cut one connector off a female-female jumper wire, strip 5 mm, twist it onto the middle and solder all three; heat-shrink on top.
3. Solder the free leg of the first resistor to the **B+** pad of the charger module (where the battery's red wire is), and the free leg of the second to **B−** (where the black wire is).
4. Slip the wire's connector onto pin **8** of the board while the board is still outside the case. Holding the board labels facing you, USB at the bottom, it's the 12th pin from the top in the left row.

Resistors have no "plus", they can go either way round. Connect to **B+ / B−**, not to OUT+. Trim the legs with side cutters to 5–8 mm and cover every solder joint with heat-shrink: a bare leg from B+ must not touch other parts. The radio works without the divider, but it won't know the battery is running low.

### All the wires of one radio

Length is how much wire is needed along its route inside the case, with ≈ 3 cm to spare. A wire that goes into a lever connector or to a solder joint is cut to fit in place. Wires with connectors on both ends can't be shortened: fold the excess next to a cable-tie anchor in the channel and tie it up (you can buy a 10 cm female-female set instead — a radio takes 9 of them).

"Fold in half" refers to the end that goes into a lever connector: strip 20–22 mm and fold as described above.

| No. | From | To | With | Length |
|---|---|---|---|---|
| | **INMP441 microphone** | | | |
| 1 | pin 4 | WS | female-female jumper wire | ≈ 10 cm |
| 2 | pin 5 | SCK | female-female jumper wire | ≈ 10 cm |
| 3 | pin 6 | SD | female-female jumper wire | ≈ 10 cm |
| 4 | 3V3 (first) | VDD | female-female jumper wire | ≈ 10 cm |
| 5 | G, right row, top | GND | female-female jumper wire | ≈ 10 cm |
| 6 | G, right row, second from bottom | L/R | female-female jumper wire | ≈ 15 cm |
| | **MAX98357A amplifier** (pins in order: LRC, BCLK, DIN, GAIN, SD, GND, Vin) | | | |
| 7 | pin 7 | DIN | female-female jumper wire | ≈ 10 cm |
| 8 | pin 15 | BCLK | female-female jumper wire | ≈ 10 cm |
| 9 | pin 16 | LRC | female-female jumper wire | ≈ 10 cm |
| 10 | pin 17 | SD | female-female jumper wire | ≈ 10 cm |
| 11 | 5 V connector | Vin | female-female jumper wire, cut off the connector at the lever-connector end, fold in half | ≈ 20 cm |
| 12 | GND connector | GND | female-female jumper wire, cut off the connector at the lever-connector end, fold in half | ≈ 20 cm |
| 13 | speaker "+" | amplifier "+" pad | a whole wire from the set, connectors cut off; soldered at both ends | ≈ 17 cm |
| 14 | speaker "−" | amplifier "−" pad | the same. GAIN is not connected to anything | ≈ 17 cm |
| | **WS2812B LED ring** | | | |
| 15 | pin 18 | DI (input) | female-female jumper wire, cut off one connector, soldered to the ring | ≈ 15 cm |
| 16 | 5 V connector | ring 5V | wire, connectors cut off; a 1N4007 diode spliced in, **stripe towards the ring**, soldered + heat-shrink; the end that goes into the lever connector folded in half | ≈ 14 cm |
| 17 | GND connector | ring GND | female-female jumper wire, cut off the connector at the lever-connector end, fold in half; soldered to the ring | ≈ 14 cm |
| | **PBS-28B-2 PTT button** | | | |
| 18 | pin 1 | contact 1 | female-female jumper wire, cut off one connector; to the button — under the screw | ≈ 15 cm |
| 19 | GND connector | contact 2 | wire, connectors cut off; to the button — under the screw, the end that goes into the lever connector folded in half | ≈ 15 cm |
| | **KY-040 volume knob** | | | |
| 20 | pin 2 | CLK | female-female jumper wire, the other connector onto the volume knob pin | ≈ 20 cm |
| 21 | pin 42 | DT | the same | ≈ 20 cm |
| 22 | pin 41 | SW | the same | ≈ 20 cm |
| 23 | 3V3 (second) | + | the same — **3.3 V only** | ≈ 20 cm |
| 24 | G, right row, bottom | GND | the same | ≈ 20 cm |
| | **Board power** | | | |
| 25 | 5V / 5Vin | 5 V connector | female-female jumper wire, cut off the connector at the lever-connector end, fold in half | ≈ 15 cm |
| 26 | G, left row, bottom | GND connector | female-female jumper wire, cut off the connector at the lever-connector end, fold in half | ≈ 15 cm |
| 27 | pin 8 | middle of the divider | female-female jumper wire, cut off one connector, soldered to the resistors | ≈ 10 cm |
| | **Battery and charging** | | | |
| 28 | 18650 holder, red | charger module B+ | the holder's own lead, soldered | — |
| 29 | 18650 holder, black | charger module B− | the holder's own lead, soldered | — |
| 30 | charger module B+ | resistor → middle → resistor → B− | soldered with the resistor legs | — |
| 31 | charger module OUT+ | power switch, one terminal | a whole wire, connectors cut off; soldered at both ends | ≈ 20 cm |
| 32 | power switch, second terminal | 5 V connector | wire, connectors cut off; soldered to the power switch, the end that goes into the lever connector folded in half | ≈ 10 cm |
| 33 | charger module OUT− | GND connector | wire, connectors cut off; soldered to the module, the end that goes into the lever connector folded in half | ≈ 17 cm |

### Easy places to make a mistake

- **KY-040 volume knob — 3.3 V only.** The module has resistors that pull its pins up to its "+". At 5 V, excess voltage reaches the board's inputs and they will burn out.
- **The microphone is also 3.3 V only** (VDD to 3V3).
- **Solder all six microphone pins.** A typical fault is an unsoldered SCK: the radio transmits silence, and the bridge reports «в передаче одна тишина — проверьте микрофон» ("only silence in the transmission — check the microphone").
- **1N4007 diode — stripe towards the ring.** The diode lowers the LED ring's supply to about 4.3 V, and then the board's 3.3 V signal is reliably enough for it. Without the diode the ring may flash the "wrong" colours.
- **The wire from pin 18 goes to the DI (input) pad of the ring**, not to DO (output).
- **Don't connect the speaker's minus to GND:** both outputs of this amplifier are active.
- **Leave the amplifier's GAIN pin unconnected:** the volume is set by the volume knob.
- **The divider goes to B+ / B−,** not to OUT+.
- **The 5 V connector and the GND connector are two separate lever connectors.** A 5 V wire in the GND connector is a short circuit.
- **Wire ends in the lever connectors are folded in half.** A single thin core holds poorly.

---

## 4. Assembling the case

Assembly diagram: the front shell seen from the back, back cover removed. At the top, the speaker shelf with two lever connectors above the speaker, the volume knob and the power switch; in the middle, the ESP32-S3 board with its clamp and the battery holder, with the wire channel between them; at 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

**What goes where.** Everything is assembled in the front shell. It lies face down on the table, and you look into it from the back, as in the picture. So the side with the PTT button is on the **right** in the picture and on the table (even though from the front it's the left side). From here on, places are named "on the button side" and "on the other side".

In the picture, circles with a cross are self-tapping screws: 2 at the speaker shelf, 1 at the board clamp, 2 at the battery holder, 2 at the mic clamp plate. Empty circles in the corners are the posts for the 4 back-cover screws. The dashed lines show what is hidden under the shelf: the speaker and the LED ring cup, and at the top — the volume knob's board.

### Step 1. Flashing — before assembly

Flash and set up the board while it's still out of the case: later its USB-C socket will end up inside. How — in the [flashing guide](SETUP.md#1-flashing). After that, the radio is updated over the air (OTA), through the bridge, or with a file uploaded on its own page.

**Testing the microphone on the bench (optional).** First solder the pin header onto the microphone (step 2, item 1). Connect the flashed board to the microphone with wires 1–6 and plug the board into the computer with the cable. Open a serial monitor (for example, in Arduino IDE: speed 115200, line ending "New Line", otherwise the command won't run; more in [USB commands](SETUP.md#5-usb-commands)) and send the command `micraw`. The board will reply with a line `OK micraw кадров … L: … R: …` (кадров = frames). The numbers after `L:` should be noticeably different and change if you clap nearby. `L: 0…0` or two identical numbers means the microphone is silent: check the soldering of the pins (most often SCK) and the L/R → G wire.

### Step 2. Soldering on the bench

All of this is done before mounting in the case: afterwards you can no longer reach the button's screws or the power switch. Slide the heat-shrink (a ≈ 15 mm piece) onto the wire **before** soldering — you won't get it on afterwards. After soldering, slide the tube over the joint and heat it with a hot-air gun or the side of the soldering tip.

1. **Pin headers** on the microphone and the amplifier, if the seller didn't solder them. On the microphone the pins go on the side **without components** (that's where the sound hole is), on the amplifier — on the side **with components**. Snip off the pin tails on the other side. Solder every pin.
2. **Speaker:** two whole wires ≈ 17 cm from the speaker's solder tabs to the "+" and "−" pads of the amplifier (wires 13, 14).
3. **LED ring:** three wires — DI, 5V with the diode stripe towards the ring, GND (wires 15–17).
4. **Battery and divider:** the holder leads to B+ and B− of the charger module, and the battery voltage divider to the same pads (wires 27–30).
5. **Power switch:** module OUT+ — with a ≈ 20 cm wire to one terminal of the power switch; to the second terminal — the wire that will go into the 5 V connector; to OUT− — a ≈ 17 cm wire to the GND connector (wires 31–33).
6. **Button:** two wires under the screws (wires 18, 19). Bend the core into a hook clockwise — then the screw pulls it in as it tightens instead of pushing it out.
7. **The volume knob needs no soldering:** the housings of the female-female jumper wires slip straight onto its pins, and there is a pocket for them in the case wall. Don't shorten the pins. If the housings still don't fit, cut them off and solder the wires directly to the pins.

### Step 3. Parts into the front shell — in this order

The front shell lies face down on the table.

1. **White lens disc.** 3–4 drops of clear glue (not hot glue) on the chamfer of its seat, then press the disc in from the outside, flush with the face.
2. **LED ring, spacer, speaker.** From the inside, place the **LED ring** into the cup with the LEDs towards the disc, the pads with the wires facing down (towards the ESP board). On top of it — the **spacer**, with its cut-out in the same direction, towards the pads. Into its square seat goes the **speaker**, flange first, solder tabs to the side. Don't glue anything: the whole stack will later be clamped by the speaker shelf.
3. **Volume knob** — into the hole on top, closer to the middle. Bushing from the inside, pin header towards the other side, into the free corner, away from the power switch. Screw the nut on from the outside.
4. **Power switch** — into the hole on top on the button side, across the case: the lever moves towards the face and towards the back.
5. **Button** — into the hole in the side, tighten the nut from the inside.
6. **Charger module** — into the slot at the bottom on the button side: on its edge, USB-C socket down into the window in the bottom. Divider resistors towards the button wall: on that side the slot is open at the top. The wires from its pads point towards you.
7. **Microphone** — into the little ring at the bottom in the middle, components (the capsule) towards the face. The two columns of pins will sit left and right of the centre. First slip the housings of wires 1–6 onto the pins, then lay the **mic clamp plate** between the columns and drive in 2 self-tapping screws 3 × 10 (no longer than 10 mm, or they'll pierce the face).
8. **Amplifier** — into the seat at the bottom on the other side, pins towards you. Pin header up or down — whichever suits the wires. First tuck the board edge that's next to the case wall under the lip, then press the other edge (towards the microphone): it will slide down the ramp and snap under the catch, the wall there is springy. Don't press straight down on both edges.
9. **Battery holder**, still without the battery, — onto the two posts on the other side: 2 screws 3 × 12 from the inside, through its holes in the bottom (**no longer than 12 mm**). Don't lay wires over the holder: there is ≈ 2 mm to the back cover above it.
10. **ESP32-S3 board.** While the board is in your hands (labels facing you, USB at the bottom), slip on the connectors of wires 1–10, 15, 18, 20–27 — the pin numbers are visible now. Then turn the board module side towards the face of the radio and lay it into the seat on the button side **antenna down**: first tuck the two bottom corners under the lips, then lay the board on its support pads. The row with pins 3V3…8 and 5V will end up next to the wire channel, the row with pins 1, 2, 42, 41 — next to the button wall. Once the board is in place you can no longer count the pins: the labels are underneath and the rows have swapped sides. Put the **board clamp** with its hole over the post's pin and drive in 1 self-tapping screw 3 × 10 — it will hold the board down in the middle. You can take the board out at any time by undoing this screw.
11. **Speaker shelf.** Press the lever connectors into its seats levers up (towards you), with the wire-entry side towards the side walls of the case: the 5 V connector into the seat by the button wall (next to the power switch), the GND connector into the other one. Place the **speaker puck** on the speaker magnet flat side down, pin towards you. Put the shelf with its hole over the puck's pin, set it on the two posts at the sides and drive in 2 self-tapping screws 3 × 10 until the shelf bottoms out on the posts: the puck will clamp the speaker, and with it the LED ring and the white lens disc.

> **Antenna** — the part of the ESP32-S3 module without a metal shield; it sticks out past the edge of the board. Don't press wires or metal against it, and don't fold spare wire length next to it.

### Step 4. Wires

Connect the other ends according to the list, by number. Ends that go into lever connectors are folded in half. Where to route them:

- microphone and amplifier — short, to the row of board pins next to the channel;
- button wires — along the button wall; volume knob wires — over the board upwards and across the top to the volume knob, past the edge of the shelf on the other side;
- route the wires going into the lever connectors along the side walls, where the connectors have their entry holes: to the 5 V connector — along the button wall, to the GND connector — along the other wall. Under the shelf on each side there is a slot for a cable tie;
- OUT+ from the charger module to the power switch — along the button wall: above the board's connector housings, above the button and past the 5 V connector. OUT− to the GND connector — diagonally over the board and the channel;
- speaker wires — out from under the shelf (there is a gap above the magnet) into the channel and down the channel to the amplifier, around the housings on its pin header;
- tie the bundle in the channel at the cable-tie anchors with 2.5 mm cable ties, threading each tie under its anchor. Fold spare length next to an anchor, not next to the antenna (the bottom of the board).

### Step 5. Knob cap

Push the knob cap onto the shaft leaving a 1.5–2 mm gap above the end of the bushing, then press: there should be a click. That's the volume knob press, it mutes the sound.

### Step 6. Test before closing

**With a multimeter, battery not inserted.** In continuity mode, touch the probes to the second terminal of the power switch (the one that goes to the 5 V connector) and the OUT− pad of the charger module. A short beep followed by silence is normal: the capacitors are charging. A continuous beep means a short somewhere; first look for a 5 V wire in the GND connector.

**With a multimeter, battery inserted.** Insert the battery, plus as marked on the holder. The B+ and B− pads of the charger module should read 3.0–4.2 V, and the middle of the divider exactly half of that.

**Turn on the power switch** (if nothing lights up, flick it the other way). The LED ring will immediately flash **white**. Then:

- a radio that doesn't know any Wi-Fi yet will right away start slowly "breathing" **purple**: the RADIO-XXXX setup access point is open. That's as it should be; Wi-Fi is entered from a phone (see [Option 2. From a phone](SETUP.md#option-2-from-a-phone));
- a radio that already knows Wi-Fi will show a running **blue** light (searching for the network), and once connected to the bridge you will hear "tee-doo" and see short **green** flashes every 3 seconds.

While the back cover is open, take a minute to check what will be hidden later. No connection to the bridge is needed for this:

| What to do | What should happen | What it checks |
|---|---|---|
| Turn the volume knob | the LED ring shows the volume as a white bar, clicks in the speaker; clockwise — louder | volume knob, amplifier, speaker |
| Briefly press the knob | the bar turns purple — sound muted; press again — a click, the sound is back | the volume knob's push button |
| Press the PTT button with no connection to the bridge | a low beep and fast orange blinking ("no connection, can't talk") | PTT button |
| Hold the knob for 1–4 s and release | charge gauge: green (above 40 %), amber (16–40 %) or red (15 % and below). For the first 20 seconds after power-on — dim white: the charge is still being measured | battery voltage divider |

Once the radio is connected to the bridge, check the microphone too: press the PTT button — "beep-beep", the LED ring lights up red and "dances" in time with your voice. The other radio will hear you, and on the bridge status page this radio will be marked as talking.

**If something is wrong:**

| Symptom | What to check |
|---|---|
| The LED ring didn't light up at all within 10 seconds | power switch, wires in the 5 V connector, diode (stripe towards the ring), wire from pin 18 to DI, not to DO |
| The LED ring flashes the "wrong" colours | the diode in the ring's 5V wire, ring GND in the GND connector |
| No clicks or sounds | amplifier Vin and GND in the lever connectors, wires 7–10 on pins 7, 15, 16, 17, speaker wires on the amplifier's "+" and "−" |
| Volume changes the wrong way | tick «Регулятор крутится наоборот» (Volume knob turns the other way) on the radio settings page, or swap the CLK and DT wires |
| The volume knob doesn't respond | volume knob "+" on 3V3, its GND on the board's G, wires on pins 2, 42, 41 |
| The charge gauge is blue even though the radio is on battery | the radio doesn't see the divider: wire 27 on pin 8, resistors on B+ and B− |
| The bridge reports «в передаче одна тишина — проверьте микрофон» ("only silence in the transmission — check the microphone") | soldering of all the microphone pins (especially SCK), VDD on 3V3, L/R on G. If L/R is connected to 3.3 V, tick «Микрофон на правом канале» (Microphone on the right channel) on the radio settings page |
| The radio reboots by itself when shaken | wire ends in the lever connectors: are they folded in half, do they hold |
| The radio turns itself off when left idle for a long time | the charger module cuts off a load that's too small: check that «Экономия аккумулятора» (Battery saving) is off on the radio settings page |

Other symptoms and what to do about them are in [If something isn't working](TROUBLESHOOTING.md).

### Step 7. Close it

The back cover is just a cover; not a single wire goes to it. Lay it on top and check that no wire is resting on its rim. Drive in the four countersunk 3 × 12 screws — without force, it's plastic.

The radio is assembled. Next — Wi-Fi, the network key and the bridge: [Flashing and setup](SETUP.md) and [Your own bridge](BRIDGE.md).

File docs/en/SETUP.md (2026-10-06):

[Русский](../SETUP.md) · **English**

# Flashing and setup

From a bare board to a radio on the channel — and how to use it every day.

**Before you start**

- **The bridge is already running**, and you know its address and network key — see [Your own bridge](BRIDGE.md). The bridge
  is a small program on a computer or server through which the radios hear each other. Without a bridge the radio will
  power on, but it won't get on the channel.
- **Board** — ESP32-S3-DevKitC-1 or its clone YD-ESP32-S3, with 4 MB of flash or more (the firmware doesn't need PSRAM).
  Wiring — as in the [build guide](BUILD.md).
- **A USB-C cable that carries data.** A "charge-only" cable won't show the board to the computer.

You can flash and set up the board before you assemble the case: the microphone and speaker aren't needed to get on the
network.

**Contents**

1. [Flashing](#1-flashing)
2. [First-time setup](#2-first-time-setup)
3. [Everyday use](#3-everyday-use)
4. [Updates](#4-updates)
5. [USB commands](#5-usb-commands)

---

## 1. Flashing

The firmware is the program inside the board. You write it over the cable once; after that the radio updates itself
through the bridge ([section 4](#4-updates)).

### Which file to use

| File | What's inside | When you need it |
|---|---|---|
| [`firmware/dist/walkie-full-v9.bin`](../../firmware/dist/walkie-full-v9.bin) | the whole flash memory, 4 MB: bootloader, partition table and the program itself, version 9 | first flashing over the cable and "rescuing" a board that won't start. Written from address `0x0`. **Erases all radio settings** |
| [`firmware/dist/walkie.bin`](../../firmware/dist/walkie.bin) + [`walkie.json`](../../firmware/dist/walkie.json) | the program only (≈1.2 MB) and its version number | for the bridge, so the radios update themselves, and for uploading through the settings page |

### USB connectors and the serial port

The board has two USB-C connectors:

- **"USB"** — the ESP32-S3's own built-in USB. It's the most convenient one for both flashing and setup.
- **"COM"** (labelled "UART" on the original board) — goes through a separate USB-to-serial adapter chip. On some clones
  this connector **gets no power from a C-to-C cable**: the board is missing the resistors that tell the computer a
  device has been plugged in. If the board doesn't light up, switch to the "USB" connector or use a USB-A → USB-C cable.

The port is the name under which the computer sees the connected board:

| System | What the port looks like |
|---|---|
| macOS | `/dev/cu.usbmodem…`, `/dev/cu.wchusbserial…` or `/dev/cu.usbserial…` |
| Linux | `/dev/ttyACM0` or `/dev/ttyUSB0`. Add yourself to the `dialout` group once: `sudo usermod -aG dialout $USER`, then log out and back in |
| Windows | `COM3`, `COM5`… — "Device Manager → Ports (COM & LPT)". If the "COM" connector gives no port, install the driver for its adapter chip — CH343 from the WCH website (YD-ESP32-S3 clone) or CP210x from the Silicon Labs website (original DevKitC-1) — or connect to the "USB" connector |

Not sure which port is yours? Look at the list before and after plugging in the cable: the new one is the board.

In an assembled radio the board's connectors are inside the case — remove the back cover (4 screws). Before plugging
the cable into the board, turn off the power switch (the toggle on top): the radio will run on power from the
computer, and the battery won't drain for nothing.

### Option A. Prebuilt file with esptool

esptool is Espressif's official flashing tool; it runs on macOS, Linux and Windows. You need Python 3.

```sh
python3 -m pip install --upgrade esptool
```

macOS and Linux (substitute your own port):

```sh
esptool --chip esp32s3 --port /dev/cu.usbmodem1101 --baud 921600 --after watchdog-reset \
  write-flash 0x0 firmware/dist/walkie-full-v9.bin
```

Windows (PowerShell):

```powershell
python -m esptool --chip esp32s3 --port COM5 --baud 921600 --after watchdog-reset write-flash 0x0 firmware\dist\walkie-full-v9.bin
```

- `0x0` — write from the very beginning of the memory: the file contains everything at once, including the bootloader.
- `--after watchdog-reset` — after writing, restart the board in a way that makes sure it leaves download mode.
  A normal reset through the "USB" connector sometimes leaves it in the bootloader, and the radio stays silent.
- This is the esptool 5 syntax. If the command doesn't understand `write-flash` or `watchdog-reset`, you have an old
  version — update it with the command above.

**macOS, the short way:** [`tools/flash.sh`](../../tools/flash.sh) finds the port and the newest
`walkie-full-v*.bin` by itself and runs the same command (`tools/flash.sh /dev/cu.xxx` — specify the port manually).
The script takes esptool from the Arduino core, so
[`tools/build_firmware.sh`](../../tools/build_firmware.sh) must have run once (option B below).

### Option A2. In the browser, nothing to install

You need Chrome or Edge on a computer: only they can work with USB ports from a web page (Safari and Firefox can't).

1. Open Espressif's official web flasher: <https://espressif.github.io/esptool-js/>.
2. Baudrate `921600` → **Connect** → choose the board's port.
3. Flash Address `0x0`, file `walkie-full-v9.bin` → **Program**.
4. When writing finishes, press **RST** on the board (or unplug and replug the cable).

### Option B. Build the firmware yourself

You need this if you changed the code or want to build your bridge's address into the firmware.

**What you can change before building** — in [`firmware/walkie/config.h`](../../firmware/walkie/config.h):

- `FW_VERSION` — the version number, an integer. Give every new build for the bridge a **higher** number,
  otherwise the radios won't take it.
- `DEFAULT_SERVER` — your bridge's address, e.g. `"radio.example.com"`. Then freshly flashed radios know the bridge
  without any setup. An address entered later on the page or over USB takes priority over the built-in one; after the
  `factory` command the radio goes back to the built-in address. The network key is never built into the
  firmware — it's entered separately.
- Pin numbers — if you wired the board differently.

**macOS and Linux:**

1. Install arduino-cli: on macOS `brew install arduino-cli`, on Linux — following the
   [official instructions](https://arduino.github.io/arduino-cli/latest/installation/).
2. Run the build:

   ```sh
   tools/build_firmware.sh
   ```

   The first time, the script installs the esp32 core version 3.3.12 by itself (a few hundred megabytes). The firmware
   needs no third-party libraries. The result goes to `firmware/dist/`: `walkie-full-vN.bin`, `walkie.bin` and `walkie.json`.

The board settings the script builds with: "ESP32S3 Dev Module", Flash Size 4M, partition scheme
`min_spiffs` (two halves of 1.9 MB each — needed for over-the-air updates), PSRAM disabled, USB Mode `hwcdc`,
USB CDC On Boot enabled.

> The script replaces the ctags helper program with a dummy: on an Apple Silicon Mac without Rosetta, the one that
> ships with Arduino won't run. That's why in `walkie.ino` every function must be placed **before** the point where it's
> called — otherwise the build fails.

**Windows** (PowerShell, from the project folder):

```powershell
arduino-cli core install esp32:esp32@3.3.12 --additional-urls https://espressif.github.io/arduino-esp32/package_esp32_index.json
arduino-cli compile --fqbn "esp32:esp32:esp32s3:FlashSize=4M,PartitionScheme=min_spiffs,PSRAM=disabled,USBMode=hwcdc,CDCOnBoot=cdc" --output-dir firmware\build firmware\walkie
```

`firmware\build` will then contain `walkie.ino.merged.bin` (this is the full image, like `walkie-full`) and `walkie.ino.bin`
(this is `walkie.bin`). Create `walkie.json` for the bridge yourself: `{"version": 9}` — the number from `FW_VERSION`.

**Arduino IDE 2** works too. Core "esp32 by Espressif" 3.3.12, in the "Tools" menu:
board "ESP32S3 Dev Module", Flash Size "4MB (32Mb)", Partition Scheme "Minimal SPIFFS (1.9MB APP with OTA/190KB SPIFFS)",
PSRAM "Disabled", USB Mode "Hardware CDC and JTAG", USB CDC On Boot "Enabled".
Get the files through "Sketch → Export Compiled Binary".

### If flashing fails

- **The port doesn't appear** — the cable doesn't carry data, or the "COM" connector gets no power (see above). Try
  another cable and the "USB" connector.
- **`Failed to connect` / `No serial data received`** — put the board into download mode by hand: hold **BOOT**,
  press and release **RST**, release **BOOT**. Run the command again.
- **Errors in the middle of writing** — lower the speed: `--baud 115200`.
- **Written successfully, but the ring doesn't light up** — press **RST** or replug the cable.

---

## 2. First-time setup

The radio needs to know three things — Wi-Fi, the bridge address and the network key — and, for convenience, its own name.

| What | Where to get it |
|---|---|
| **Bridge address** | IP address or domain name of the server where the bridge runs: `203.0.113.10` or `radio.example.com`. The default port is 47000; for a different one, add it after a colon: `radio.example.com:47010`. If the bridge is on the same network as the radio, the field can be left empty ([below](#empty-bridge-address--searching-your-own-network)) |
| **Network key** | the shared password of all radios and bridges — the `key` line in the bridge settings. `python3 hub/walkie_hub.py --genkey` generates a new key. It must be at least 12 **Latin** letters and digits (the radio skips Cyrillic letters but the bridge counts them, so the keys won't match); hyphens, spaces and case don't matter: `abcd-efgh…` and `ABCDEFGH…` are the same key |
| **Wi-Fi** | network name and password. **2.4 GHz** only: the ESP32-S3 doesn't see 5 GHz networks. Networks with a sign-in page (as in cafés and hotels) and corporate networks with a login won't work |
| **Name** | how the radio appears on the bridge page: "Kitchen", "Garage". Without a name — «Рация XXXX» ("Radio XXXX"). Up to 31 bytes fit: about 15 Cyrillic letters or 31 Latin ones |

The key is stored in the radio's memory, not in the firmware. Every packet is signed with this key and speech is
encrypted: a radio with a different key won't get on the channel.

### Option 1. Over a USB cable (macOS, Linux)

[`tools/provision.py`](../../tools/provision.py) — needs only standard Python 3, nothing to install.

```sh
python3 tools/provision.py --name Kitchen --server 203.0.113.10 --key XXXX-XXXX-XXXX-XXXX
python3 tools/provision.py --wifi "MyNetwork|password" --wifi "SecondNetwork|password2"
python3 tools/provision.py --show
```

| Flag | What it does |
|---|---|
| `--name` | radio name |
| `--server` | bridge address `host[:port]`; `auto` — erase the address and search for the bridge on your own network |
| `--key` | network key |
| `--wifi "Network\|password"` | add a network; can be repeated, the radio remembers up to three networks |
| `--volume 0..20` | volume |
| `--amp i2s` / `--amp pdm` | amplifier type: `i2s` — MAX98357A (default), `pdm` — PAM8403 through a filter. The radio restarts, so the script does this last |
| `--show` | show the radio's status (same as running without flags) |
| `--reboot` | restart the radio at the end |
| `--port` | specify the port manually |

The script finds the port by itself only on macOS. On Linux, specify it: `--port /dev/ttyACM0`. For each step the script
prints ✓ or ✗; the key and passwords are replaced with `***` in the output.

The script doesn't work on Windows (it needs the termios module, which exists only on macOS and Linux) — type the same
commands in a serial terminal window, see [section 5](#5-usb-commands).

### Option 2. From a phone

A radio that doesn't know any Wi-Fi network opens its own **access point** — a Wi-Fi network `RADIO-XXXX`
with no password (XXXX — four characters of the radio's ID). Meanwhile the ring slowly "breathes" purple.

1. Turn on the radio and connect your phone to the `RADIO-XXXX` network.
2. The settings page opens by itself, like hotel Wi-Fi. If it doesn't, type `http://192.168.4.1` in the browser.
3. The **«Настройки»** (Settings) block: name («Имя рации»), bridge address («Адрес моста»), network key
   («Ключ сети») → **«Сохранить»** (Save).
   Do this before Wi-Fi: after Wi-Fi the radio restarts, and the phone disconnects from it.
4. The **«Wi-Fi»** block: **«Найти»** (Find) → tap your network → password → **«Подключиться к этой сети»**
   (Connect to this network). The radio remembers the network, restarts and connects.
5. A few seconds later you'll hear a rising "tee-doo" — the radio is connected to the bridge.

If you entered Wi-Fi first and left the key empty, after the restart the radio opens `RADIO-XXXX` again
(there is Wi-Fi, but no key): connect once more and finish step 3. You can also do it through your home network — see below.

The access point closes by itself once the radio has been connected to Wi-Fi for more than a minute, is connected to
the bridge, and nobody is connected to the access point.

### The settings page on your home network

The same page opens from any device on the same Wi-Fi network at `http://radio-xxxx.local`
(the same four characters, in lowercase). It usually opens from computers and iPhones; Android often doesn't understand
such addresses — then find `radio-xxxx` in your router's device list and type its numeric address
(or look it up with the `show` command over USB).

The **«Состояние»** (Status) block refreshes every 2 seconds: link status («на связи» (connected), «ищу мост»
(looking for the bridge), «не тот ключ сети» (wrong network key)…), battery, network and signal strength, the bridge
and the latency to it, how many radios are online, received and lost packets, «Чужие пакеты» (foreign packets — with
an invalid signature), «Работает» (running) — for how long and why the radio last started («включение питания»
(power-on), «сторож: зависание» (watchdog: hang), «просадка питания» (brownout)…), «Свист рядом с другой рацией»
(howl near another radio) and the last error.

| Field | What it does | Default |
|---|---|---|
| «Имя рации» (Radio name) | how it appears on the bridge page | «Рация XXXX» (Radio XXXX) |
| «Адрес моста» (Bridge address) | `host[:port]`; empty — search for the bridge on your own network | empty |
| «Ключ сети» (Network key) | the field is always shown empty; next to it it says «задан» (set) or «не задан» (not set). Leave it empty to keep the current key | — |
| «Громкость» (Volume) | 0–20, ≈ 2 dB per step | 14 |
| «Яркость подсветки» (LED brightness) | the ring, 0–100 | 60 |
| «Автоусиление микрофона» (Microphone automatic gain control) | the radio adjusts the sensitivity to your voice by itself (up to +36 dB) | on |
| «Усиление, если автоусиление выключено» (Gain if AGC is off) | 0–42 dB | 24 |
| «Сигнал в конце чужой передачи» (Tone at the end of someone else's transmission) | a short falling "tee-doo" when the other person releases the button | on |
| «Микрофон на правом канале» (Microphone on the right channel) | if the L/R pin of the INMP441 microphone is connected to 3.3 V rather than to GND. Check with the `micraw` command | off |
| «Регулятор крутится наоборот» (Volume knob turns the other way) | if turning clockwise lowers the volume | off |
| «Экономия аккумулятора» (Battery saving) | after 15 s of silence Wi-Fi dozes off; the first words of an incoming transmission arrive with a delay of up to ≈0.3 s (the buffer smooths it out), and the battery lasts longer | **off** |

> **Turn battery saving on with care.** At idle the radio then draws so little current that a charger module built
> like a power bank may decide the load has been disconnected and cut the power: the radio "turns itself off".
> Test your module: turn battery saving on and leave the radio running on its battery, untouched, for half an hour.

There's no amplifier type switch on the page — only over USB (`amp`, see [section 5](#5-usb-commands)).

> **The page has no password.** Anyone on the same Wi-Fi network (or connected to the open `RADIO-XXXX`) can
> change the settings and upload firmware. The page never shows the network key itself. Keep the radios on your own
> network, not a public one.

### Wi-Fi: up to three networks

- The radio remembers **up to three networks**, for example home, the country house and the workshop, and when connecting
  it picks whichever known network has the strongest signal. A fourth one pushes the first one out of the list. You can
  remove an extra one with the «убрать» (remove) button on the page.
- If the network disappears, the radio tries to connect every 15 seconds. After a minute without a network it also opens
  `RADIO-XXXX` so you can give it a new network. If the network has just dropped out for a while, don't touch
  anything: when the network comes back, the radio reconnects by itself.
- After 15 minutes without Wi-Fi, with nobody connected to the access point, the radio restarts by itself.

### Empty bridge address — searching your own network

If the address is empty (or `server auto` was set over USB), the radio broadcasts a greeting to all devices on its
network on UDP port 47000 and takes the first bridge that replies with the same key. This works only when the bridge
is on the same network, behind the same router. It won't work if the radio is somewhere else, on a guest network with
client isolation, or if the router doesn't pass broadcast packets — then enter the address.

If an address is set, the radio talks only to it. It looks up a domain name again every 10 minutes (and every 15 seconds
while there's no connection): if the server's IP changes, it's enough to fix one record at your domain registrar — the
radios will find the bridge by themselves.

### Reopening setup with the button

Hold down the PTT (push-to-talk) button, turn on the power switch and keep holding the button for about 1.5 seconds, until the ring
fills with purple. The radio opens `RADIO-XXXX` and at the same time connects to a known network. A low beep after
that is normal: the button was held while there was no connection yet. In this mode the access point stays up until
the radio is switched off — when you're done, turn the radio off and on again.

---

## 3. Everyday use

### First test with a single radio

You don't need a second radio for testing: you can run a "parrot" on a computer that sends everything you say back
to the channel.

```sh
python3 hub/sim_radio.py --hub 203.0.113.10 --key XXXX-XXXX-XXXX-XXXX echo
```

Press the button, say something, release it — a moment later the radio repeats your words. The "parrot" runs
for 30 minutes (`--minutes` changes this). Other tests with the same program — `status`, `tone`, `say`, `listen`:
`python3 hub/sim_radio.py --help`. The computer needs UDP access to the bridge, just like the radios.

### Talking

1. Press and hold the PTT button. Two white LEDs run around the ring — the radio is asking the bridge
   for the channel.
2. You'll hear a rising "beep-beep" — you can talk. Anything said before the tone isn't transmitted.
3. Speak in your normal voice. The ring is red and "dances" in time with your voice — you're being heard.
4. Release the button. The other radios hear you right away, while you're talking, not afterwards.

One person talks at a time. If the channel is busy, you'll hear "boo-boo-boo" (the busy tone) — wait for the other
transmission to end and press again. A single press lasts no longer than 90 seconds (protection against a stuck button;
the limit is set by the `tot_seconds` line in the bridge settings, but the radio won't transmit for more than 100 seconds
anyway): after that comes a low beep — release the button and press it again.

### Volume knob

| Action | What happens |
|---|---|
| Turn | volume, one step per click (0–20). For 1.5 s the ring shows the level, and you hear a click. Turning also unmutes the sound |
| Short press (under 1 s) | mute or unmute. While muted, a single purple LED is lit at idle; if someone talks meanwhile, the ring glows a soft light blue |
| Hold 1–4 s and release | for 2.5 s — the battery gauge: green — more than 40 %, amber — 16–40 %, red — 15 % or less. Dim white — the charge is still being measured, blue — USB power with no battery |
| Hold 10 s | settings reset ([below](#resetting-settings)). From the 5th second the ring flashes red: if you change your mind, release it and nothing happens |

If it turns "the wrong way", enable «Регулятор крутится наоборот» (Volume knob turns the other way) on the settings page.

### Sounds

| Sound | Meaning |
|---|---|
| rising "beep-beep" | you can talk |
| "boo-boo-boo" | the channel is busy |
| a single low beep | no connection, the bridge didn't respond to the press, or the button was held longer than 90 s |
| two falling tones | the connection to the bridge was lost |
| rising "tee-doo" | the radio is connected: after power-on or when the connection comes back |
| short falling "tee-doo" | someone else's transmission has ended (turned off with the «Сигнал в конце чужой передачи» setting) |
| click | the volume changed or the sound was unmuted |
| three descending notes | the battery is running low |

### LED ring

At idle — a short green flash every 3 seconds: all is well. What the other colours mean — see the
[Ring colours](TROUBLESHOOTING.md#ring-colours) table.

### Battery and charging

- **Charging** — with a cable into the USB-C socket at the bottom of the case (the charger module). The radio charges
  even with the power switch off: the switch only cuts power to the radio itself. While it's charging you can usually
  use it — this depends on the charger module. The percentage is overstated while charging: the voltage is higher under
  charge — the accurate value appears about a minute after you unplug the cable.
- **How much is left** — hold the knob for 1–4 s; on the settings page — the «Аккумулятор» (Battery) row (percent and
  volts); the bridge page shows the charge of all radios at once.
- For the first ≈20 seconds after power-on the charge shows «измеряется» (measuring): the voltage wanders while Wi-Fi is
  connecting. Readings taken during a conversation are ignored too — the voltage sags under load.
- **Running low:** if the charge stays at 15 % or less for 30 seconds, the radio plays three descending notes every
  5 minutes (every minute from 5 %; silent during a conversation), and at idle it flashes red instead of green.
  The bridge log gets «пора на зарядку» ("time to charge").

### Resetting settings

| How | What is erased | What stays |
|---|---|---|
| Hold the knob for 10 s | Wi-Fi networks, volume, brightness, microphone and tone settings, knob direction, battery saving | name, bridge address, network key, amplifier type |
| The `factory` command over USB | everything | nothing: the radio is like new |
| Flashing `walkie-full-…bin` over the cable | everything | nothing |

After a reset the radio restarts and opens `RADIO-XXXX` — set up Wi-Fi again ([section 2](#2-first-time-setup)).
The knob reset deliberately leaves the key and the bridge address alone: after it, anyone who knows the Wi-Fi
password can bring the radio back onto the channel.

---

## 4. Updates

### Automatically from the bridge

The bridge tells every radio the version number of the firmware sitting in its folder. If it's higher than the radio's
own number, the radio waits until the channel has been quiet for 20 seconds (nobody is talking or has just been
talking), and then:

1. downloads the file from the bridge over HTTP (port 47080, unless the bridge is set to a different one);
2. checks the size and the SHA-256 checksum — the radio received it in a packet signed with the network key, so without
   the key nobody can slip it a foreign file;
3. writes the firmware into the other half of the memory (not the one it's running from now) and restarts with it.

While the update is in progress, a blue bar grows around the ring — don't turn the radio off. Settings are kept.
If the download breaks off or the file doesn't match, the radio stays on the old firmware (it sits untouched in the
other half of the memory) and tries again in an hour or after a restart.

How to put firmware on the bridge — see [Your own bridge](BRIDGE.md). In short: build the firmware with a higher
`FW_VERSION` ([option B](#option-b-build-the-firmware-yourself)) and put into the bridge's firmware folder first
`walkie.json`, then `walkie.bin` — the bridge notices them within 10 seconds. The order matters: the bridge rereads the
folder only when `walkie.bin` changes ([details](BRIDGE.md#9-over-the-air-firmware-updates)). The build script itself
writes the same number into `walkie.json` as in `config.h`.

The radio's firmware version is shown on the settings page (the «Прошивка» (Firmware) block) and by the `show` command.

### Manually through the settings page

The **«Прошивка»** (Firmware) block → choose the `walkie.bin` file → **«Загрузить прошивку»** (Upload firmware).
The radio replies «Прошивка записана, перезапуск…» ("Firmware written, restarting…") and restarts; settings are kept.
The version number isn't checked here — any build of this firmware will be loaded.

Upload `walkie.bin` specifically, not `walkie-full-…bin`: the full image (4 MB) doesn't fit into half of the memory
(1.9 MB), and the radio replies «Ошибка записи прошивки» ("Firmware write error").

### Over the cable

If the radio won't start at all, write the full image again ([section 1](#1-flashing)). This erases the
settings.

---

## 5. USB commands

The radio accepts text commands over the cable through either of its two connectors. Speed — 115200 (for the "COM"
connector; for the "USB" connector the speed doesn't matter). One line — one command, ending with Enter. The radio also
writes its log there (in Russian): what's going on with Wi-Fi, the bridge, updates. If something is wrong, look here
first.

**How to connect:**

- Any system where esptool is installed (pyserial comes with it):

  ```sh
  python3 -m serial.tools.miniterm --echo /dev/cu.usbmodem1101 115200
  ```

  On Windows: `python -m serial.tools.miniterm --echo COM5 115200`. Exit with `Ctrl+]`.
- Arduino IDE: "Serial Monitor", speed 115200, line ending "New Line" (with "No Line Ending" commands
  aren't executed).
- arduino-cli: `arduino-cli monitor -p /dev/ttyACM0 -c baudrate=115200`.
- Just to view the status on macOS and Linux: `python3 tools/provision.py --show` (on Linux — with `--port /dev/ttyACM0`).

| Command | What it does |
|---|---|
| `help` | list of commands |
| `show` | everything about the radio: ID, name, firmware version, bridge, whether the key is set, Wi-Fi, latency, charge, volume, receive statistics |
| `name Kitchen` | radio name |
| `server 203.0.113.10`<br>`server radio.example.com:47010` | bridge address |
| `server auto` | erase the address: search for the bridge on your own network |
| `key XXXX-XXXX-XXXX-XXXX` | network key. Fewer than 12 Latin letters and digits — the reply is `ERR key` |
| `wifi MyNetwork\|password` | add a network (for a known one — change its password) and connect right away. For a network without a password — `wifi MyNetwork` |
| `wifi-clear` | forget all networks |
| `volume 14` | volume 0–20 |
| `agc on` / `agc off` | microphone automatic gain control (AGC) |
| `led 60` | ring brightness 0–100 |
| `amp i2s` / `amp pdm` | amplifier type: MAX98357A (default) or PAM8403 through a filter. The radio restarts |
| `testtx 5 1000` | transmit a 1000 Hz tone to the channel for 5 s, as if the button were pressed: tests transmission without the button and microphone. 1–20 s (default 3), 100–4000 Hz (default 1000) |
| `testmic 10` | transmit the live microphone to the channel for 10 s without the button: 1–80 s (default 10) |
| `micraw` | for 1 second shows the swing of the "raw" microphone samples on the left (L) and right (R) channels |
| `reboot` | restart |
| `factory` | full reset: erases everything, including the key and the bridge address ([reset](#resetting-settings)) |

Every command except `help` and `show` gets a reply line `OK …` or `ERR …`; an unknown command
(or `name` without a name) gets `ERR неизвестная команда` ("unknown command").

**How to read `show`.** The «связь: N» (link: N) line is a number: `0` no Wi-Fi, `1` no key, `2` looking for the bridge,
`3` wrong network key, `4` connected. «мост:» (bridge:) — the address the radio is working with right now;
«адрес в настройках» (address in settings) — what's entered (empty — searching your own network). «чужих пакетов»
(foreign packets) — packets with an invalid signature: if this number grows, the radio is getting replies from a bridge
or device with a different key.

**How to read `micraw`.** While the command is running, talk into the microphone or tap on it. The channel the
microphone is connected to shows a wide swing of numbers; the other one shows about zero or the same number over and
over. Signal on R — enable «Микрофон на правом канале» (Microphone on the right channel) or move the microphone's L/R
pin to GND.

`testtx` and `testmic` work only when the radio is connected to the bridge; without a connection you'll get a low beep,
just like with a normal press. You can hear the tone on a second radio or record the channel on a computer:
`python3 hub/sim_radio.py --hub 203.0.113.10 --key XXXX-XXXX-XXXX-XXXX listen --seconds 30 --out efir.wav`.

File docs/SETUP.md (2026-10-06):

**Русский** · [English](en/SETUP.md)

# Прошивка и настройка

От голой платы до рации в эфире — и как ею пользоваться каждый день.

**Перед началом**

- **Мост уже работает**, и вы знаете его адрес и ключ сети — см. [Свой мост](BRIDGE.md). Мост — небольшая программа
  на компьютере или сервере, через которую рации слышат друг друга. Без моста рация включится, но в эфир не выйдет.
- **Плата** — ESP32-S3-DevKitC-1 или её клон YD-ESP32-S3, флеш-память от 4 МБ (PSRAM прошивке не нужна).
  Провода — как в [сборке](BUILD.md).
- **Кабель USB-C с передачей данных.** Кабель «только для зарядки» плату компьютеру не покажет.

Прошить и настроить плату можно ещё до сборки корпуса: чтобы выйти в сеть, микрофон и динамик не нужны.

**Содержание**

1. [Прошивка](#1-прошивка)
2. [Первая настройка](#2-первая-настройка)
3. [Пользование](#3-пользование)
4. [Обновления](#4-обновления)
5. [Команды по USB](#5-команды-по-usb)

---

## 1. Прошивка

Прошивка — программа внутри платы. По кабелю её записывают один раз, дальше рация обновляется сама
через мост ([раздел 4](#4-обновления)).

### Какой файл брать

| Файл | Что внутри | Когда нужен |
|---|---|---|
| [`firmware/dist/walkie-full-v9.bin`](../firmware/dist/walkie-full-v9.bin) | вся флеш-память, 4 МБ: загрузчик, таблица разделов и сама программа версии 9 | первая прошивка по кабелю и «спасение» платы, которая не запускается. Пишется с адреса `0x0`. **Стирает все настройки рации** |
| [`firmware/dist/walkie.bin`](../firmware/dist/walkie.bin) + [`walkie.json`](../firmware/dist/walkie.json) | только программа (≈1,2 МБ) и номер её версии | для моста, чтобы рации обновились сами, и для загрузки через страницу настроек |

### Гнёзда USB и порт

У платы два гнезда USB-C:

- **«USB»** — встроенный USB самого ESP32-S3. Им удобнее всего и прошивать, и настраивать.
- **«COM»** (на оригинальной плате подписано «UART») — через отдельную микросхему-переходник. На некоторых клонах
  через это гнездо плата **не получает питания от кабеля C–C**: на плате не хватает резисторов, по которым
  компьютер понимает, что к нему подключили устройство. Плата не загорается — переходите на гнездо «USB»
  или возьмите кабель USB-A → USB-C.

Порт — имя, под которым компьютер видит подключённую плату:

| Система | Как выглядит порт |
|---|---|
| macOS | `/dev/cu.usbmodem…`, `/dev/cu.wchusbserial…` или `/dev/cu.usbserial…` |
| Linux | `/dev/ttyACM0` или `/dev/ttyUSB0`. Один раз добавьте себя в группу `dialout`: `sudo usermod -aG dialout $USER` и перезайдите в систему |
| Windows | `COM3`, `COM5`… — «Диспетчер устройств → Порты (COM и LPT)». Если гнездо «COM» не даёт порта, поставьте драйвер его микросхемы-переходника — CH343 с сайта WCH (клон YD-ESP32-S3) или CP210x с сайта Silicon Labs (оригинальная DevKitC-1), — или подключитесь к гнезду «USB» |

Не знаете, какой порт ваш, — посмотрите список до и после подключения кабеля: новый и есть плата.

В собранной рации гнёзда платы внутри корпуса — снимите заднюю крышку (4 шурупа). Перед подключением кабеля
к плате выключите тумблер (выключатель питания сверху): рация будет питаться от компьютера, а аккумулятор
не будет зря разряжаться.

### Вариант А. Готовый файл через esptool

esptool — официальная программа Espressif для записи прошивки, работает на macOS, Linux и Windows. Нужен Python 3.

```sh
python3 -m pip install --upgrade esptool
```

macOS и Linux (порт подставьте свой):

```sh
esptool --chip esp32s3 --port /dev/cu.usbmodem1101 --baud 921600 --after watchdog-reset \
  write-flash 0x0 firmware/dist/walkie-full-v9.bin
```

Windows (PowerShell):

```powershell
python -m esptool --chip esp32s3 --port COM5 --baud 921600 --after watchdog-reset write-flash 0x0 firmware\dist\walkie-full-v9.bin
```

- `0x0` — писать с самого начала памяти: в файле всё сразу, включая загрузчик.
- `--after watchdog-reset` — после записи перезапустить плату так, чтобы она точно вышла из режима загрузки.
  Обычный сброс через гнездо «USB» иногда оставляет её в загрузчике, и рация молчит.
- Это написание для esptool 5. Если команда не понимает `write-flash` или `watchdog-reset`, у вас старая
  версия — обновите её командой выше.

**macOS, коротко:** [`tools/flash.sh`](../tools/flash.sh) сам находит порт и самый свежий
`walkie-full-v*.bin` и запускает ту же команду (`tools/flash.sh /dev/cu.xxx` — указать порт вручную).
Скрипт берёт esptool из ядра Arduino, поэтому один раз должен отработать
[`tools/build_firmware.sh`](../tools/build_firmware.sh) (вариант Б ниже).

### Вариант А2. В браузере, без установки программ

Нужен Chrome или Edge на компьютере: только они умеют работать с USB-портами из страницы (Safari и Firefox — нет).

1. Откройте официальный веб-прошивальщик Espressif: <https://espressif.github.io/esptool-js/>.
2. Baudrate `921600` → **Connect** → выберите порт платы.
3. Flash Address `0x0`, файл `walkie-full-v9.bin` → **Program**.
4. Когда запись закончится, нажмите на плате **RST** (или выньте и вставьте кабель).

### Вариант Б. Собрать прошивку самому

Нужно, если вы поменяли код или хотите вшить адрес своего моста.

**Что можно поменять перед сборкой** — в [`firmware/walkie/config.h`](../firmware/walkie/config.h):

- `FW_VERSION` — номер версии, целое число. Каждую новую сборку для моста делайте с номером **больше**,
  иначе рации её не возьмут.
- `DEFAULT_SERVER` — адрес вашего моста, например `"radio.example.com"`. Тогда свежепрошитые рации знают мост
  без настройки. Адрес, введённый потом на странице или по USB, важнее вшитого; после команды `factory`
  рация возвращается к вшитому адресу. Ключ сети в прошивку
  не вшивается никогда — его вводят отдельно.
- Номера выводов — если вы развели плату по-другому.

**macOS и Linux:**

1. Поставьте arduino-cli: на macOS `brew install arduino-cli`, на Linux — по
   [официальной инструкции](https://arduino.github.io/arduino-cli/latest/installation/).
2. Запустите сборку:

   ```sh
   tools/build_firmware.sh
   ```

   В первый раз скрипт сам поставит ядро esp32 версии 3.3.12 (несколько сотен мегабайт). Сторонних библиотек
   прошивке не нужно. Результат — в `firmware/dist/`: `walkie-full-vN.bin`, `walkie.bin` и `walkie.json`.

Настройки платы, с которыми собирает скрипт: «ESP32S3 Dev Module», Flash Size 4M, разметка памяти
`min_spiffs` (две половины по 1,9 МБ — нужны для обновления по воздуху), PSRAM выключена, USB Mode `hwcdc`,
USB CDC On Boot включён.

> Скрипт подменяет служебную программу ctags пустышкой: на Mac с Apple Silicon без Rosetta та, что идёт с Arduino,
> не запускается. Поэтому в `walkie.ino` каждая функция должна стоять **до** того места, где её вызывают, —
> иначе сборка не пройдёт.

**Windows** (PowerShell, из папки проекта):

```powershell
arduino-cli core install esp32:esp32@3.3.12 --additional-urls https://espressif.github.io/arduino-esp32/package_esp32_index.json
arduino-cli compile --fqbn "esp32:esp32:esp32s3:FlashSize=4M,PartitionScheme=min_spiffs,PSRAM=disabled,USBMode=hwcdc,CDCOnBoot=cdc" --output-dir firmware\build firmware\walkie
```

В `firmware\build` появятся `walkie.ino.merged.bin` (это и есть полный образ, как `walkie-full`) и `walkie.ino.bin`
(это `walkie.bin`). `walkie.json` для моста создайте сами: `{"version": 9}` — число из `FW_VERSION`.

**Arduino IDE 2** тоже подойдёт. Ядро «esp32 by Espressif» 3.3.12, в меню «Инструменты»:
плата «ESP32S3 Dev Module», Flash Size «4MB (32Mb)», Partition Scheme «Minimal SPIFFS (1.9MB APP with OTA/190KB SPIFFS)»,
PSRAM «Disabled», USB Mode «Hardware CDC and JTAG», USB CDC On Boot «Enabled».
Файлы — через «Скетч → Экспорт скомпилированного бинарного файла».

### Если не прошивается

- **Порт не появляется** — кабель без передачи данных, или гнездо «COM» без питания (см. выше). Попробуйте
  другой кабель и гнездо «USB».
- **`Failed to connect` / `No serial data received`** — переведите плату в режим загрузки руками: зажмите **BOOT**,
  нажмите и отпустите **RST**, отпустите **BOOT**. Повторите команду.
- **Ошибки посреди записи** — уменьшите скорость: `--baud 115200`.
- **Записалось, но кольцо не горит** — нажмите **RST** или переподключите кабель.

---

## 2. Первая настройка

Рации нужно знать три вещи — Wi-Fi, адрес моста и ключ сети — и, для удобства, своё имя.

| Что | Где взять |
|---|---|
| **Адрес моста** | IP или доменное имя сервера, где работает мост: `203.0.113.10` или `radio.example.com`. Порт по умолчанию 47000; другой — через двоеточие: `radio.example.com:47010`. Если мост в той же сети, что и рация, поле можно оставить пустым ([ниже](#пустой-адрес-моста--поиск-в-своей-сети)) |
| **Ключ сети** | общий пароль всех раций и мостов — строка `key` в настройках моста. Новый ключ выдаёт `python3 hub/walkie_hub.py --genkey`. Нужно не меньше 12 **латинских** букв и цифр (русские буквы рация пропускает, а мост учитывает — ключи не сойдутся); дефисы, пробелы и регистр не важны: `abcd-efgh…` и `ABCDEFGH…` — один и тот же ключ |
| **Wi-Fi** | имя сети и пароль. Только **2,4 ГГц**: сети 5 ГГц ESP32-S3 не видит. Не подойдут сети со входом через страницу (как в кафе и гостиницах) и корпоративные с логином |
| **Имя** | как рацию будет видно на странице моста: «Кухня», «Гараж». Без имени — «Рация XXXX». Влезает 31 байт: около 15 русских букв или 31 латинская |

Ключ хранится в памяти рации, а не в прошивке. Каждый пакет подписан этим ключом, речь зашифрована: рация
с другим ключом в эфир не попадёт.

### Способ 1. По USB-кабелю (macOS, Linux)

[`tools/provision.py`](../tools/provision.py) — только стандартный Python 3, ставить ничего не нужно.

```sh
python3 tools/provision.py --name Кухня --server 203.0.113.10 --key XXXX-XXXX-XXXX-XXXX
python3 tools/provision.py --wifi "ИмяСети|пароль" --wifi "ВтораяСеть|пароль2"
python3 tools/provision.py --show
```

| Ключ | Что делает |
|---|---|
| `--name` | имя рации |
| `--server` | адрес моста `хост[:порт]`; `auto` — стереть адрес и искать мост в своей сети |
| `--key` | ключ сети |
| `--wifi "Сеть\|пароль"` | добавить сеть; можно повторить, рация помнит до трёх сетей |
| `--volume 0..20` | громкость |
| `--amp i2s` / `--amp pdm` | тип усилителя: `i2s` — MAX98357A (по умолчанию), `pdm` — PAM8403 через фильтр. Рация перезапустится, поэтому скрипт делает это последним |
| `--show` | показать состояние рации (то же, что запуск без ключей) |
| `--reboot` | перезапустить рацию в конце |
| `--port` | указать порт вручную |

Порт скрипт находит сам только на macOS. На Linux укажите его: `--port /dev/ttyACM0`. На каждый шаг скрипт
печатает ✓ или ✗; ключ и пароли в выводе заменены на `***`.

На Windows скрипт не работает (ему нужен модуль termios, который есть только в macOS и Linux) — введите те же
команды в окне порта, см. [раздел 5](#5-команды-по-usb).

### Способ 2. С телефона

Рация, которая не знает ни одной Wi-Fi-сети, открывает свою **точку доступа** — Wi-Fi-сеть `RADIO-XXXX`
без пароля (XXXX — четыре знака номера рации). Кольцо при этом медленно «дышит» фиолетовым.

1. Включите рацию и подключите телефон к сети `RADIO-XXXX`.
2. Страница настройки откроется сама, как в гостиничном Wi-Fi. Не открылась — наберите в браузере
   `http://192.168.4.1`.
3. Блок **«Настройки»**: имя, адрес моста, ключ сети → **«Сохранить»**.
   Сделайте это до Wi-Fi: после Wi-Fi рация перезапустится, и телефон от неё отключится.
4. Блок **«Wi-Fi»**: **«Найти»** → нажмите на свою сеть → пароль → **«Подключиться к этой сети»**.
   Рация запомнит сеть, перезапустится и подключится.
5. Через несколько секунд прозвучит «ти-ду» вверх — рация на связи с мостом.

Если сначала ввели Wi-Fi, а ключ остался пустым, после перезапуска рация снова откроет `RADIO-XXXX`
(Wi-Fi есть, ключа нет): подключитесь ещё раз и закончите шаг 3. Можно и через домашнюю сеть — см. ниже.

Точка доступа закрывается сама, когда рация больше минуты подключена к Wi-Fi, на связи с мостом и к точке
никто не подключён.

### Страница настроек в домашней сети

Та же страница открывается с любого устройства в той же Wi-Fi-сети по адресу `http://radio-xxxx.local`
(те же четыре знака, маленькими буквами). С компьютеров и iPhone обычно открывается; Android такие адреса
часто не понимает — тогда найдите `radio-xxxx` в списке устройств роутера и наберите его адрес цифрами
(или посмотрите его командой `show` по USB).

Блок **«Состояние»** обновляется каждые 2 секунды: связь («на связи», «ищу мост», «не тот ключ сети»…), заряд,
сеть и сила сигнала, мост и задержка до него, сколько раций в сети, принятые и потерянные пакеты, «Чужие
пакеты» (с неверной подписью), «Работает» — сколько времени и почему рация запустилась в последний раз
(включение питания, сторож, просадка питания…), «Свист рядом с другой рацией» и последняя ошибка.

| Поле | Что делает | По умолчанию |
|---|---|---|
| Имя рации | так её видно на странице моста | «Рация XXXX» |
| Адрес моста | `хост[:порт]`; пусто — искать мост в своей сети | пусто |
| Ключ сети | поле всегда показывается пустым; рядом написано «задан» или «не задан». Оставьте пустым, чтобы не менять | — |
| Громкость | 0–20, шаг ≈ 2 дБ | 14 |
| Яркость подсветки | кольцо, 0–100 | 60 |
| Автоусиление микрофона | рация сама подстраивает чувствительность под голос (до +36 дБ) | вкл. |
| Усиление, если автоусиление выключено | 0–42 дБ | 24 |
| Сигнал в конце чужой передачи | короткое «ти-ду» вниз, когда собеседник отпустил кнопку | вкл. |
| Микрофон на правом канале | если вывод L/R микрофона INMP441 подключён к 3,3 В, а не к GND. Проверить — командой `micraw` | выкл. |
| Регулятор крутится наоборот | если по часовой стрелке громкость уменьшается | выкл. |
| Экономия аккумулятора | после 15 с тишины Wi-Fi дремлет; первые слова входящей передачи приходят с задержкой до ≈0,3 с (буфер её сглаживает), аккумулятор живёт дольше | **выкл.** |

> **Экономию включайте с осторожностью.** В простое рация тогда берёт так мало тока, что модуль заряда,
> устроенный как пауэрбанк, может решить, что нагрузку отключили, и выключить питание: рация «выключится сама».
> Проверьте свой модуль: включите экономию и оставьте рацию на аккумуляторе в покое на полчаса.

Переключателя типа усилителя на странице нет — только по USB (`amp`, см. [раздел 5](#5-команды-по-usb)).

> **У страницы нет пароля.** Любой, кто в той же Wi-Fi-сети (или подключился к открытой `RADIO-XXXX`), может
> поменять настройки и загрузить прошивку. Сам ключ сети страница не показывает никогда. Держите рации в своей
> сети, а не в общественной.

### Wi-Fi: до трёх сетей

- Рация помнит **до трёх сетей**, например дом, дачу и мастерскую, и при подключении выбирает ту знакомую, что ловит
  лучше. Четвёртая вытесняет первую в списке. Лишнюю можно убрать кнопкой «убрать» на странице.
- Сеть пропала — рация пробует подключиться каждые 15 секунд. Через минуту без сети она дополнительно открывает
  `RADIO-XXXX`, чтобы можно было дать ей новую сеть. Если сеть просто временно пропала — ничего не трогайте:
  вернётся сеть — рация подключится сама.
- 15 минут без Wi-Fi, и к точке никто не подключён, — рация перезапускается сама.

### Пустой адрес моста — поиск в своей сети

Если адрес пуст (или по USB задано `server auto`), рация рассылает приветствие всем устройствам своей сети
на UDP-порт 47000 и берёт первый мост, который ответил с тем же ключом. Это работает, только когда мост
стоит в той же сети, за тем же роутером. Не сработает, если рация в другом месте, в гостевой сети с изоляцией
устройств или если роутер не пропускает широковещательные пакеты — тогда впишите адрес.

Если адрес задан, рация говорит только с ним. Доменное имя она переспрашивает раз в 10 минут (и каждые 15 секунд,
пока связи нет): сменился IP сервера — достаточно поправить одну запись у регистратора домена, рации найдут
мост сами.

### Снова открыть настройку кнопкой

Зажмите кнопку «говорить», включите тумблер и держите кнопку около 1,5 секунды, пока кольцо не нальётся
фиолетовым. Рация откроет `RADIO-XXXX` и одновременно подключится к знакомой сети. Низкий гудок после этого —
нормально: кнопку держали, пока связи ещё не было. В этом режиме точка доступа работает до выключения —
закончили, выключите и включите рацию.

---

## 3. Пользование

### Первая проверка одной рацией

Вторая рация для проверки не обязательна: на компьютере можно запустить «попугая», который возвращает в эфир
всё сказанное.

```sh
python3 hub/sim_radio.py --hub 203.0.113.10 --key XXXX-XXXX-XXXX-XXXX echo
```

Нажмите кнопку, скажите что-нибудь, отпустите — через мгновение рация повторит ваши слова. «Попугай» работает
30 минут (`--minutes` меняет срок). Другие проверки той же программой — `status`, `tone`, `say`, `listen`:
`python3 hub/sim_radio.py --help`. Компьютеру нужен доступ к мосту по UDP, как и рациям.

### Говорить

1. Нажмите и держите кнопку «говорить». По кольцу бегут два белых огонька — рация просит у моста эфир.
2. Прозвучит «пи-пи» вверх — можно говорить. Сказанное до сигнала не передаётся.
3. Говорите обычным голосом. Кольцо красное и «пляшет» в такт голосу — вас слышно.
4. Отпустите кнопку. Остальные рации слышат вас сразу, пока вы говорите, а не после.

Говорит один человек за раз. Если эфир занят, прозвучит «бу-бу-бу» — дождитесь конца чужой передачи и нажмите
снова. Одно нажатие — не дольше 90 секунд (защита от залипшей кнопки; срок задаёт строка `tot_seconds`
в настройках моста, но больше 100 секунд рация всё равно не передаёт): потом низкий гудок — отпустите и нажмите заново.

### Регулятор

| Действие | Что происходит |
|---|---|
| Повернуть | громкость, по одному шагу на щелчок (0–20). На 1,5 с кольцо показывает уровень, слышен щелчок. Поворот заодно включает выключенный звук |
| Коротко нажать (меньше 1 с) | выключить или включить звук. Пока звук выключен, в простое горит один фиолетовый огонёк; если в это время кто-то говорит, кольцо мягко светится голубым |
| Подержать 1–4 с и отпустить | на 2,5 с — шкала заряда: зелёная — больше 40 %, янтарная — 16–40 %, красная — 15 % и меньше. Тусклое белое — заряд ещё измеряется, синее — питание от USB без аккумулятора |
| Подержать 10 с | сброс настроек ([ниже](#сброс-настроек)). С 5-й секунды кольцо мигает красным: передумали — отпустите, ничего не случится |

Крутится «не в ту сторону» — включите «Регулятор крутится наоборот» на странице настроек.

### Звуки

| Звук | Значит |
|---|---|
| «пи-пи» вверх | можно говорить |
| «бу-бу-бу» | эфир занят |
| один низкий гудок | связи нет, мост не ответил на нажатие или кнопку держали дольше 90 с |
| два тона вниз | пропала связь с мостом |
| «ти-ду» вверх | рация вышла на связь: после включения или когда связь вернулась |
| короткое «ти-ду» вниз | чужая передача закончилась (отключается настройкой «Сигнал в конце чужой передачи») |
| щелчок | громкость изменилась или звук включён |
| три нисходящие ноты | садится аккумулятор |

### Кольцо

В простое — короткая зелёная вспышка раз в 3 секунды: всё в порядке. Что значат остальные цвета —
в таблице [Цвета кольца](TROUBLESHOOTING.md#цвета-кольца).

### Аккумулятор и зарядка

- **Зарядка** — кабелем в гнездо USB-C внизу корпуса (модуль заряда). Рация заряжается и при выключенном тумблере:
  тумблер отключает только питание рации. Пока заряжается, ею обычно можно пользоваться — это зависит от модуля
  заряда. Проценты во время зарядки завышены: напряжение под зарядом выше — точное значение появится примерно
  через минуту после отключения кабеля.
- **Сколько осталось** — подержать регулятор 1–4 с; на странице настроек — строка «Аккумулятор» (проценты и вольты);
  на странице моста видно заряд всех раций сразу.
- Первые ≈20 секунд после включения заряд «измеряется»: пока Wi-Fi подключается, напряжение гуляет. Во время
  разговора замеры тоже не учитываются — под нагрузкой напряжение проседает.
- **Садится:** если заряд 15 % и меньше держится 30 секунд, рация раз в 5 минут играет три нисходящие ноты
  (с 5 % — раз в минуту; во время разговора молчит), а в простое вспыхивает красным вместо зелёного.
  В журнал моста пишется «пора на зарядку».

### Сброс настроек

| Как | Что стирается | Что остаётся |
|---|---|---|
| Регулятор держать 10 с | Wi-Fi-сети, громкость, яркость, настройки микрофона и сигналов, направление регулятора, экономия | имя, адрес моста, ключ сети, тип усилителя |
| Команда `factory` по USB | всё | ничего: рация как новая |
| Прошивка `walkie-full-…bin` по кабелю | всё | ничего |

После сброса рация перезапускается и открывает `RADIO-XXXX` — настройте Wi-Fi заново ([раздел 2](#2-первая-настройка)).
Сброс регулятором не трогает ключ и адрес моста специально: после него рацию вернёт в эфир любой, кто знает пароль
от Wi-Fi.

---

## 4. Обновления

### Сама с моста

Мост сообщает каждой рации номер прошивки, которая лежит у него в папке. Если он больше номера рации,
рация ждёт, пока в эфире 20 секунд тихо (никто не говорит и не говорил), и тогда:

1. скачивает файл с моста по HTTP (порт 47080, если в мосте не задан другой);
2. сверяет размер и контрольную сумму SHA-256 — её рация получила в пакете, подписанном ключом сети, поэтому
   без ключа чужой файл ей не подсунуть;
3. записывает прошивку в другую половину памяти (не ту, с которой работает сейчас) и перезапускается уже с ней.

Пока идёт обновление, по кольцу растёт синяя полоса — не выключайте рацию. Настройки сохраняются.
Если загрузка оборвалась или файл не сошёлся, рация остаётся на старой прошивке (она лежит в другой половине
памяти и не тронута) и пробует снова через час или после перезапуска.

Как выложить прошивку на мост — в [Свой мост](BRIDGE.md). Коротко: соберите прошивку с бо́льшим `FW_VERSION`
([вариант Б](#вариант-б-собрать-прошивку-самому)) и положите в папку прошивок моста сначала `walkie.json`, потом
`walkie.bin` — мост заметит их в течение 10 секунд. Порядок важен: мост перечитывает папку, только когда меняется
`walkie.bin` ([подробнее](BRIDGE.md#9-обновление-прошивки-по-воздуху)). Скрипт сборки сам пишет в `walkie.json`
тот же номер, что в `config.h`.

Версию прошивки рации видно на странице настроек (блок «Прошивка») и в команде `show`.

### Вручную через страницу настроек

Блок **«Прошивка»** → выберите файл `walkie.bin` → **«Загрузить прошивку»**. Рация ответит «Прошивка записана,
перезапуск…» и перезапустится; настройки сохранятся. Номер версии здесь не проверяется — загрузится любая сборка
этой прошивки.

Загружайте именно `walkie.bin`, а не `walkie-full-…bin`: полный образ (4 МБ) не помещается в половину памяти
(1,9 МБ), и рация ответит «Ошибка записи прошивки».

### По кабелю

Если рация не запускается совсем, запишите полный образ заново ([раздел 1](#1-прошивка)). Настройки при этом
сотрутся.

---

## 5. Команды по USB

Рация принимает текстовые команды по кабелю через любое из двух гнёзд. Скорость — 115200 (для гнезда «COM»;
гнезду «USB» скорость не важна). Одна строка — одна команда, в конце Enter. Туда же рация пишет свой журнал:
что с Wi-Fi, мостом, обновлениями. Если что-то не так, первым делом смотрите сюда.

**Чем подключиться:**

- Любая система, где стоит esptool (с ним ставится и pyserial):

  ```sh
  python3 -m serial.tools.miniterm --echo /dev/cu.usbmodem1101 115200
  ```

  На Windows: `python -m serial.tools.miniterm --echo COM5 115200`. Выход — `Ctrl+]`.
- Arduino IDE: «Монитор порта», скорость 115200, конец строки — «Новая строка» (с «Нет конца строки» команды
  не выполняются).
- arduino-cli: `arduino-cli monitor -p /dev/ttyACM0 -c baudrate=115200`.
- Только посмотреть состояние на macOS и Linux: `python3 tools/provision.py --show` (на Linux — с `--port /dev/ttyACM0`).

| Команда | Что делает |
|---|---|
| `help` | список команд |
| `show` | всё о рации: номер, имя, версия прошивки, мост, ключ задан или нет, Wi-Fi, задержка, заряд, громкость, статистика приёма |
| `name Кухня` | имя рации |
| `server 203.0.113.10`<br>`server radio.example.com:47010` | адрес моста |
| `server auto` | стереть адрес: искать мост в своей сети |
| `key XXXX-XXXX-XXXX-XXXX` | ключ сети. Меньше 12 латинских букв и цифр — ответ `ERR key` |
| `wifi ИмяСети\|пароль` | добавить сеть (у знакомой — сменить пароль) и сразу подключиться. Сеть без пароля — `wifi ИмяСети` |
| `wifi-clear` | забыть все сети |
| `volume 14` | громкость 0–20 |
| `agc on` / `agc off` | автоусиление микрофона |
| `led 60` | яркость кольца 0–100 |
| `amp i2s` / `amp pdm` | тип усилителя: MAX98357A (по умолчанию) или PAM8403 через фильтр. Рация перезапустится |
| `testtx 5 1000` | 5 с передавать в эфир тон 1000 Гц, как будто нажата кнопка: проверка передачи без кнопки и микрофона. 1–20 с (по умолчанию 3), 100–4000 Гц (по умолчанию 1000) |
| `testmic 10` | 10 с передавать в эфир живой микрофон без кнопки: 1–80 с (по умолчанию 10) |
| `micraw` | за 1 секунду показывает размах «сырых» отсчётов микрофона на левом (L) и правом (R) каналах |
| `reboot` | перезапуск |
| `factory` | полный сброс: стирает всё, включая ключ и адрес моста ([сброс](#сброс-настроек)) |

На каждую команду, кроме `help` и `show`, рация отвечает строкой `OK …` или `ERR …`; неизвестная команда
(или `name` без имени) — `ERR неизвестная команда`.

**Как читать `show`.** Строка «связь: N» — число: `0` нет Wi-Fi, `1` нет ключа, `2` ищет мост, `3` не тот ключ
сети, `4` на связи. «мост:» — адрес, с которым рация работает сейчас; «адрес в настройках» — что вписано
(пусто — поиск в своей сети). «чужих пакетов» — пакеты с неверной подписью: растёт — рации отвечает мост или устройство с другим ключом.

**Как читать `micraw`.** Пока команда работает, говорите в микрофон или постучите по нему. Канал, к которому
подключён микрофон, покажет широкий размах чисел, другой — около нуля или одно и то же число. Сигнал на R —
включите «Микрофон на правом канале» или пересадите вывод L/R микрофона на GND.

`testtx` и `testmic` работают, только когда рация на связи с мостом; без связи будет низкий гудок, как при обычном
нажатии. Услышать тон можно второй рацией или записать эфир на компьютере:
`python3 hub/sim_radio.py --hub 203.0.113.10 --key XXXX-XXXX-XXXX-XXXX listen --seconds 30 --out efir.wav`.

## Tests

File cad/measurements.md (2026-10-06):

# Замеры деталей (штангенциркулем, автор)

Всё, что ниже, — живые замеры; модель `radio_handheld.scad` берёт числа отсюда.

## 29.09.2026 — сборка рации 1 в корпус v3 (отзыв автора)

В целом расположение удобное. Что пришлось дорабатывать дремелем и что поправить:

| Место | Что было | Что просит автор |
|---|---|---|
| Модуль заряда | ниша под плату есть, но сзади на плату припаяны два резистора делителя — места нет, выпилил нишу под резисторы | ниша под резисторы |
| Регулятор KY-040 | штырьками к стенке корпуса: колодки проводов мама-мама упираются в стенку, регулятор не встаёт — подпилил корпус | место под колодки |
| Регулятор — направление | по часовой громкость УМЕНЬШАЕТСЯ, против — растёт | по часовой — громче |
| Защёлки усилителя | тесновато по ширине, отломилась боковая (гибкая) стенка | чуть просторнее по ширине |
| Планка микрофона | посередине подпилил: между колодками штырьков у́же, чем планка | у́же на 3 мм |
| Надписи сверху «Вкл» и «громкость» | не пропечатываются нормально | убрать |
| Держатель аккумулятора | саморезы у автора 3×12 — кончики вылезают на лицевой стороне | крепление под 3×12 |

Вопрос автора: что делает нажатие на ручку регулятора (кольцо горит фиолетовым)?

## 28.09.2026 — после сборки рации 1

| Деталь | Замер |
|---|---|
| Плата ESP32-S3 (YD, N16R8) | плата 63 × 28; плата + крышка модуля 4,7; штырьки от платы 8; отверстий нет. Антенна модуля выступает за край платы (по фото ≈6 мм), гнёзда USB-C — на другом конце. Подписи выводов — со стороны модуля |
| Что мешало с платой в v1 | плохо держится, штырьки задевают боковую кнопку, нет понятного места крепления |
| Динамик | крепёжные отверстия есть: между центрами 24, Ø2; магнит Ø27,3; «держатели» (лепестки) по кругу Ø28,7 |
| Вал регулятора | гладкий с лыской: Ø5,8, до среза 4,2 |
| Микрофон INMP441 | плата Ø13,4, толщина 0,7 (с SMD-деталями 1,7); штырьки прямые, со стороны БЕЗ деталей (там же дырочка звука); отверстий нет, по бокам полукруглые выемки, между ними 11,9. По фото: 2 столбика по 3 штырька (SD·VDD·GND и SCK·WS·L/R) |
| Усилитель MAX98357A | 17,3 × 18,8; штырьки торчат со стороны SMD-деталей; клеммника нет |
| Держатель 18650 (BeilaMoo) | 77,5 × 20,5 × 21; в дне 2 отверстия Ø3, между ними 55. Гнездо v2 было впору |
| Тумблер | корпус под панелью 14 × 12,7 × 7,8 |
| Кнопка «говорить» | в корпусе: глубина 20,3, Ø14,6 |
| Кольцо светодиодов | толщина 2,5, внутренний Ø36 |
| Саморезы | разные — автор подберёт |
| Гнёзда v2 | клеммы, держатель аккумулятора, динамик — по размеру |

## 27.09.2026

| Деталь | Замер |
|---|---|
| Модуль заряда | 20 × 26 × 4 |
| KY-040 | от оси до концов штырьков 20, от штырьков до противоположного края 32, резьба 12 |
| Микрофон | «Ø18» — по замеру 28.09 плата Ø13,4 (18 было, видимо, вместе с колодками) |
| Кольцо светодиодов | Ø50 |
| Динамик | 32 × 32 × 14,7 |
| Клеммы СМК 221-415 | 19,4 × 29,8 × 9,6 |

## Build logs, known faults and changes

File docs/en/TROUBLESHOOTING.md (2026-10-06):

[Русский](../TROUBLESHOOTING.md) · **English**

# If something isn't working

This page collects faults that turned up on real radios, plus hints from the firmware itself.
Every item follows the same pattern: **symptom → cause → what to do**.

The radio's settings page, the bridge status page and the logs are in Russian. Where this page quotes them, the
original Russian text is kept in «guillemets» with the English meaning in brackets, so you can match what you see.

Jump to:
[Ring colours](#ring-colours) ·
[Sounds](#radio-sounds) ·
[Where to look for clues](#where-to-look-for-clues) ·
[Connection](#connection) ·
[Audio](#audio) ·
[LED ring and knob](#led-ring-and-volume-knob) ·
[Power and charging](#power-and-charging) ·
[USB and firmware](#usb-and-firmware) ·
[Bridge](#bridge)

---

## Ring colours

The LED ring always shows the most important thing that is going on. The rows below go from more important to less
important: while an update is running, for example, the ring will show neither the volume nor the connection.

| What you see on the ring | What it means | What to do |
|---|---|---|
| The whole ring is dim white right after switching on | the radio is starting up | nothing; after a second or two the ring switches to its normal indication |
| The ring gradually fills with purple while you hold the PTT (push-to-talk) button during power-on | entering setup mode: after 1.5 s the `RADIO-XXXX` access point will open | release the button once the ring has filled; a low beep after that is normal |
| The whole ring flashes red rapidly while you hold the volume knob pressed | from the 5th second — a warning that settings are about to be reset | changed your mind — let go; at the 10th second the settings are reset (see [Reset](#reset-settings)) |
| A blue bar grows around the ring | the firmware is being updated | **do not switch off** the radio; after the update it restarts by itself |
| The whole ring flashes **red** briefly and rapidly | the channel is busy: someone is already talking, or the bridge refused | wait until the other transmission ends and press again |
| The whole ring flashes **orange** briefly and rapidly | you pressed the button but there is no connection (or the bridge didn't answer within 0.7 s), or the connection to the bridge has just been lost | check what the ring shows when idle — further down this table |
| A bar on the ring after you hold the knob for 1–4 s | battery charge: the more LEDs, the more charge | green — over 40 %, amber — 16–40 %, red — 15 % or less |
| …a dim white ring instead of the bar | the charge is still being measured (the first ≈ 20 s after power-on) | wait and look again |
| …a blue ring instead of the bar | the radio doesn't see the battery and assumes it is powered from USB | if the battery is in place, check the battery voltage divider, see [below](#charge-always-shows-нет-питание-от-usb-no-battery-usb-power) |
| A white bar for 1.5 s after turning the knob | volume (0–20) | a purple bar means the sound is muted |
| A red ring "dances" in time with your voice | you are talking and can be heard | — |
| Two white LEDs run quickly around the ring | you pressed the button; the radio is waiting for the bridge's permission | wait for the "beep-beep", then talk |
| A green ring "dances" in time with a voice | someone else is talking | — |
| A light blue ring gently "breathes" | someone is talking, but your sound is muted | press the knob to unmute |
| The whole ring slowly "breathes" purple | the `RADIO-XXXX` access point is open and there is no connection to the bridge: the radio doesn't know any Wi-Fi network, no network key is set, Wi-Fi has been gone for more than a minute, or the access point was opened with the button at power-on | connect to `RADIO-XXXX` with a phone and read the status line on the page. If the network simply dropped out, don't touch anything — the radio will reconnect by itself |
| One blue LED runs around the ring | looking for Wi-Fi | wait; after a minute without a network the access point opens (purple "breathing") |
| Two opposite orange LEDs blink: half a second on, half a second off | Wi-Fi is there, the bridge isn't | see [Radio can't find the bridge](#radio-cant-find-the-bridge) |
| Red and purple LEDs alternate and slowly shift around | the bridge answers, but the network key doesn't match | see [Wrong network key](#wrong-network-key) |
| Two opposite **green** LEDs flash briefly once every 3 s | all is well, the radio is connected | — |
| …**amber** flashes once every 3 s | connected to the bridge, but not all bridges in its `peers` list are online | see [Amber flashes](#amber-flashes-instead-of-green) |
| …**red** flashes once every 3 s | the charge has been at 15 % or less for half a minute — time to charge | put it on charge |
| One purple LED is lit steadily (along with the flashes) | the sound is muted | press the knob |
| The ring glows steadily and dimly (green or amber) | the radio is connected and running on USB power, not the battery | — |

When idle, the ring is almost dark — just a short flash once every 3 seconds: that way it uses less battery.

## Radio sounds

| Sound | What it means |
|---|---|
| rising "beep-beep" | the channel is yours — talk |
| "boo-boo-boo" (three low beeps) | the channel is busy (busy tone) |
| one long low beep | no connection: you pressed the button with no connection, the bridge didn't answer, or the button was held for more than 90 s — release it and press again |
| two falling tones | the connection to the bridge is lost (it has been silent for more than 6.5 s) |
| rising "tee-doo" | the radio has connected to the bridge |
| falling "tee-doo" | someone else's transmission has ended (turned off with the «Сигнал в конце чужой передачи» (Tone at the end of someone else's transmission) checkbox) |
| short click | one volume step |
| three falling notes | battery at 15 % or less: once every 5 minutes, and from 5 % — once a minute |

These service signals are heard even when the sound is muted — quietly, so you know the button worked.

## Where to look for clues

1. **Radio settings page.** On the same network as the radio, open `http://radio-xxxx.local` (xxxx is the last
   4 characters of its access point name, in lowercase). If `.local` doesn't open (happens on Android), find
   `radio-xxxx` in your router's device list and type its numeric address. Or hold the PTT button while
   switching on — the `RADIO-XXXX` access point opens; connect to it and open `http://192.168.4.1`.
   The page shows: connection status, Wi-Fi signal, the bridge and the delay to it, charge, «Приём: сыграно / потеряно»
   (Received: played / lost), «Работает … · запуск: *reason for the last start*» (Running … · started by: …),
   «Свист рядом с другой рацией» (Howl near another radio) and, if something is broken, an «Ошибка» (Error)
   line.
2. **Bridge status page** `http://203.0.113.10:47080/` (use your own bridge's address; if `status_token` is set in
   the bridge settings, append `?t=token`). It shows the list of radios with their charge, who is talking right now,
   and the event log.
3. **Radio log over USB.** Connect the board with a cable and open a serial monitor at 115200 baud — for example, in
   the Arduino IDE (Serial Monitor, line ending "New Line") or like this:

   ```bash
   arduino-cli monitor -p /dev/cu.usbmodem1101 -c baudrate=115200
   ```

   Your port name will be different: on macOS `/dev/cu.usbmodem…` or `/dev/cu.wchusbserial…`, on Linux
   `/dev/ttyACM0` or `/dev/ttyUSB0`, on Windows `COM3` and so on. The log goes to both of the board's USB ports.
   Useful commands (type one and press Enter):

   | Command | What it does |
   |---|---|
   | `show` | the full status: id, name, bridge, Wi-Fi, charge, amplifier, receive statistics |
   | `help` | a list of all commands |
   | `micraw` | one second of raw microphone data on both channels — a microphone check without the bridge |
   | `testmic 10` | transmits the live microphone to the channel for 10 seconds, as if the button were held |
   | `testtx 5 1000` | transmits a 1000 Hz tone to the channel for 5 seconds instead of the microphone |
   | `amp i2s` / `amp pdm` | which amplifier is fitted: MAX98357A (I2S) or the analogue PAM8403 via a filter; the radio restarts |
   | `reboot` | restart |
   | `factory` | full reset, including the network key, the name and the bridge address |

4. **Software radio on a computer** — to check the bridge and the audio when you only have one radio at hand
   (substitute your bridge's address and your own key):

   ```bash
   # did the bridge answer, how many radios are on the network
   python3 hub/sim_radio.py --hub 203.0.113.10 --key XXXX-XXXX-XXXX-XXXX status
   # "parrot": say a phrase into the radio, release the button — you will hear yourself
   python3 hub/sim_radio.py --hub 203.0.113.10 --key XXXX-XXXX-XXXX-XXXX echo
   # 10 seconds of an 800 Hz tone to all radios — speaker check
   python3 hub/sim_radio.py --hub 203.0.113.10 --key XXXX-XXXX-XXXX-XXXX tone --seconds 10
   ```

5. **Multimeter.** DC voltage mode, 20 V range (on the dial — `V⎓ 20` or `DCV 20`).
   Black probe on GND, red probe on the point you are checking. On signal lines carrying pulses, a multimeter shows
   the average value: on clock lines that is ≈ 1.6 V — half of 3.3 V.

---

## Connection

### Radio won't connect to Wi-Fi

**Symptom:** the blue LED runs around for a long time, then the ring "breathes" purple; the page says «нет Wi-Fi»
(no Wi-Fi).

**Causes and what to do:**

- **5 GHz network.** The ESP32-S3 only works with 2.4 GHz Wi-Fi. Enable 2.4 GHz on the router. For an iPhone
  hotspot, turn on "Maximize Compatibility" — then it runs on 2.4 GHz.
- **Wrong password.** Connect to `RADIO-XXXX` and add the same network again with the correct password — the password
  will be updated.
- **A guest network with a login page** (as in hotels and cafés) won't work: the radio can't press "Log in".
- **A hidden network** won't appear in the «Найти» (Find) list — type its name in manually.
- **The phone is still connected to `RADIO-XXXX`.** While anyone is connected to the access point, the radio doesn't
  try to join Wi-Fi, so as not to get in the way of setup. When you're done, disconnect the phone from it.
- The radio remembers **up to three networks**; if you add a fourth, the oldest one is forgotten.

If there has been no Wi-Fi for 15 minutes and nobody is connected to its access point, the radio restarts itself —
that's normal, it's how it cures a "stuck" Wi-Fi.

### Radio can't find the bridge

**Symptom:** two orange LEDs blink; pressing the button gives a long low beep and orange flashing;
the radio settings page says «ищу мост» (looking for the bridge).

**Causes and what to do:**

1. **The «Адрес моста» (Bridge address) field is empty.** Then the radio only looks for the bridge on its own network
   (the page shows «Мост: ищу в своей сети» (Bridge: searching my own network)). A bridge on the internet has to be
   entered: `203.0.113.10`, `radio.example.com` or with a port — `radio.example.com:47000`. The default port is 47000.
   If the bridge really is on your network, it must be on the same subnet as the radio, and the router must not have
   "client isolation" enabled (guest networks usually do) — otherwise the radio won't hear it.
2. **The bridge name can't be resolved.** The radio page shows «Ошибка: адрес «…» не найден» (Error: address "…" not
   found). Check the spelling and the DNS record for the name (DNS is the internet's "phone book" that turns a name
   into an address).
3. **The bridge isn't running.** Open the bridge status page `http://203.0.113.10:47080/`. If it doesn't open, check
   the service: on Linux `systemctl status walkie-hub` and `journalctl -u walkie-hub -f`, on Windows — the `hub.log`
   file next to `hub.json`.
4. **UDP port 47000 is closed on the server.** The bridge installers open it themselves in the built-in firewall (ufw on
   Linux, Windows Firewall), but a cloud server also has **network rules in the provider's console** — UDP 47000 and
   TCP 47080 have to be allowed there by hand. If the bridge is at home behind a router, the router needs port
   forwarding of these ports to the computer running the bridge. Details — [BRIDGE.md](BRIDGE.md).
5. **The radio's network doesn't let UDP out.** Some office and guest networks block it. Try the radio on a phone
   hotspot.

A quick check from a computer on the same network as the radio:
`python3 hub/sim_radio.py --hub 203.0.113.10 --key XXXX-XXXX-XXXX-XXXX status`. The reply «мост … ответил за N мс»
(bridge … answered in N ms) means the bridge and the port are fine — look for the mistake in the radio's settings.
«Мост … не ответил за 5 с» (bridge … did not answer within 5 s) means the problem is the bridge, the port or the network.

### Wrong network key

**Symptom:** red and purple LEDs alternate; the radio page says «мост отвечает, но ключ сети не
совпадает» (the bridge answers, but the network key doesn't match); the bridge log shows «⚠ пакет раций с неверной
подписью от … — не тот ключ сети?» (radio packet with an invalid signature from … — wrong network key?).

**Cause:** the key in the radio doesn't match the `key` field in the bridge's `hub.json`.

**What to do:**

- Enter the same key in the radio as in the bridge. Letter case, spaces and hyphens don't matter: `k7q2 mx9p…` and
  `K7Q2-MX9P-…` are the same key. It needs at least 12 letters and digits.
- **Latin letters and digits only.** The firmware counts only Latin letters and digits in the key, while the Python
  bridge counts Cyrillic letters too, so a key with Cyrillic in it will never match between them. The safest choice is
  a key generated by the bridge itself: `python3 hub/walkie_hub.py --genkey`.
- Changed the key in `hub.json`? Restart the bridge: it reads its settings only at startup.
- The radio can store a key of up to 39 characters including hyphens — anything longer is cut off.
- Linked bridges (`peers`) must all share one key as well.

If no key is set at all, the radio keeps its access point open (purple "breathing"), and the page says «нет ключа
сети» (no network key).

### Amber flashes instead of green

**Cause:** the radio is connected to its own bridge, but one of the bridges in that bridge's `peers` list is
unreachable. Radios on this bridge hear each other, but radios behind the unreachable bridge don't.

**What to do:** on the bridge status page, look at the «Другие мосты» (Other bridges) section and the log («⚠ мост
пропал: …» (bridge lost: …)). Check that the second bridge is running, that the bridges can reach each other over
UDP 47000 (via the internet or a VPN), and that they have **different names** (`name` in `hub.json`): a bridge derives
its number from its name, and it will take a bridge with the same name for itself.
See [BRIDGE.md](BRIDGE.md).

### "Boo-boo-boo" when you press, though nobody is talking

- The bridge keeps the channel for the speaker for another 0.8 s after their last sound — press a little later.
- If people in two places press at the same moment, the same speaker wins on every bridge, and the other one gets the
  busy tone.
- Another radio's button is stuck: the bridge will end its transmission by itself after 90 s. The bridge status page
  shows who is talking.

### Audio breaks up or "gurgles"

**Cause:** network losses — most often a weak Wi-Fi signal at the radio.

**What to do:**

- Check the Wi-Fi signal on the radio page: −50 dBm is excellent, −70 dBm and below is weak. Move the radio closer
  to the router or add an access point.
- The board's antenna is the protruding end of the module, the part without the metal cover. Don't press wires or
  metal against it.
- The «Приём: сыграно / потеряно» (Received: played / lost) line on the radio page shows how many 20 ms chunks of
  speech were lost. The software radio gives a more detailed picture of delivery jitter:
  `python3 hub/sim_radio.py --hub 203.0.113.10 --key XXXX-XXXX-XXXX-XXXX listen --seconds 60`.
- The radio buffers 60–160 ms of speech and, after dropouts, automatically keeps a bigger margin.

---

## Audio

### Bridge reports «в передаче одна тишина — проверьте микрофон» ("only silence in the transmission — check the microphone")

**Symptom:** the bridge log shows «⚠ *radio name*: в передаче одна тишина — проверьте микрофон», and the radio list
shows «тишина в передачах: N» (silence in transmissions: N). Other radios hear only silence. The bridge raises this
warning if a transmission lasted more than 0.5 s and the sound level hardly rose above zero.

**The most common cause is an unsoldered pin of the pin header on the microphone module**, most often SCK. The
female-female jumper wire is pushed onto the pin, the pin has voltage on it, but the signal never reaches the module
itself.

**What to do.** Switch the radio on and check the pins of the INMP441 microphone with a multimeter (20 V range, black
probe on GND). Put the red probe **on the solder joint on the module side**, not on the header pin or the wire's
connector:

| Microphone pin | Should read |
|---|---|
| VDD | 3.3 V |
| SCK | ≈ 1.6 V (average of the pulses) |
| WS | ≈ 1.6 V |
| L/R | 0 V (connected to GND) |

In the faulty radio, SCK at the module did not show ≈ 1.6 V, and SD showed ≈ 0. Resolder **all six** header pins
and check again.

**Microphone on the right channel.** If L/R reads 3.3 V instead of 0, the microphone puts its sound on the right
channel, while the firmware listens to the left one. Either connect L/R to GND, or tick «Микрофон на правом канале
(вывод L/R на 3,3 В)» (Microphone on the right channel (L/R pin at 3.3 V)) on the radio page.

**Check without the bridge.** With the `micraw` command over USB (see [Where to look for clues](#where-to-look-for-clues))
the radio shows what is coming from the microphone: `L: min…max  R: min…max`. Say something and repeat the command: on
a working microphone the spread on its own channel (L, if L/R is on GND) grows noticeably with your voice. If both
channels sit on a single number (`0…0`, `−1…−1`), there is no data: check the soldering and the wires SD → pin 6,
SCK → pin 5, WS → pin 4.

**End-to-end check.** Run the "parrot" (`sim_radio.py … echo`), say a phrase and release the button — you should
hear yourself. Or use the `testmic 10` command to send 10 seconds of live microphone to the channel without the
button.

### No sound from the speaker

**Simple things first:**

- The volume isn't at zero: turn the knob — the white bar should grow.
- The sound isn't muted: if a single purple LED is lit or the ring "breathes" light blue, press the knob.
- The radio page doesn't show the line «Ошибка: звук не запустился (проверьте провода I2S)» (Error: audio didn't start
  (check the I2S wires)).
- The `show` command over USB says «усилитель: MAX98357A (I2S)» (amplifier: MAX98357A (I2S)). If it says PAM8403 but a
  MAX98357A is fitted — `amp i2s`.

**A common cause when the power is fine is a bad contact on the DIN or GND pin of the MAX98357A amplifier.** On one of
the radios, sound only appeared while the multimeter probes were pressed against these pins. Resolder the amplifier's
pin header.

**Multimeter check** on the amplifier pins (black probe on GND). To get some sound going, send a tone from the computer
(`sim_radio.py … tone --seconds 20`) or turn the knob — every step makes a click:

| Amplifier pin | Should read |
|---|---|
| Vin | 4.5–5 V |
| SD | ≈ 3.3 V while sound is playing and for another 3 s after. In silence the firmware puts the amplifier to sleep (so it doesn't hiss) — then SD reads 0 V, which is normal |
| BCLK, LRC | ≈ 1.6 V (average of the pulses) |

Also check that:

- the speaker is soldered to the "+" and "−" pads of the amplifier's **output**, and the speaker's minus is **not**
  connected to GND — both of the amplifier's outputs are driven;
- the amplifier's GAIN pin isn't connected to anything;
- the wires go: DIN → pin 7, BCLK → pin 15, LRC → pin 16, SD → pin 17.

### The other person sounds quiet or distorted

- «Автоусиление микрофона» (microphone automatic gain control, AGC) is on by default: the firmware adjusts the gain by
  itself (up to +36 dB) and keeps the sound from overloading. If it has been turned off, the microphone level is set by
  the «Усиление, если автоусиление выключено» (Gain if AGC is off) field — from 0 to 42 dB, default 24.
- Your own volume is set with the knob: 21 steps (0–20) of 2 dB each.

### Howl when two radios are close together

**Cause:** an acoustic loop. The talking radio's microphone hears the speaker of the radio next to it, the sound goes
round and round through the bridge and at some frequency builds up into a howl — ordinary walkie-talkies howl in
exactly the same way when they stand next to each other.

**What to do:** the firmware detects a growing howl by itself and cuts out its frequency with a narrow filter; if the
howl comes back in the same transmission, it also turns the microphone down. The radio page shows whether the
protection kicked in: «Свист рядом с другой рацией: гасили N раз, последний на … Гц» (Howl near another radio:
suppressed N times, last one at … Hz). But it's better not to let it come to that: move the radios apart or turn down
the volume on the listening one.

---

## LED ring and volume knob

### Ring doesn't light up

- «Яркость подсветки» (LED brightness) on the radio page is set to 0 — raise it (the default is 60).
- If it never lit up at all within 10 seconds of power-on — check the power switch and the 5 V lever connector.
- The data wire must go from pin 18 to the ring's **DI** (DIN) input, not to the DO output.

### Ring flashes the "wrong" colours

**Cause:** the 1N4007 diode is missing from the ring's 5 V power wire (or it is fitted the wrong way round). WS2812
LEDs powered from exactly 5 V don't read the 3.3 V signal from the board well; the diode drops their supply to about
4.3 V, and the signal is read reliably.

**What to do:** put the diode in series with the ring's 5 V wire, **stripe towards the ring**.

### Knob turns the wrong way

Tick **«Регулятор крутится наоборот»** (Volume knob turns the other way) on the radio page. Or swap the CLK and DT wires:
per the wiring diagram, CLK → pin 2, DT → pin 42 — then clockwise is louder.

### Knob doesn't respond

Check the wires: CLK → pin 2, DT → pin 42, SW → pin 41, "+" → **3V3** (3.3 V only, not 5 V!),
GND → G on the board. Pressing the knob cap should give a click: push the knob cap onto the shaft leaving a 1.5–2 mm
gap above the end of the bushing.

---

## Power and charging

### Radio "switches itself off" when idle

**Symptom:** the radio was lying unused and went completely dark — the ring is off and it doesn't respond to the
buttons.

**Cause:** the charger module is built like a power bank. If the radio draws too little current, the module decides
the load has been unplugged and switches off its 5 V output. That's why «Экономия аккумулятора» (Battery saving — Wi-Fi
dozes while the channel is quiet) is **off by default**.

**What to do:** don't turn power saving on with modules like these. If the box is ticked, untick it on the radio page.

If the radio doesn't go dark but **restarts**, look at the «Работает … · запуск: …» (Running … · started by: …) line
on the page:

| Start reason | What it means |
|---|---|
| «включение питания» (power-on) | a normal power-on with the power switch |
| «просадка питания» (brownout) | the voltage dropped for an instant. Right after switching on with the power switch — normal (see below). In the middle of operation — the battery is running low, or there is a bad contact in the lever connectors |
| «сторож: зависание» (watchdog: hang) | the program didn't respond for 30 s and the watchdog restarted the radio |
| «сбой программы» (software crash) | a bug in the firmware — save the log over USB and attach it to a bug report (issue) in the repository |
| «перезапуск программой» (restart by software) | after a firmware update, the «Перезапустить» (Restart) button or the `reboot` command, a settings reset, an amplifier change, adding a network through the access point, or 15 minutes without Wi-Fi |

### Radio reboots when shaken

**Cause:** a wire isn't held well in a lever connector. The thin core of a female-female jumper wire doesn't sit
reliably in the 5-way lever connector.

**What to do:** strip 20–22 mm off the end, fold the core in half and twist it tightly — you get a doubled tip of
10–11 mm. Push it all the way in, close the lever and give it a tug: the wire must not come out.

### Power switch doesn't turn the radio on after a battery swap

**Cause:** the battery was taken out and put back — the charger module has "fallen asleep" and doesn't turn on its 5 V
output.

**What to do:** plug in a USB-C charger for a couple of seconds. If the module has a button, you can press that
instead.

### Charger module LEDs stay on after the power switch is turned off

The firmware can't fix this: the board has no power at that moment. Possible causes:

- a charger is plugged in — then the LEDs are supposed to be on;
- the module has switched to "low current" mode (some modules turn it on by themselves);
- something is connected to the module's output bypassing the power switch — check that the OUT+ output goes **only**
  to the power switch;
- the module is from a different series and behaves in its own way.

A module like this slowly drains the battery even when the radio is switched off. One possible modification: move the
power switch to the battery wire (between the 18650 holder and the module's B+ pad). Then the module is completely
unpowered when the radio is off, but the battery only charges while the power switch is on.

### 0.4–0.5 V on the 5 V bus with the radio switched off

Normal. That's the leftover charge in the capacitors plus a tiny current through the battery voltage divider (two
100 kΩ resistors — hundredths of a milliamp). The voltage slowly falls; it doesn't drain the battery.

### Start reason «просадка питания» (brownout) after switching on with the power switch

Normal: at the moment you switch on, the capacitors on the boards charge up and the voltage sags for a fraction of a
second. It doesn't affect how the radio works.

### Charge shows «измеряется…» (measuring…) or doesn't change

That's by design: under load (Wi-Fi, speaker, ring) the battery voltage sags by 0.2–0.3 V, and an honest reading at
that moment would show too low a charge. The estimation rules (details in
[firmware/walkie/battery_est.h](../../firmware/walkie/battery_est.h)):

- **For the first ≈ 20 s after power-on** the charge isn't reported — «измеряется» (measuring): for 15 s the radio
  takes no readings (Wi-Fi connects at full power), then it collects 5 quiet readings.
- **While talking and receiving**, and also during a firmware update or a Wi-Fi search, no readings are taken — and
  none for another 3 s after. The charge freezes for that time and catches up right after the pause. If the radio is
  "busy" for more than 5 minutes without a break, readings are taken anyway — so that a discharge doesn't go
  unnoticed.
- A reading is taken once a second; the estimate is the highest of the last 30 quiet readings. It rises immediately and
  falls gradually, so short voltage dips don't throw off the percentage.
- **"Time to charge"** (red flashes and three falling notes) — only if the charge stays at 15 % or less for 30 s in a
  row. It clears when the charge rises to 18 %.
- The percentage is a rough voltage scale: 3.30 V is 0 %, 4.15 V is 100 %.
- While charging, the percentage reads high: the voltage is higher under charge. The accurate value comes after you
  unplug the cable.

The raw last reading is shown by the `show` command over USB («замер N мВ» (reading N mV)). If the percentage is far
off from the battery voltage measured with a multimeter, check that both divider resistors are 100 kΩ.

### Charge always shows «нет (питание от USB)» (no battery, USB power)

**Cause:** pin 8 sees less than 2.5 V when converted to battery voltage — the firmware decides there is no battery.

**What to do:** check the divider: 100 kΩ resistors to the **B+** and **B−** pads of the charger module (not to OUT+),
with the divider's midpoint wired to pin 8. Pin 8 should show about half the battery voltage (1.6–2.1 V). Without the
divider the radio works, but it won't know when the battery is running low.

---

## USB and firmware

### Board not visible over USB, or "No serial data received"

- **A charge-only cable** — use a cable that carries data.
- **The COM port doesn't work with a C-to-C cable.** On some boards the COM port lacks the necessary resistors, and
  with a USB-C to USB-C cable the board doesn't even get power. Connect to the **USB** port (the ESP32-S3's native
  port) or use a USB-A to USB-C cable.
- **Enter the bootloader by hand:** hold the **BOOT** button, press and release **RST**, release BOOT. Now flash. If
  after flashing through the USB port the board stays in the bootloader, press RST.
- On Windows you may need a driver for the USB-UART chip that the COM port goes through (on clone boards it is
  usually a CH340 or CH343).

How to flash — [SETUP.md](SETUP.md).

### Firmware won't update over the air

The radio downloads new firmware from the bridge only when all of these are true at once:

- the number in `walkie.json` on the bridge is **greater** than the radio's version (shown on the radio page, in the
  «Прошивка» (Firmware) section);
- the radio is connected to the bridge and nobody has talked for 20 seconds;
- the radio can reach the bridge's **TCP 47080** — the firmware is downloaded from there. If the port is closed, there
  will be no update either;
- the previous attempt didn't fail less than an hour ago. After a failure the radio waits an hour; restart it to try
  straight away.

The bridge status page should show the line «прошивка для раций: версия N» (firmware for radios: version N); while a
radio is downloading the file, the log shows «рация … скачивает прошивку N» (radio … is downloading firmware N), and a
blue bar grows on the ring. The bridge rescans its `firmware/` folder every 10 s.

By hand: radio page → «Загрузить прошивку» (Upload firmware) → the **`walkie.bin`** file. Don't confuse it with
`walkie-full-v…bin` — that one is only for the very first flash over a cable, at address 0x0.

### Radio settings page won't open

- The computer or phone must be on the same Wi-Fi network as the radio.
- `http://radio-xxxx.local` doesn't open everywhere (it often doesn't on Android) — find the radio's address in the
  router's device list or with the `show` command over USB.
- The access point always works: hold the PTT button while switching on, connect to `RADIO-XXXX`, open
  `http://192.168.4.1`. An access point opened with the button stays up until the radio is switched off.

### Reset settings

- **With the knob:** hold it pressed for 10 seconds. From the 5th second the ring flashes red — let go if you've
  changed your mind. This resets the Wi-Fi networks, volume, brightness and the other audio and ring settings. **The
  network key, the radio name and the bridge address are kept**, so the radio can be put back on the channel just by
  entering Wi-Fi from a phone.
- **Completely**, including the key and the bridge address — with the `factory` command over USB.

---

## Bridge

### Bridge status page won't open

- **TCP 47080** is closed — in the server's firewall or in the cloud provider's network rules.
- A reply of «нужен ?t=<токен>» (?t=<token> required) means `status_token` is set in `hub.json`; append `?t=` and the
  token itself to the address.
- The radios work without the page, but over-the-air (OTA) updates go through the same port 47080.

### Bridge won't start or keeps restarting

- Linux: `journalctl -u walkie-hub -f`. The service restarts the bridge if it crashes, and a self-check every
  2 minutes restarts it if it stops responding (`journalctl -t walkie-hub` — «мост не ответил на самопроверку —
  перезапуск» (bridge did not respond to the self-check — restarting)).
- Windows: the `hub.log` file next to `hub.json`; the Task Scheduler task is called `WalkieHub`.
- `hub.json` must be valid JSON and must contain `key`.
- Don't start a second copy of the bridge next to the running service: ports 47000 and 47080 must be free.
  A second copy will either fail to start ("Address already in use") or interfere with the first one.

Installing and setting up the bridge — [BRIDGE.md](BRIDGE.md).

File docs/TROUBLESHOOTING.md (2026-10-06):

**Русский** · [English](en/TROUBLESHOOTING.md)

# Если что-то не работает

Здесь собраны неисправности, которые встречались на настоящих рациях, и подсказки из самой прошивки.
Каждый пункт устроен одинаково: **признак → причина → что делать**.

Быстрый переход:
[Цвета кольца](#цвета-кольца) ·
[Звуки](#звуки-рации) ·
[Где искать подсказки](#где-искать-подсказки) ·
[Связь](#связь) ·
[Звук](#звук) ·
[Кольцо и регулятор](#кольцо-и-регулятор) ·
[Питание и заряд](#питание-и-заряд) ·
[USB и прошивка](#usb-и-прошивка) ·
[Мост](#мост)

---

## Цвета кольца

Кольцо всегда показывает самое важное из того, что происходит. Строки ниже — от более важного к менее важному:
пока идёт обновление, например, кольцо не покажет ни громкость, ни связь.

| Что видно на кольце | Что это значит | Что делать |
|---|---|---|
| Всё кольцо тускло-белое сразу после включения | рация запускается | ничего, через секунду-две кольцо перейдёт к обычной индикации |
| Кольцо постепенно наливается фиолетовым, пока держите кнопку «говорить» при включении | вход в режим настройки: через 1,5 с откроется точка доступа `RADIO-XXXX` | отпустите кнопку, когда кольцо налилось; низкий гудок после этого — нормально |
| Всё кольцо часто мигает красным, пока держите регулятор нажатым | с 5-й секунды — предупреждение о сбросе настроек | передумали — отпустите; на 10-й секунде настройки сбросятся (см. [Сброс](#сбросить-настройки)) |
| Синяя полоса растёт по кругу | обновляется прошивка | **не выключайте** рацию; после обновления она перезапустится сама |
| Всё кольцо коротко и часто мигает **красным** | эфир занят: кто-то уже говорит или мост отказал | дождитесь конца чужой передачи и нажмите снова |
| Всё кольцо коротко и часто мигает **оранжевым** | нажали кнопку, а связи нет (или мост не ответил за 0,7 с), либо только что пропала связь с мостом | смотрите, что кольцо показывает в покое, — ниже в этой таблице |
| Шкала на кольце после того, как подержали регулятор 1–4 с | заряд аккумулятора: сколько огоньков — столько заряда | зелёная — больше 40 %, янтарная — 16–40 %, красная — 15 % и меньше |
| …тускло-белое кольцо вместо шкалы | заряд ещё измеряется (первые ≈ 20 с после включения) | подождите и посмотрите ещё раз |
| …синее кольцо вместо шкалы | рация не видит аккумулятор и считает, что питается от USB | если аккумулятор на месте — проверьте делитель заряда, см. [ниже](#заряд-всегда-нет-питание-от-usb) |
| Белая шкала на 1,5 с после поворота регулятора | громкость (0–20) | фиолетовая шкала — звук выключен |
| Красное кольцо «пляшет» в такт голосу | вы говорите, вас слышно | — |
| Два белых огонька быстро бегут по кругу | нажали кнопку, рация ждёт разрешения моста | ждите «пи-пи», потом говорите |
| Зелёное кольцо «пляшет» в такт голосу | говорит кто-то другой | — |
| Голубое кольцо мягко «дышит» | кто-то говорит, а у вас звук выключен | нажмите на регулятор, чтобы включить звук |
| Всё кольцо медленно «дышит» фиолетовым | открыта точка доступа `RADIO-XXXX`, а связи с мостом нет: рация не знает Wi-Fi, не задан ключ сети, Wi-Fi нет дольше минуты или точку открыли кнопкой при включении | подключитесь к `RADIO-XXXX` телефоном и посмотрите строку состояния на странице. Если сеть просто пропала — ничего не трогайте, рация подключится сама |
| Один синий огонёк бежит по кругу | ищет Wi-Fi | ждите; через минуту без сети откроется точка доступа (фиолетовое «дыхание») |
| Два противоположных оранжевых огонька мигают: полсекунды горят, полсекунды нет | Wi-Fi есть, моста нет | см. [Рация не находит мост](#рация-не-находит-мост) |
| Красные и фиолетовые огоньки через один, медленно сдвигаются | мост отвечает, но ключ сети не совпадает | см. [Не тот ключ сети](#не-тот-ключ-сети) |
| Два противоположных **зелёных** огонька коротко вспыхивают раз в 3 с | всё в порядке, рация на связи | — |
| …**янтарные** вспышки раз в 3 с | связь с мостом есть, но не все мосты из его списка `peers` на связи | см. [Янтарные вспышки](#янтарные-вспышки-вместо-зелёных) |
| …**красные** вспышки раз в 3 с | заряд 15 % и меньше уже полминуты — пора на зарядку | поставьте на зарядку |
| Один фиолетовый огонёк горит постоянно (вместе со вспышками) | звук выключен | нажмите на регулятор |
| Кольцо светится ровно и тускло (зелёным или янтарным) | рация на связи и питается от USB, а не от аккумулятора | — |

В простое кольцо почти не светится — только короткая вспышка раз в 3 секунды: так меньше расходуется аккумулятор.

## Звуки рации

| Звук | Что значит |
|---|---|
| «пи-пи» вверх | эфир ваш — говорите |
| «бу-бу-бу» (три низких гудка) | эфир занят |
| один длинный низкий гудок | нет связи: нажали кнопку без связи, мост не ответил, или кнопку держали дольше 90 с — отпустите и нажмите снова |
| два тона вниз | пропала связь с мостом (он молчит дольше 6,5 с) |
| «ти-ду» вверх | рация подключилась к мосту |
| «ти-ду» вниз | чужая передача закончилась (отключается галочкой «Сигнал в конце чужой передачи») |
| короткий щелчок | шаг громкости |
| три ноты вниз | аккумулятор 15 % и меньше: раз в 5 минут, а с 5 % — раз в минуту |

Служебные сигналы слышны и при выключенном звуке — тихо, чтобы было понятно, что кнопка сработала.

## Где искать подсказки

1. **Страница рации.** В той же сети, что рация, откройте `http://radio-xxxx.local` (xxxx — последние
   4 знака имени её точки доступа, маленькими буквами). Если `.local` не открывается (бывает на Android) — найдите
   `radio-xxxx` в списке устройств роутера и наберите его адрес цифрами. Или держите кнопку «говорить» при
   включении — откроется точка `RADIO-XXXX`, подключитесь к ней и откройте `http://192.168.4.1`.
   На странице: состояние связи, сигнал Wi-Fi, мост и задержка до него, заряд, «Приём: сыграно / потеряно»,
   «Работает … · запуск: *причина последнего запуска*», «Свист рядом с другой рацией», а если что-то сломано —
   строка «Ошибка».
2. **Страница моста** `http://203.0.113.10:47080/` (подставьте адрес своего моста; если в настройках моста задан
   `status_token` — допишите `?t=токен`). Там список раций с зарядом, кто сейчас говорит и журнал событий.
3. **Журнал рации по USB.** Подключите плату кабелем и откройте монитор порта на скорости 115200 — например, в
   Arduino IDE (Serial Monitor, окончание строки «Newline») или так:

   ```bash
   arduino-cli monitor -p /dev/cu.usbmodem1101 -c baudrate=115200
   ```

   Имя порта у вас будет своё: на macOS `/dev/cu.usbmodem…` или `/dev/cu.wchusbserial…`, на Linux
   `/dev/ttyACM0` или `/dev/ttyUSB0`, на Windows `COM3` и т. п. Журнал идёт в оба USB-гнезда платы.
   Полезные команды (набрать и нажать Enter):

   | Команда | Что делает |
   |---|---|
   | `show` | всё состояние: id, имя, мост, Wi-Fi, заряд, усилитель, статистика приёма |
   | `help` | список всех команд |
   | `micraw` | сырые данные с микрофона по обоим каналам за секунду — проверка микрофона без моста |
   | `testmic 10` | 10 секунд передаёт в эфир живой микрофон, как будто держат кнопку |
   | `testtx 5 1000` | 5 секунд передаёт в эфир тон 1000 Гц вместо микрофона |
   | `amp i2s` / `amp pdm` | какой усилитель стоит: MAX98357A (I2S) или аналоговый PAM8403 через фильтр; рация перезапустится |
   | `reboot` | перезапуск |
   | `factory` | полный сброс, включая ключ сети, имя и адрес моста |

4. **Программная рация на компьютере** — проверить мост и звук, когда под рукой одна рация
   (подставьте адрес своего моста и свой ключ):

   ```bash
   # ответил ли мост, сколько раций в сети
   python3 hub/sim_radio.py --hub 203.0.113.10 --key XXXX-XXXX-XXXX-XXXX status
   # «попугай»: скажите фразу в рацию, отпустите кнопку — услышите себя
   python3 hub/sim_radio.py --hub 203.0.113.10 --key XXXX-XXXX-XXXX-XXXX echo
   # 10 секунд тона 800 Гц во все рации — проверка динамика
   python3 hub/sim_radio.py --hub 203.0.113.10 --key XXXX-XXXX-XXXX-XXXX tone --seconds 10
   ```

5. **Мультиметр.** Режим постоянного напряжения, предел 20 В (на переключателе — `V⎓ 20` или `DCV 20`).
   Чёрный щуп — на GND, красный — на проверяемую точку. Сигнальные линии с импульсами мультиметр показывает как
   среднее значение: у линий тактов это ≈ 1,6 В — половина от 3,3 В.

---

## Связь

### Рация не подключается к Wi-Fi

**Признак:** долго бежит синий огонёк, потом кольцо «дышит» фиолетовым; на странице — «нет Wi-Fi».

**Причины и что делать:**

- **Сеть 5 ГГц.** ESP32-S3 работает только с Wi-Fi 2,4 ГГц. Включите 2,4 ГГц на роутере. Раздача с iPhone:
  включите «Максимальная совместимость» — тогда она идёт на 2,4 ГГц.
- **Неверный пароль.** Подключитесь к `RADIO-XXXX` и добавьте ту же сеть ещё раз с верным паролем — пароль
  обновится.
- **Гостевая сеть со страницей входа** (как в гостиницах и кафе) не подойдёт: нажать «Войти» рация не может.
- **Скрытая сеть** не появится в списке «Найти» — впишите её имя вручную.
- **Телефон всё ещё подключён к `RADIO-XXXX`.** Пока к точке доступа кто-то подключён, рация не пытается
  подключиться к Wi-Fi, чтобы не мешать настройке. Закончили — отключите телефон от неё.
- Рация помнит **до трёх сетей**; если добавить четвёртую, самая старая забудется.

Если Wi-Fi нет 15 минут и к её точке доступа никто не подключён, рация сама перезапускается — это нормально, так
она лечит «зависший» Wi-Fi.

### Рация не находит мост

**Признак:** мигают два оранжевых огонька; при нажатии кнопки — длинный низкий гудок и оранжевое мигание;
на странице рации — «ищу мост».

**Причины и что делать:**

1. **Поле «Адрес моста» пустое.** Тогда рация ищет мост только в своей сети (на странице: «Мост: ищу в своей
   сети»). Мост в интернете нужно вписать: `203.0.113.10`, `radio.example.com` или с портом —
   `radio.example.com:47000`. Порт по умолчанию 47000. Если мост и правда стоит в вашей сети, он должен быть в той же
   подсети, что рация, а в роутере не должна быть включена «изоляция клиентов» (в гостевых сетях она обычно есть) —
   иначе рация его не услышит.
2. **Имя моста не находится.** На странице рации — «Ошибка: адрес «…» не найден». Проверьте написание и запись DNS
   для имени (DNS — «телефонная книга» интернета, превращает имя в адрес).
3. **Мост не запущен.** Откройте страницу моста `http://203.0.113.10:47080/`. Не открывается — проверьте службу:
   на Linux `systemctl status walkie-hub` и `journalctl -u walkie-hub -f`, на Windows — файл `hub.log` рядом с
   `hub.json`.
4. **На сервере закрыт порт UDP 47000.** Установщики моста сами открывают его во встроенном брандмауэре (ufw на
   Linux, брандмауэр Windows), но у облачного сервера есть ещё **правила сети в консоли провайдера** — там
   UDP 47000 и TCP 47080 нужно разрешить вручную. Если мост стоит дома за роутером, на роутере нужен проброс
   этих портов на компьютер с мостом. Подробно — [BRIDGE.md](BRIDGE.md).
5. **Сеть рации не выпускает UDP.** Некоторые офисные и гостевые сети его режут. Проверьте рацию на раздаче
   с телефона.

Быстрая проверка с компьютера в той же сети, что рация:
`python3 hub/sim_radio.py --hub 203.0.113.10 --key XXXX-XXXX-XXXX-XXXX status`. Ответ «мост … ответил за N мс» — мост
и порт в порядке, ищите ошибку в настройках рации. «Мост … не ответил за 5 с» — дело в мосте, порте или сети.

### Не тот ключ сети

**Признак:** красные и фиолетовые огоньки через один; на странице рации — «мост отвечает, но ключ сети не
совпадает»; в журнале моста — «⚠ пакет раций с неверной подписью от … — не тот ключ сети?».

**Причина:** ключ в рации не совпадает с полем `key` в `hub.json` моста.

**Что делать:**

- Впишите в рацию тот же ключ, что в мосту. Регистр букв, пробелы и дефисы не важны: `k7q2 mx9p…` и
  `K7Q2-MX9P-…` — один и тот же ключ. Нужно не меньше 12 букв и цифр.
- **Только латинские буквы и цифры.** Прошивка считает в ключе только латиницу и цифры, а мост на Python —
  ещё и русские буквы, так что ключ с кириллицей у них никогда не совпадёт. Надёжнее всего взять ключ, который
  придумывает сам мост: `python3 hub/walkie_hub.py --genkey`.
- Поменяли ключ в `hub.json` — перезапустите мост: настройки он читает только при запуске.
- В рацию помещается ключ до 39 знаков вместе с дефисами — длиннее обрежется.
- У связанных мостов (`peers`) ключ тоже должен быть один на всех.

Если ключ не задан вовсе, рация держит точку доступа открытой (фиолетовое «дыхание»), на странице — «нет ключа
сети».

### Янтарные вспышки вместо зелёных

**Причина:** рация на связи со своим мостом, но какой-то мост из его списка `peers` недоступен. Рации на этом мосту
слышат друг друга, а рации за недоступным мостом — нет.

**Что делать:** на странице моста посмотрите раздел «Другие мосты» и журнал («⚠ мост пропал: …»). Проверьте, что
второй мост запущен, что мосты видят друг друга по UDP 47000 (через интернет или VPN) и что у них **разные имена**
(`name` в `hub.json`): по имени мост вычисляет свой номер, и мост с таким же именем он примет за самого себя.
См. [BRIDGE.md](BRIDGE.md).

### «бу-бу-бу» при нажатии, хотя никто не говорит

- Мост держит эфир за говорящим ещё 0,8 с после его последнего звука — нажмите чуть позже.
- Если в двух местах нажали одновременно, на всех мостах побеждает один и тот же говорящий, второму — «занято».
- Залипла кнопка у другой рации: мост сам отключит её передачу через 90 с. На странице моста видно, кто говорит.

### Звук прерывается, «булькает»

**Причина:** потери в сети — чаще всего слабый Wi-Fi у рации.

**Что делать:**

- На странице рации посмотрите сигнал Wi-Fi: −50 дБм — отлично, −70 дБм и хуже — слабо. Перенесите рацию
  ближе к роутеру или поставьте точку доступа.
- Антенна платы — выступ модуля без металлической крышки. Провода и металл к ней не прижимайте.
- Строка «Приём: сыграно / потеряно» на странице рации показывает, сколько кусочков речи по 20 мс потерялось.
  Подробнее разброс доставки покажет программная рация:
  `python3 hub/sim_radio.py --hub 203.0.113.10 --key XXXX-XXXX-XXXX-XXXX listen --seconds 60`.
- Рация копит 60–160 мс речи и после провалов сама берёт запас побольше.

---

## Звук

### Мост пишет «в передаче одна тишина — проверьте микрофон»

**Признак:** в журнале моста — «⚠ *имя рации*: в передаче одна тишина — проверьте микрофон», в списке раций —
«тишина в передачах: N». Другие рации слышат только тишину. Мост ставит это предупреждение, если передача длилась
больше 0,5 с, а уровень звука почти не поднимался над нулём.

**Самая частая причина — непропаянная ножка гребёнки на модуле микрофона**, чаще всего SCK. Провод «мама-мама»
надет на штырёк, на штырьке напряжение есть, а до самого модуля сигнал не доходит.

**Что делать.** Включите рацию и проверьте мультиметром (предел 20 В, чёрный щуп на GND) выводы микрофона INMP441.
Красный щуп ставьте **на пайку со стороны модуля**, а не на штырёк или колодку провода:

| Вывод микрофона | Должно быть |
|---|---|
| VDD | 3,3 В |
| SCK | ≈ 1,6 В (среднее от импульсов) |
| WS | ≈ 1,6 В |
| L/R | 0 В (соединён с GND) |

В неисправной рации на SCK у модуля не было ≈ 1,6 В, а на SD было ≈ 0. Пропаяйте заново **все шесть** ножек
гребёнки и проверьте ещё раз.

**Микрофон на правом канале.** Если на L/R не 0, а 3,3 В — микрофон отдаёт звук в правый канал, а прошивка
слушает левый. Либо соедините L/R с GND, либо поставьте на странице рации галочку «Микрофон на правом канале
(вывод L/R на 3,3 В)».

**Проверка без моста.** Командой `micraw` по USB (см. [Где искать подсказки](#где-искать-подсказки)) рация
покажет, что приходит с микрофона: `L: мин…макс  R: мин…макс`. Скажите что-нибудь и повторите команду: у
рабочего микрофона разброс на своём канале (L, если L/R на GND) заметно растёт от голоса. Оба канала стоят на одном
числе (`0…0`, `−1…−1`) — данных нет: проверьте пайку и провода SD → вывод 6, SCK → вывод 5, WS → вывод 4.

**Проверка целиком.** Запустите «попугая» (`sim_radio.py … echo`), скажите фразу и отпустите кнопку — должны
услышать себя. Или командой `testmic 10` отправьте в эфир 10 секунд живого микрофона без кнопки.

### Нет звука в динамике

**Сначала простое:**

- Громкость не на нуле: поверните регулятор — белая шкала должна расти.
- Звук не выключен: горит один фиолетовый огонёк или кольцо «дышит» голубым — нажмите на регулятор.
- На странице рации нет строки «Ошибка: звук не запустился (проверьте провода I2S)».
- Команда `show` по USB пишет «усилитель: MAX98357A (I2S)». Если там PAM8403, а стоит MAX98357A, — `amp i2s`.

**Частая причина при исправном питании — плохой контакт DIN или GND усилителя MAX98357A.** На одной из раций звук
появлялся, только пока щупы мультиметра прижимали эти выводы. Пропаяйте гребёнку усилителя заново.

**Проверка мультиметром** на выводах усилителя (чёрный щуп на GND). Чтобы звук шёл, передайте тон с компьютера
(`sim_radio.py … tone --seconds 20`) или покрутите регулятор — каждый шаг даёт щелчок:

| Вывод усилителя | Должно быть |
|---|---|
| Vin | 4,5–5 В |
| SD | ≈ 3,3 В, пока звучит звук и ещё 3 с после. В тишине прошивка усыпляет усилитель (чтобы не шипел) — тогда на SD 0 В, это нормально |
| BCLK, LRC | ≈ 1,6 В (среднее от импульсов) |

Ещё проверьте:

- динамик припаян к площадкам «+» и «−» **выхода** усилителя, и минус динамика **не** соединён с GND — у усилителя
  оба выхода рабочие;
- вывод GAIN усилителя ни к чему не подключён;
- провода: DIN → вывод 7, BCLK → вывод 15, LRC → вывод 16, SD → вывод 17.

### Собеседника слышно тихо или с хрипом

- По умолчанию включено «Автоусиление микрофона»: прошивка сама подстраивает усиление (до +36 дБ) и не даёт звуку
  перегружаться. Если его выключили, громкость микрофона задаёт поле «Усиление, если автоусиление выключено» —
  от 0 до 42 дБ, по умолчанию 24.
- Своя громкость — регулятором: 21 шаг (0–20) по 2 дБ.

### Свист, когда две рации рядом

**Причина:** акустическая петля. Микрофон говорящей рации слышит динамик соседней, звук идёт по кругу через мост
и на какой-то частоте нарастает в свист — так же свистят и обычные рации, если стоят рядом.

**Что делать:** прошивка сама находит растущий свист и вырезает его частоту узким фильтром; если свист повторяется
в той же передаче, она ещё и убавляет микрофон. На странице рации видно, сработала ли защита: «Свист рядом
с другой рацией: гасили N раз, последний на … Гц». Но лучше не доводить: разнесите рации или убавьте громкость на
слушающей.

---

## Кольцо и регулятор

### Кольцо не горит

- «Яркость подсветки» на странице рации стоит на 0 — поднимите (по умолчанию 60).
- Не загорелось ни разу за 10 секунд после включения — проверьте тумблер и клемму 5 В.
- Провод данных должен идти с вывода 18 на вход кольца **DI** (DIN), а не на выход DO.

### Кольцо мигает «не теми» цветами

**Причина:** нет диода 1N4007 в проводе питания 5 В кольца (или он стоит наоборот). Светодиоды WS2812 при питании
ровно 5 В плохо понимают сигнал 3,3 В от платы; диод снижает их питание примерно до 4,3 В, и сигнал читается
надёжно.

**Что делать:** поставьте диод в разрыв провода 5 В кольца, **полоской к кольцу**.

### Регулятор крутится наоборот

Поставьте на странице рации галочку **«Регулятор крутится наоборот»**. Или поменяйте местами провода CLK и DT:
по схеме CLK → вывод 2, DT → вывод 42 — тогда по часовой стрелке громче.

### Регулятор не реагирует

Проверьте провода: CLK → вывод 2, DT → вывод 42, SW → вывод 41, «+» → **3V3** (только 3,3 В, не 5 В!),
GND → G на плате. Нажатие на ручку должно щёлкать: насаживайте ручку на вал с зазором 1,5–2 мм над торцом
втулки.

---

## Питание и заряд

### Рация «выключается сама» в простое

**Признак:** рация лежала без дела и погасла совсем — кольцо тёмное, на кнопки не отвечает.

**Причина:** модуль заряда устроен как пауэрбанк. Если рация берёт слишком мало тока, модуль решает, что нагрузку
отключили, и выключает выход 5 В. Поэтому «Экономия аккумулятора» (Wi-Fi дремлет, пока в эфире тихо) **по умолчанию
выключена**.

**Что делать:** не включайте экономию с такими модулями. Если галочка стоит — снимите её на странице рации.

Если рация не гаснет, а **перезапускается**, посмотрите на странице строку «Работает … · запуск: …»:

| Причина запуска | Что значит |
|---|---|
| включение питания | обычное включение тумблером |
| просадка питания | напряжение на мгновение упало. Сразу после включения тумблером — нормально (см. ниже). Посреди работы — садится аккумулятор или плохой контакт в клеммах |
| сторож: зависание | программа не отвечала 30 с, сторож перезапустил рацию |
| сбой программы | ошибка в прошивке — сохраните журнал по USB и приложите его к сообщению об ошибке (issue) в репозитории |
| перезапуск программой | после обновления прошивки, кнопки «Перезапустить» или команды `reboot`, сброса настроек, смены усилителя, добавления сети через точку доступа или 15 минут без Wi-Fi |

### Рация перезагружается от тряски

**Причина:** провод плохо держится в клемме. Тонкая жила провода «мама-мама» в клемме на 5 проводов держится
ненадёжно.

**Что делать:** зачистите конец на 20–22 мм, сложите жилу вдвое и плотно скрутите — получится двойной кончик
10–11 мм. Вставьте до упора, закройте рычажок и подёргайте: провод не должен выходить.

### После замены аккумулятора тумблер не включает рацию

**Причина:** вынули и вставили аккумулятор — модуль заряда «уснул» и не включает выход 5 В.

**Что делать:** подключите на пару секунд зарядку USB-C. Если на модуле есть кнопка — можно нажать её.

### Огоньки модуля заряда не гаснут после выключения тумблера

Прошивкой это не лечится: плата в этот момент обесточена. Возможные причины:

- подключена зарядка — тогда огоньки и должны гореть;
- модуль перешёл в режим «малый ток» (у некоторых модулей он включается сам);
- что-то подключено к выходу модуля в обход тумблера — проверьте, что выход OUT+ идёт **только** на тумблер;
- модуль другой серии — ведёт себя по-своему.

Такой модуль понемногу разряжает аккумулятор и в выключенной рации. Вариант переделки: перенести тумблер на провод
аккумулятора (между держателем 18650 и площадкой B+ модуля). Тогда в выключенной рации модуль обесточен полностью,
но заряжается аккумулятор только при включённом тумблере.

### На выключенной рации на линии 5 В 0,4–0,5 В

Нормально. Это остаточный заряд конденсаторов и микроток через делитель заряда (два резистора по 100 кОм —
сотые доли миллиампера). Напряжение медленно падает; аккумулятор это не сажает.

### «Причина запуска: просадка питания» после включения тумблером

Нормально: в момент включения заряжаются конденсаторы на платах, и напряжение на долю секунды проседает. На работу
рации это не влияет.

### Заряд показывает «измеряется…» или не меняется

Так задумано: под нагрузкой (Wi-Fi, динамик, кольцо) напряжение аккумулятора проседает на 0,2–0,3 В, и честный
замер в этот момент показал бы заниженный заряд. Правила оценки (подробно — в
[firmware/walkie/battery_est.h](../firmware/walkie/battery_est.h)):

- **Первые ≈ 20 с после включения** заряд не сообщается — «измеряется»: 15 с рация не берёт замеры (Wi-Fi
  подключается на полной мощности), потом копит 5 спокойных замеров.
- **Во время разговора и приёма**, а также при обновлении прошивки и поиске Wi-Fi замеры не берутся — и ещё 3 с
  после. Заряд на это время замирает, а после паузы сразу догоняет. Если рация «занята» дольше 5 минут без перерыва,
  замеры всё равно берутся — чтобы разряд не остался незамеченным.
- Замер — раз в секунду; оценка — наибольший из последних 30 спокойных замеров. Вверх она идёт сразу, вниз —
  плавно, поэтому короткие провалы напряжения не сбивают проценты.
- **«Пора на зарядку»** (красные вспышки и три ноты вниз) — только если заряд 15 % и меньше держится 30 с подряд.
  Снимается, когда заряд поднимется до 18 %.
- Проценты — грубая шкала напряжения: 3,30 В — 0 %, 4,15 В — 100 %.
- Во время зарядки проценты завышены: под зарядом напряжение выше. Точное значение — после отключения кабеля.

Сырой последний замер покажет команда `show` по USB («замер N мВ»). Если проценты сильно расходятся с
напряжением на аккумуляторе по мультиметру — проверьте, что оба резистора делителя по 100 кОм.

### Заряд всегда «нет (питание от USB)»

**Причина:** на выводе 8 меньше 2,5 В в пересчёте на аккумулятор — прошивка считает, что аккумулятора нет.

**Что делать:** проверьте делитель: резисторы 100 кОм к площадкам **B+** и **B−** модуля заряда (не к OUT+),
середина делителя — проводом на вывод 8. На выводе 8 должно быть около половины напряжения аккумулятора
(1,6–2,1 В). Без делителя рация работает, но не узнает, что садится аккумулятор.

---

## USB и прошивка

### Плата не видна по USB или «No serial data received»

- **Кабель только для зарядки** — возьмите кабель с передачей данных.
- **Гнездо COM не работает с кабелем C–C.** У некоторых плат в гнезде COM нет нужных резисторов, и от кабеля
  USB-C — USB-C плата даже не получает питание. Подключайтесь к гнезду **USB** (родной порт ESP32-S3) или кабелем
  USB-A — USB-C.
- **Войдите в загрузчик вручную:** зажмите кнопку **BOOT**, нажмите и отпустите **RST**, отпустите BOOT. Теперь
  прошивайте. Если после прошивки через гнездо USB плата осталась в загрузчике — нажмите RST.
- На Windows может понадобиться драйвер чипа USB-UART, через который работает гнездо COM (на платах-клонах
  это обычно CH340 или CH343).

Как прошивать — [SETUP.md](SETUP.md).

### Прошивка не обновляется по воздуху

Рация скачивает новую прошивку с моста, только когда выполнено всё сразу:

- номер в `walkie.json` на мосту **больше**, чем версия рации (её видно на странице рации, в разделе «Прошивка»);
- рация на связи с мостом и 20 секунд никто не говорил;
- рации доступен **TCP 47080** моста — прошивка скачивается оттуда. Закрыт порт — не будет и обновления;
- прошлая попытка не провалилась меньше часа назад. После неудачи рация ждёт час; перезапустите её, чтобы
  попробовать сразу.

На странице моста должна быть строка «прошивка для раций: версия N»; когда рация качает файл, в журнале —
«рация … скачивает прошивку N», а на кольце растёт синяя полоса. Мост перечитывает папку `firmware/` каждые 10 с.

Вручную: страница рации → «Загрузить прошивку» → файл **`walkie.bin`**. Не путайте с `walkie-full-v…bin` — тот только
для первой прошивки по кабелю с адреса 0x0.

### Страница рации не открывается

- Компьютер или телефон должен быть в той же сети Wi-Fi, что рация.
- `http://radio-xxxx.local` открывается не везде (часто не открывается на Android) — найдите адрес рации
  в списке устройств роутера или командой `show` по USB.
- Всегда работает точка доступа: держите кнопку «говорить» при включении, подключитесь к `RADIO-XXXX`, откройте
  `http://192.168.4.1`. Точка, открытая кнопкой, работает до выключения рации.

### Сбросить настройки

- **Регулятором:** держите нажатым 10 секунд. С 5-й секунды кольцо мигает красным — отпустите, если передумали.
  Сбрасываются сети Wi-Fi, громкость, яркость и прочие настройки звука и кольца. **Ключ сети, имя рации и адрес
  моста остаются**, чтобы рацию можно было вернуть в эфир, просто введя Wi-Fi с телефона.
- **Полностью**, включая ключ и адрес моста, — командой `factory` по USB.

---

## Мост

### Страница моста не открывается

- Закрыт **TCP 47080** — в брандмауэре сервера или в правилах сети у облачного провайдера.
- Ответ «нужен ?t=<токен>» — в `hub.json` задан `status_token`; допишите к адресу `?t=` и сам токен.
- Рации работают и без страницы, но обновление по воздуху идёт через тот же порт 47080.

### Мост не запускается или перезапускается

- Linux: `journalctl -u walkie-hub -f`. Служба перезапускает мост при сбое, а самопроверка раз в 2 минуты
  перезапускает его, если он перестал отвечать (`journalctl -t walkie-hub` — «мост не ответил на самопроверку —
  перезапуск»).
- Windows: файл `hub.log` рядом с `hub.json`; задача Планировщика называется `WalkieHub`.
- `hub.json` должен быть правильным JSON и содержать `key`.
- Не запускайте вторую копию моста рядом с работающей службой: порты 47000 и 47080 должны быть свободны.
  Вторая копия либо не запустится («Address already in use»), либо будет мешать первой.

Установка и настройка моста — [BRIDGE.md](BRIDGE.md).

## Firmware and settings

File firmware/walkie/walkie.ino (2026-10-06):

// WiFi-рация Ай-Шефф — прошивка для ESP32-S3.
//
// Нажал кнопку → короткий «бип» → говоришь; отпустил — все остальные рации слышат.
// Связь через мост (hub/walkie_hub.py): рации в разных Wi-Fi-сетях (дом, магазин) слышат друг друга.
//
// Сборка: tools/build_firmware.sh (arduino-cli, ядро esp32 3.3.12, плата ESP32S3 Dev Module).
// Настройка с компьютера по USB: tools/provision.py; команды в мониторе порта — «help».
// ВАЖНО: функции в этом файле объявлять ДО использования — сборка идёт без ctags (см. build_firmware.sh).
#include <WiFi.h>
#include <esp_system.h>
#include <esp_task_wdt.h>
#include <stdarg.h>
#include "audio.h"
#include "battery.h"
#include "config.h"
#include "crypto.h"
#include "net.h"
#include "settings.h"
#include "state.h"
#include "ui.h"
#include "web.h"
#include "wifi_mgr.h"

Status g_st;

void flash(Flash f) {
  g_st.flash_ms = millis();
  g_st.flash = f;
}

// Журнал — в оба USB-разъёма платы: Serial0 = «COM» (через мост-чип), Serial = «USB» (родной порт ESP32-S3)
void logf(const char* fmt, ...) {
  char buf[200];
  va_list ap;
  va_start(ap, fmt);
  vsnprintf(buf, sizeof(buf), fmt, ap);
  va_end(ap);
  unsigned long t = millis();
  Serial0.printf("[%5lu.%01lu] %s\n", t / 1000, (t % 1000) / 100, buf);
  if (Serial) Serial.printf("[%5lu.%01lu] %s\n", t / 1000, (t % 1000) / 100, buf);
}

static uint32_t make_id() {
  uint64_t mac = ESP.getEfuseMac();
  uint32_t h = 2166136261u;                 // FNV-1a по 6 байтам MAC
  for (int i = 0; i < 6; i++) {
    h ^= (uint8_t)(mac >> (8 * i));
    h *= 16777619u;
  }
  return h ? h : 1;
}

// ─────────────── команды по USB ───────────────

static void print_status(Print& o) {
  o.printf("id %08X  имя «%s»  прошивка %d\n", (unsigned)g_st.id, g_set.name, FW_VERSION);
  o.printf("мост: %s  адрес в настройках: «%s»  ключ: %s\n", g_st.hub_addr, g_set.server,
           g_set.netkey[0] ? "задан" : "НЕТ");
  o.printf("связь: %d  Wi-Fi: %s %s %d дБм  задержка %u мс  раций в сети %u\n", (int)g_st.link,
           WiFi.SSID().c_str(), WiFi.localIP().toString().c_str(), WiFi.RSSI(), g_st.rtt_ms, g_st.radios_online);
  for (int i = 0; i < WIFI_SLOTS; i++)
    if (g_set.wifi[i].ssid[0]) o.printf("сеть %d: «%s»\n", i, g_set.wifi[i].ssid);
  o.printf("аккумулятор %u%% %u мВ (замер %u мВ)  экономия Wi-Fi %s\n", g_st.bat_pct, g_st.bat_mv, g_st.bat_raw_mv,
           g_st.eco ? "сейчас" : "нет");
  o.printf("усилитель: %s\n", g_set.amp_pdm ? "PAM8403 (PDM через фильтр)" : "MAX98357A (I2S)");
  o.printf("громкость %u  АРУ %d  приём: сыграно %u потеряно %u опоздало %u провалов %u  чужих пакетов %u\n",
           g_set.volume, g_set.agc, (unsigned)g_st.rx_played, (unsigned)g_st.rx_lost, (unsigned)g_st.rx_late,
           (unsigned)g_st.rx_underrun, (unsigned)g_st.bad_packets);
}

static uint32_t s_testtx_until = 0;      // служебная проверка передачи: когда отпустить «кнопку»

static void command(String line, Print& o) {
  line.trim();
  if (!line.length()) return;
  int sp = line.indexOf(' ');
  String cmd = sp < 0 ? line : line.substring(0, sp);
  String arg = sp < 0 ? String() : line.substring(sp + 1);
  arg.trim();
  cmd.toLowerCase();
  if (cmd == "help") {
    o.println("show | name <имя> | server <адрес[:порт]|auto> | key <ключ> | wifi <сеть>|<пароль> | wifi-clear");
    o.println("volume <0..20> | agc on|off | led <0..100> | amp i2s|pdm | testtx <с> [Гц] | testmic <с> | micraw | reboot | factory");
  } else if (cmd == "show") {
    print_status(o);
  } else if (cmd == "name" && arg.length()) {
    strlcpy(g_set.name, arg.c_str(), sizeof(g_set.name));
    settings_save();
    o.println("OK name");
  } else if (cmd == "server") {
    strlcpy(g_set.server, arg == "auto" ? "" : arg.c_str(), sizeof(g_set.server));
    settings_save();
    net_server_changed();
    o.println("OK server");
  } else if (cmd == "key") {
    if (crypto_key_valid(arg.c_str())) {
      strlcpy(g_set.netkey, arg.c_str(), sizeof(g_set.netkey));
      settings_save();
      net_server_changed();
      o.println("OK key");
    } else {
      o.println("ERR key: нужно не меньше 12 букв и цифр");
    }
  } else if (cmd == "wifi") {
    int bar = arg.indexOf('|');
    String ssid = bar < 0 ? arg : arg.substring(0, bar);
    String pass = bar < 0 ? String() : arg.substring(bar + 1);
    if (wifi_add(ssid.c_str(), pass.c_str())) {
      wifi_reconnect();
      o.println("OK wifi");
    } else {
      o.println("ERR wifi");
    }
  } else if (cmd == "wifi-clear") {
    for (int i = WIFI_SLOTS - 1; i >= 0; i--) wifi_remove(i);
    o.println("OK wifi-clear");
  } else if (cmd == "volume") {
    g_set.volume = constrain(arg.toInt(), 0, 20);
    settings_save();
    o.println("OK volume");
  } else if (cmd == "agc") {
    g_set.agc = arg == "on";
    settings_save();
    o.println("OK agc");
  } else if (cmd == "amp") {
    g_set.amp_pdm = arg == "pdm";
    settings_save();
    o.println(g_set.amp_pdm ? "OK amp pdm (PAM8403), перезапуск" : "OK amp i2s (MAX98357A), перезапуск");
    delay(100);
    ESP.restart();
  } else if (cmd == "led") {
    g_set.led = constrain(arg.toInt(), 0, 100);
    settings_save();
    o.println("OK led");
  } else if (cmd == "reboot") {
    o.println("OK reboot");
    delay(100);
    ESP.restart();
  } else if (cmd == "testtx") {
    // testtx <секунды> [Гц] — как будто нажали кнопку и в микрофон звучит тон (проверка без микрофона и кнопки)
    int sec = constrain(arg.length() ? arg.toInt() : 3, 1, 20);
    int sp = arg.indexOf(' ');
    int hz = sp > 0 ? constrain(arg.substring(sp + 1).toInt(), 100, 4000) : 1000;
    audio_test_tone(hz);
    net_ptt(true);
    s_testtx_until = millis() + sec * 1000UL;
    o.printf("OK testtx %d с, %d Гц\n", sec, hz);
  } else if (cmd == "testmic") {
    // testmic <секунды> — как будто держат кнопку: в эфир идёт живой микрофон (проверка без кнопки)
    int sec = constrain(arg.length() ? arg.toInt() : 10, 1, 80);
    audio_test_tone(0);
    net_ptt(true);
    s_testtx_until = millis() + sec * 1000UL;
    o.printf("OK testmic %d с\n", sec);
  } else if (cmd == "micraw") {
    // сырые отсчёты микрофона за прошедшее время: оба канала (L — вывод L/R на G, R — на 3,3 В)
    int32_t mn[2], mx[2]; uint32_t n;
    audio_mic_raw(mn, mx, n);
    delay(1000);
    audio_mic_raw(mn, mx, n);
    o.printf("OK micraw кадров %u  L: %ld…%ld  R: %ld…%ld\n", (unsigned)n, (long)mn[0], (long)mx[0], (long)mn[1], (long)mx[1]);
  } else if (cmd == "factory") {
    settings_factory_reset(true);
    o.println("OK factory");
    delay(100);
    ESP.restart();
  } else {
    o.println("ERR неизвестная команда (help)");
  }
}

static void serial_poll(Stream& s, String& buf) {
  while (s.available()) {
    char c = (char)s.read();
    if (c == '\n' || c == '\r') {
      if (buf.length()) command(buf, s);
      buf = "";
    } else if (buf.length() < 200) {
      buf += c;
    }
  }
}

// ─────────────── старт ───────────────

static const char* reset_name(esp_reset_reason_t r) {
  switch (r) {
    case ESP_RST_POWERON: return "включение питания";
    case ESP_RST_SW: return "перезапуск программой";
    case ESP_RST_PANIC: return "сбой программы";
    case ESP_RST_INT_WDT:
    case ESP_RST_TASK_WDT:
    case ESP_RST_WDT: return "сторож: зависание";
    case ESP_RST_BROWNOUT: return "просадка питания";
    case ESP_RST_EXT: return "кнопка RST";
    case ESP_RST_USB: return "по USB";
    default: return "другое";
  }
}

void setup() {
  Serial0.begin(115200);
  Serial.begin();
  Serial.setTxTimeoutMs(0);            // не ждать, если к «родному» USB никто не подключён
  g_st.id = make_id();
  snprintf(g_st.host, sizeof(g_st.host), "radio-%04x", (unsigned)(g_st.id & 0xFFFF));
  settings_load();
  crypto_set_key(g_set.netkey);
  g_st.boot_reason = reset_name(esp_reset_reason());
  logf("WiFi-рация, прошивка %d, id %08X, имя «%s», запуск: %s", FW_VERSION, (unsigned)g_st.id, g_set.name,
       g_st.boot_reason);
  // сторож: зависнут цикл рации или задача сети дольше 30 с — перезапуск и снова в сеть (29.09 рация 1 перестала
  // отвечать в простое; была ли это прошивка или модуль заряда — теперь видно на странице рации: «запуск: …»)
  esp_task_wdt_config_t wdt = {.timeout_ms = WDT_TIMEOUT_MS, .idle_core_mask = 0, .trigger_panic = true};
  if (esp_task_wdt_reconfigure(&wdt) != ESP_OK) esp_task_wdt_init(&wdt);
  enableLoopWDT();

  setCpuFrequencyMhz(CPU_MHZ);         // 160 МГц хватает с запасом, батарея живёт дольше
  battery_begin();
  ui_begin();
  bool force_portal = ui_ptt_held_at_boot();
  if (force_portal) logf("кнопка зажата при включении — режим настройки");
  if (!audio_begin()) strlcpy(g_st.last_error, "звук не запустился (проверьте провода I2S)", sizeof(g_st.last_error));
  wifi_begin(force_portal);
  net_begin();
  web_begin();
}

void loop() {
  static String b1, b2;
  ui_loop();
  wifi_loop();
  web_loop();
  settings_tick();
  battery_loop();
  serial_poll(Serial0, b1);
  serial_poll(Serial, b2);
  if (s_testtx_until && (int32_t)(millis() - s_testtx_until) >= 0) {
    s_testtx_until = 0;
    net_ptt(false);
    audio_test_tone(0);
  }
  delay(2);
}

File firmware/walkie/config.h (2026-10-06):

// Настройки сборки WiFi-рации. Выводы — для платы ESP32-S3-DevKitC-1 (и клонов YD-ESP32-S3).
#pragma once

#define FW_VERSION 9            // целое; мост раздаёт рациям прошивку с бо́льшим номером

// ── Микрофон INMP441 (разводка как в популярной сборке xiaozhi «bread-compact») ──
#define PIN_MIC_WS 4
#define PIN_MIC_SCK 5
#define PIN_MIC_SD 6
// ── Усилитель MAX98357A ──
#define PIN_AMP_DIN 7
#define PIN_AMP_BCLK 15
#define PIN_AMP_LRC 16
#define PIN_AMP_SD 17           // HIGH — усилитель работает, LOW — спит (нет шипения)
// ── Или аналоговый усилитель PAM8403 (настройка amp_pdm): звук импульсами PDM на вывод 7 →
//    фильтр 10 кОм / 1 кОм / 22 нФ → 1 мкФ → вход L усилителя. Вывод 15 драйверу нужен, но никуда не идёт ──
#define PIN_PDM_OUT PIN_AMP_DIN
#define PIN_PDM_CLK PIN_AMP_BCLK
// ── Кольцо WS2812 вокруг кнопки ──
#define PIN_LED 18
#define LED_COUNT 12
// ── Кнопка «говорить» (замыкает на GND) ──
#define PIN_PTT 1
// ── Регулятор громкости KY-040 (питать ТОЛЬКО от 3,3 В!) ──
#define PIN_ENC_A 2             // CLK
#define PIN_ENC_B 42            // DT
#define PIN_ENC_SW 41           // SW — нажатие: выключить/включить звук
// ── Аккумулятор: делитель 100 к + 100 к от «+» аккумулятора на GPIO8 (АЦП1) ──
#define PIN_BAT 8
#define BAT_DIVIDER 2.0f        // (R1 + R2) / R2
#define BAT_LOW_PCT 15          // предупредить
#define BAT_CRIT_PCT 5          // предупреждать чаще

#define DEFAULT_SERVER ""   // адрес своего моста можно вписать сюда; пусто — задать в настройках рации (или мост ищется в своей сети)
#define AP_PREFIX "RADIO-"      // имя точки доступа для настройки: RADIO-XXXX
#define LOCAL_PORT 47001

// ── Звук ──
#define AGC_TARGET_RMS 3000.0f  // ≈ −21 дБ от полной шкалы
#define AGC_GATE_RMS 20.0f      // тише — это тишина, усиление не поднимаем
#define AGC_MIN_DB 0.0f
#define AGC_MAX_DB 36.0f
#define TALK_LIMIT_MS 100000    // своя защита от залипшей кнопки (мост режет на 90 с)
#define WDT_TIMEOUT_MS 30000   // сторож: цикл рации или задача сети молчат дольше — перезапуск
#define ECO_IDLE_MS 15000       // столько тишины — Wi-Fi в режим экономии (батарея живёт в 2–3 раза дольше)
#define CPU_MHZ 160

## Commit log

2026-10-06 Wi-Fi Radio Ai-Sheff: рации «нажал — говоришь» на ESP32-S3 через свой мост
    Прошивка, мост на Python, корпус для 3D-печати (OpenSCAD + STL), готовая прошивка,
    инструкции: сборка, прошивка и настройка, свой мост, неполадки.
    [back.stl, coupon.stl, dk_arm.stl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]
2026-10-06 README: без пометки «не измерялось», без подсказки про смену надписи и без раздела «Благодарности»; BUILD: без строки про текст надписи
2026-10-06 English documentation: README.en.md, docs/en/ (build, setup, bridge, troubleshooting, protocol), English diagrams; language switch on every page
